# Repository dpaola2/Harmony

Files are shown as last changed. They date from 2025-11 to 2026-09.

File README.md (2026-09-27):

# Offline MP3 Player (Harmony2)

Hardware-agnostic MP3 player core with a PC simulator and ESP32 targets. See `docs/README.md` for the doc map; hardware bring-up for Prototype 1 is in `hardware/prototype1/README.md`.

## Current Mark-6 build

The active player uses native ESP-IDF firmware on the Adafruit ESP32 Feather V2. The Python/MicroPython architecture below is retained historical context.

- [Feather bench firmware and instructions](firmware/mark-6/feather-player-bench/README.md)
- [Native UI and renderer](firmware/mark-6/feather-carrier/main/)
- [UI requirements and completion status](docs/Harmony-player-ui-requirements.md)
- [Desktop UI prototype](platforms/pc/ui/README.md)
- [Preserved Mark-7 visual reference](docs/mark-7-design-reference.md)
- [Changelog](CHANGELOG.md)

## Architecture & Goals
- Core app logic in Python, shared by PC simulator and MicroPython on ESP32.
- iPod-style UI: Library → Now Playing → Settings with tactile buttons (no touch).
- Portable storage (SD) and Bluetooth audio on hardware targets; PC sim for fast iteration.
- More context: `PROJECT_OVERVIEW.md` (goals/constraints) and `PLAN.md` (roadmap).

## Development
- **Environment (macOS)**:
  - Install Homebrew if missing: `/bin/bash -c "$(curl -fsSL https://raw.githubusercontent.com/Homebrew/install/HEAD/install.sh)"`.
  - Python: `brew install python` (or `pyenv` if you prefer pinned versions).
  - Recommended tooling: `pipx install uv` (or `pip install uv` in a venv); `pipx ensurepath`.
  - Create venv: `python -m venv .venv && source .venv/bin/activate`.
  - Install dev deps: `python -m pip install --upgrade pip uv pytest`.

- **Run PC simulator** (console UI):
  ```bash
  source .venv/bin/activate
  python -m platforms.pc.main_pc [--music-dir /path/to/Artist/Album/Track.ext]
  ```
  Controls: `w/s` up/down, `a` left, `d` right, `space`/Enter select, `p` play/pause, `b` or `q` back, `x` quit, `+`/`=` volume up, `-` volume down. Defaults to an in-memory demo library.

- **Tests**:
  ```bash
  source .venv/bin/activate
  pytest
  ```
  (Targets `core/` behavior.)

- **ESP32 Prototype 1 upload (demo UI, no buttons required)**:
  - See `hardware/prototype1/README.md` for wiring and flashing details.
  - Convenience script from repo root:
    ```bash
    scripts/upload_proto1_demo.sh /dev/tty.usbmodem*   # adjust port as needed
    ```
    It copies `core/`, `platforms/esp32/*.py`, and `main_esp32.py` to the board and keeps `main.py` as entrypoint.

## Repo structure
- `core/` hardware-agnostic logic and models
- `platforms/pc/` PC simulator (console screen, keyboard input, audio backend)
- `platforms/esp32/` ESP32 adapters (screen, buttons, audio)
- `hardware/` wiring/board notes (prototype phases)
- `enclosure/` mechanical notes
- `tests/` pytest cases for `core/`

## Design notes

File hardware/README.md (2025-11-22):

# Hardware Notes

## Prototypes
- Prototype 1: ESP32-S3-WROOM DevKitC-1 v1.1, SD SPI, ST7789V2 (1.69", 240x280), basic buttons, USB power. No audio/A2DP (S3 WROOM lacks classic BT); focus on UI/SD/display.
- Prototype 2: ESP32-WROVER DevKitC (PSRAM, classic BT) for audio/A2DP; SD SPI, ST7789 (2.0–2.4"), rotary encoder + buttons, optional I2S DAC/amp; USB or LiPo/TP4056 later.

## Volume Input Options
- Buttons: dedicated volume up/down buttons produce relative events; core clamps 0–100 and calls `set_volume`.
- Encoder-as-volume: use a second rotary (or mode switch) to emit relative steps; map to the same core events.
- Absolute knob (potentiometer): yields an analog value; platform adapter should translate ADC reading to a clamped 0–100 and push into core via `set_volume` (core supports absolute level set).

## Power System
- Battery: LiPo 1000–2000 mAh flat cell.
- Charging: TP4056 (USB-C variant) for LiPo charging.
- Regulation: ESP32 dev board regulator or MT3608 step-up if 5V needed for peripherals.
- Power switch: SPDT slide/lockable on/off.
- Optional: battery voltage sensing via ADC for future battery UI; plan GPIO and resistor divider.

## Notes/Next Steps
- Wiring: document GPIO mapping for encoder, buttons, SD (SPI), display (SPI), and optional I2S pins.
- Bluetooth A2DP: confirm ESP32 MicroPython support vs ESP-IDF shim; may need C-extension for stable source mode.
- Settings persistence: volume, last track, etc., stored in flash/SD (JSON) on device; core ready once adapters persist/load.

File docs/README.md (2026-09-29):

# Documentation Map

This repo keeps a small set of living docs, each with a clear purpose. Use this map to find or add information without duplicating content.

## September 2026 device proposal

- [Firmware baseline](../firmware/README.md): verified ESP32/SAMD builds, scripts, source pins, and hardware validation limits.
- [Board reconciliation](../hardware/procurement/reconciliation/tangara-interface-bom-reconciliation.md): PCB component inventory and exact battery/display interfaces.

- [Shopping list](../hardware/procurement/README.md): current sources, quantities, costs, and compatibility holds.
- [Implementation plan](Harmony-2026-implementation-plan.md): stages, review decisions, and acceptance tests.

- [Approach reassessment](Harmony-2026-reassessment.md): recommendation against the updated device goals.
- [Technical basis](Harmony-2026-technical-basis.md): options, architecture, sourcing limits, and acceptance criteria.
- [Printable case](../enclosure/harmony-r1/README.md): Tangara-based fit prototype for the Bambu A1.

## Current Mark-7 scope

- [Portable build scope](mark-7-portable-scope.md): adopted September 28 reuse, internal SD access, perfboard assembly, power work and acceptance.

## Current player UI

- [Mark-6 lessons and portable next step](mark-6-lessons-and-portable-next-step.md): battery proof, carrier tradeoffs and proposed Mark-7 purpose.

- [Changelog](../CHANGELOG.md): dated implementation, fixes and validation.
- [Mark-7 visual reference](mark-7-design-reference.md): frozen desktop appearance and capacitive-wheel/battery design direction.

- [Native Feather UI bench](../firmware/mark-6/feather-player-bench/README.md): device music tree, Now Playing, controls, and current limits.

- [Interactive desktop prototype](../platforms/pc/ui/README.md): run the 320 × 480 menu and wheel simulation using the 45-track trial library.
- [Player UI requirements](Harmony-player-ui-requirements.md): Accepted Mark-6 scope (HARMONY-18), covering music navigation, controls, volume, and Bluetooth management on the verified Feather bench.

## Core docs
- `PROJECT_OVERVIEW.md` — why the project exists, constraints, and hardware/software goals.
- `PLAN.md` — roadmap and near-term milestones; keep current sprint items at the top.
- `TASKS.md` — live task queue and in-flight gameplans (per callsign).
- `docs/gameplans/` — archived or long-form gameplans by callsign (move sections here once done or if they get lengthy).
- `AGENTS.md` — roles, responsibilities, and collaboration rules. Update only when roles change.

## Platform & hardware
- `platforms/pc/` — PC simulator code; add a `README.md` here if setup diverges from the root README.
- `platforms/esp32/` — MicroPython adapters for ESP32 targets.
- `hardware/prototype1/README.md` — Prototype 1 wiring, bring-up, and testing (ESP32-S3 DevKitC-1 v1.1).
- `hardware/prototype2/README.md` — Prototype 2 notes (WROVER/audio) when ready.
- `hardware/production/` — production-focused notes and (later) BOM/PCB details.
- `enclosure/` — mechanical/3D-print notes.

## Testing & running
- Root `README.md` — quickstart for macOS dev setup, how to run the PC simulator, and how to run tests.
- Platform-specific run/test steps live in the relevant platform or hardware README (e.g., `hardware/prototype1/README.md` for flashing and device tests).

## How to handle gameplans and tasks
- Active gameplans: keep with their callsigns in `TASKS.md` so they are visible during execution.
- Short-term roadmap: keep in `PLAN.md` and cross-link to detailed gameplan sections in `TASKS.md`.
- Archive: move completed/obsolete task or gameplan sections from `TASKS.md` into `docs/gameplans/<callsign>.md`, noting the callsign and date if helpful.
- Long-form design notes: if a gameplan gets large, place it under `docs/gameplans/<callsign>.md` and link it from `TASKS.md` and `PLAN.md`.

## Cross-linking
- Each doc should include brief “see also” pointers to adjacent docs (e.g., `README.md` → `PLAN.md`, `TASKS.md`, relevant platform README).
- Avoid duplicating content; link instead. Keep summaries at the top of each doc to speed up navigation.

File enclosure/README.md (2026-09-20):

# Harmony enclosure

The [Harmony R1 case](harmony-r1/README.md) contains printable STL and 3MF parts, editable CAD, assembly instructions, and validation results for the proposed Tangara-based device. Start with the fit-test plate.

See the [September 2026 approach reassessment](../docs/Harmony-2026-reassessment.md) before sourcing electronics. The case is a digital fit prototype; physical validation is pending.

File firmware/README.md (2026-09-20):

# Harmony firmware baseline

On September 14, 2026, the unmodified Tangara ESP32 application, SAMD21 application, and SAMD21 bootloader all built successfully on Dave's Mac. The ESP32/SAMD register maps and control bits match at source level. This removes a build-toolchain uncertainty in the proposed Tangara approach. It does not establish that an assembled Harmony works.

| Build | Source pin | Result |
| --- | --- | --- |
| ESP32 application and IDF bootloader | `c092c5aae83aac241b3756b15d8b9dad9ed2c3fd`; ESP-IDF `8c750b088c7cd857d079c0eeb495da199b359461` | Passed; application 2,684,736 bytes, 36% partition space free |
| SAMD21 application v6.0 | `8066c54bff5d26398fa08955d2bc24e7f05702a2` | Passed; BIN, ELF and UF2 retained |
| Tangara SAMD21 bootloader | `bc1632d9736493467000ba119fd0b16fd46ccbe6` | Passed; raw factory image and existing-device updater retained |

Read the [ESP32 verification](esp32-validation/README.md) and [SAMD21 verification](samd-validation/README.md) for build commands, compiler versions, logs, hashes, and programming requirements. Both source checkouts remain unmodified. Toolchains are isolated under `firmware/toolchains`; no serial-port or flash commands were run. The existing Python simulator was not changed or retested.

Sol subagents built/reviewed the SAMD baseline and reconciled the board interfaces while the primary agent built the ESP32 baseline. The primary review caught and corrected build-script failure handling and checksum regeneration before accepting the SAMD deliverable.

## What this establishes

The ESP32 image checksum is valid; all seven ESP32 flash images fit the configured 16 MiB device without overlap. SAMD v6.0 and the ESP32 driver share I2C address `0x45`, registers 0–5 for version/status/control, and matching shutdown, fast-charge, mass-storage and UF2-reset bits. The SAMD application starts at `0x2000`, after the 8 KiB bootloader region. A blank SAMD still needs initial programming through SWD; the updater UF2 does not replace that step.

Clean builds and an ESP32 script invocation passed. The scripts pin source revisions and preserve the tested configuration. They are not proof of byte-identical clean rebuilds across hosts. The ESP32 build produced 29 compiler warnings, including an ALAC metadata-bounds finding tracked as HARMONY-12; the unmodified baseline retains that finding for a focused review before qualification.

## Hardware preparation

The [board reconciliation](../hardware/procurement/reconciliation/tangara-interface-bom-reconciliation.md) documents battery J7 circuit order, charger requirements, display pinout, and the routed-board component inventory. The old schematic audit contains reference collisions and repeated units and must not be used as an ordering BOM. Display electrical pinout matches, but mechanical drawing overlay remains unresolved. Battery finished dimensions, thermistor characteristics, wiring, and allowable charge rate remain unresolved.

Next engineering work is to turn the routed-board inventory into the reviewed assembly BOM and placement package, obtain the missing display and battery drawings, then prepare the quote with the now-known programming artifacts. No supplier contact, purchase, or fabrication release has occurred. Hardware acceptance still requires actual power/USB checks, playback, Bluetooth pairing and reconnect, touch-wheel operation, pocket reception, and measured runtime. Live work is tracked in HARMONY-9, HARMONY-10, HARMONY-11, and HARMONY-12.

## Local preservation

The [source archive manifest](source-archives/manifest.json) records tar archives of all tracked source files and recursive submodules, including the pinned ESP-IDF sources and upstream licenses. Archives omit Git history, downloaded compiler binaries, caches, and generated build trees. The source archives support local inspection; the supplied build scripts expect Git checkouts and download tools when bootstrapping. They are not an offline installer. Build outputs, logs, configurations, and scripts are preserved separately.

This baseline is also copied into the Harmony vault deliverables as a new dated package. The original R1 case/design snapshot remains unchanged.

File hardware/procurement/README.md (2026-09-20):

# Harmony shopping list

**R3 engineering update:** [Current quote package](assembly-quote-r3/README.md) and [independent review](../reviews/harmony-r3/REVIEW.md) include verified power, touch-electrode and jack corrections. All 567 pin connections agree; current board geometry is identified by the R3 manifest. USB connector thickness/edge fit, wheel artwork and one thermal relief remain open under HARMONY-15. Earlier packages below are historical evidence.

**R2 circuit correction:** [Updated quote package](assembly-quote-r2/README.md) incorporates the independently verified schematic/library correction. All 567 electrical pin/net assignments agree with the unchanged PCBs. [R2 review](../reviews/harmony-r2/REVIEW.md) records the remaining manufacturing and power-model findings under HARMONY-15. Use R2 for further engineering review; fabrication remains on hold.

**September 14 assembly quote package:** [Per-board BOMs, placements, fabrication and programming files](assembly-quote/README.md) now reconcile to the routed boards. [Independent review](assembly-verification/REVIEW.md) records the checks and unresolved schematic/PCB discrepancy. Use these per-board BOMs for quote review. Fabrication remains on hold; the immediate circuit follow-up is HARMONY-14.

**September 14 engineering update:** [Board interface and component reconciliation](reconciliation/tangara-interface-bom-reconciliation.md) replaces raw schematic-row counting with a routed-PCB inventory and records battery wiring/charge requirements and the matched display electrical pinout. The schematic audit is not an ordering BOM. [Firmware baseline builds](../../firmware/README.md) now pass; physical fit and supplier requirements remain open. Prices below were observed September 13 and have not been refreshed by this engineering update.

Prepared September 13, 2026, for HARMONY-9. Review draft for one working player, with a proposed second set of electronics as a repair spare. US delivery and USD are assumed. Nothing has been ordered or submitted to a supplier.

The practical route is to quote fully assembled Tangara mainboards and faceplates, then buy the external fittings. The small parts are straightforward; the board assemblies and battery determine whether this is a sensible build. [Implementation plan](../../docs/Harmony-2026-implementation-plan.md).

## What to order, and when

| Item | Installed / proposed purchase | Source and observed price | Availability and release condition |
| --- | --- | --- | --- |
| Tangara mainboard PCBA | 1 / quote 1, 2, and 5 | [PCBWay assembly](https://www.pcbway.com/Order/QuickOrderOnline); price requires quote | No stocked assembled board found. Quote all fitted components, connectors, programming, and inspection. Prefer 2 if the incremental cost is reasonable. |
| Tangara faceplate PCBA | 1 / match mainboard quantity | Same PCBWay quote; [pinned sources](../tangara-reference/README.md) | Include display and haptic mounting. The mainboard and faceplate are separate assemblies, not one orderable module. |
| Protected battery with temperature sensing | 1 / quote sample lot of 5 | [LiPol LP574459, 2,000 mAh](https://www.lithium-polymer-battery.net/lithium-polymer-battery-lp574459-2000mah-3-7v-7-4wh-with-pcm-and-ntc-and-wires/); price requires quote | Candidate only. Vendor lists a five-piece sample minimum; stock, finished pack dimensions, connector, NTC curve, and US shipping are unconfirmed. See battery decision below. |
| Display, bare solder-tail panel | 1 / 2 if supplied separately | [EastRising ER-TFT018-4](https://www.buydisplay.com/1-8-inch-128x160-tft-lcd-display-4-wire-spi-st7735s-soldering-type-fpc), $1.87 each, $3.74 for 2 | Listed in stock. Prefer assembler procurement and mounting. Confirm current drawing against faceplate and case before release. Do not buy an SPI breakout with its own PCB. |
| Haptic motor | 1 / 2 if supplied separately | [Vybronics VC1034B018F at DigiKey](https://www.digikey.com/en/products/detail/vybronics-inc/VC1034B018F/6009914), $2.94 each, $5.88 for 2 | Listed in stock. Upstream BOM names this ERM alternative. Verify physical clearance and set the driver for the chosen motor. Prefer assembler mounting. |
| Board ribbon cable | 1 / 2 | [Samtec FJH-15-R-03.00-4 at DigiKey](https://www.digikey.com/en/products/detail/samtec-inc/FJH-15-R-03-00-4/7254685), $2.60 each, $5.20 for 2 | Listed in stock. Exact upstream option: 15 conductors, 0.5 mm pitch, 76.2 mm length, opposite-side contacts. Confirm tin contact finish from the ordered part drawing. |
| M2 female/female standoffs, 6 mm | 4 / 10 | [Würth 970060244 at DigiKey](https://www.digikey.com/en/products/detail/w%C3%BCrth-elektronik/970060244/9488532), $3.80 for 10 | Listed in stock. Exact upstream part, 4 mm hex body. A 10-pack covers two devices and two spares. |
| M2 × 14 mm countersunk screws | 4 / 20 | [Prime-Line 9120640 at Zoro](https://www.zoro.com/prime-line-machine-screw-metric-flat-head-phillip-drive-m2-04-x-14mm-a2-70-stainless-steel-10pk-9120640/i/G400921384/), $9.58 minimum | $4.79 per 10, sold in multiples of two packs. Listing price verified; stock/dispatch not exposed. DIN 965 Phillips alternative. Test head seating in the coupon before buying more. |
| M2 × 8 mm countersunk screws | 4 / 10 | [Prime-Line 9120618 at HD Supply](https://hdsupplysolutions.com/ProductDisplay?productId=1897003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), $7.29 per 10 | Sign-in required for availability. Same DIN 965 family. The manufacturer direct listing is out of stock; this is a conditional supplier, not confirmed inventory. |
| Clear screen lens material | 1 lens / 1 sheet | [RJ Speed RJS1502 at Hobby Etc](https://store.hobbyetc.com/parts/view/70596), $4.99 | Orderable listing; no stock count. Clear polycarbonate, 8 × 12 inches, nominal .020 inch (0.508 mm). Cut to 39.6 × 34.4 mm, deburr, and measure thickness before fitting. |
| Storage | 1 / 1, or reuse | [SanDisk SDSDUVQ-064G-GN6IN, 64 GB full-size SDXC at B&H](https://www.bhphotovideo.com/c/product/1945432-REG/sandisk_sdsduvq_064g_gn6in_64gb_ultra_uhs_i_sdxc.html), $23.99 | Listed in stock on the product page. Its older replacement page shows $38.95; use the live product/cart price. Full-size SD fits the socket without an adapter. Validate the chosen filesystem in firmware. |
| USB data/charging cable | 1 / reuse, or 1 | [Adafruit 4474, USB-A to USB-C, 1 m](https://www.adafruit.com/product/4474), $4.95 | Listed in stock. Useful for bench flashing and legacy USB power. Also use an existing C-to-C data cable to verify modern USB-C charging in both orientations. |
| Filament | About 46 g including coupons / reuse at least 150 g | [Bambu PLA Basic](https://us.store.bambulab.com/products/pla-basic-filament), listed **from $19.99/kg** | Color and spool/refill selection change price and stock. One color is enough. Reserve material for reprints; no AMS required. Buy PETG only after the fit print passes. |
| Lens tape and battery retention | Small amount / reuse or one supply pack | Thin electronics repair tape for the lens; removable battery pull-tab adhesive for the pack. Supplier/package selection pending. | **$10–20 planning allowance**, not a verified price. Measure adhesive thickness in the stack. Avoid thick foam behind the lens or a glued-in battery with no removal path. |
| Insulating touch cover | 1 / print 2 | [Included touch-cover STL](../../enclosure/harmony-r1/print/touch-cover.stl) | Print at nominal 0.6 mm. If touch testing fails, quote a copper-free 0.6 mm FR4 cover matching the Harmony circular outline. The older stock cover outline is not assumed to fit. |
| Enclosure and fittings | 1 complete set / print after battery selection | [A1 print package](../../enclosure/harmony-r1/README.md) | Front, back, cover, two button caps, hold slider, SD caddy, battery guides. The existing battery envelope is a reference, not a verified purchased pack. |

The proposed separately purchased display, motor, ribbon, standoffs, screw packs, lens sheet, SD card, and USB cable total **$69.42 before shipping and tax**. That subtotal mixes confirmed-stock and conditional listings as marked above. It excludes both PCBAs, battery, filament, adhesives, tools, and any import charges. If the assembler supplies the two displays and motors, remove $9.62 from the separate shopping basket and include those costs in the PCBA quote instead. Reusing an SD card and USB cable removes another $28.94.

For review, reserve **$600–900 for the prototype effort**, including two board sets, a small battery sample lot, small parts, shipment costs, and one round of rework. This is a spending allowance proposed by the assistant, not a supplier estimate or an approved budget. The actual total is the PCBA quote plus the battery quote plus the selected shopping basket and consumables, with freight/tax added once. Reassess the route if the quotes exceed that allowance before treating purchases as committed.

## Battery decision

The original BOM says “3-pin 2200mAh 604560” and “EcoCell LIP2-001,” but those identifiers do not currently describe the same product. [LIP2-001 now lists a 2,000 mAh 113450 three-wire cell](https://ecocell.com.au/product/lipo-2000-113450-3w/). The [2,200 mAh 604560 is LIP2-200](https://ecocell.com.au/product/lipo-2200-604560/) and has two wires with no thermistor. Neither is a verified direct replacement for this build. Preserve the original BOM as historical source, but do not order its battery line blindly.

The preferred quote candidate is **LP574459 with protection, a 10 kΩ NTC, and a JST-manufactured PHR-3 cable assembly** wired to match Tangara J7. Its advertised **cell** dimensions are 5.7 × 44 × 59 mm. Those are not the maximum finished **pack** dimensions. Protection PCB, seams, adhesive, cable exit, and tolerances may still require a revised cage or deeper rear shell. Ask for the complete dimensioned pack drawing and NTC resistance/temperature table. The vendor says five samples are the minimum when stock is available; out-of-stock production quantities would be unsuitable for this one-off project. [Manufacturer listing](https://www.lithium-polymer-battery.net/lithium-polymer-battery-lp574459-2000mah-3-7v-7-4wh-with-pcm-and-ntc-and-wires/)

If samples are unavailable, a domestic fallback is [Adafruit 2011](https://www.adafruit.com/product/2011), **$12.50, listed in stock**, 2,000 mAh and 60 × 36 × 7 mm. It requires a deeper/revised battery compartment and an engineered temperature-sensing harness; it is not a plug-in substitute. [Semitec 103AT-2](https://www.digikey.com/en/products/detail/semitec-usa-corp/103AT-2/16579059), $0.68, and [Adafruit JST-PH three-pin cable 3893](https://www.adafruit.com/product/3893), $1.25, are available harness candidates. Their charger thresholds, physical mounting, insulation, and pin order need electrical review before use. Leave this fallback out of the initial cart. A fixed resistor in place of a temperature sensor is not the proposed final configuration.

A 2,000 mAh pack with 80% assumed usable capacity requires **80 mA average battery current** for 20 hours of playback. At 100 mA it gives 16 hours under that assumption. We will measure actual runtime; a battery label and Tangara's advertised listening time do not establish Bluetooth endurance.

## What belongs in the board quote

Buy the assemblies as complete boards. Do not separately order chips unless the assembler requests consigned parts. The following checks establish that several important ICs remain obtainable; they do not establish availability of every resistor, connector, or protection part.

| Circuit | Exact source MPN | Supplier evidence |
| --- | --- | --- |
| Bluetooth/audio processor | ESP32-WROVER-E-N16R8 | [DigiKey](https://www.digikey.com/en/products/detail/espressif-systems/ESP32-WROVER-E-N16R8/11613135): active, stock listed, $6.32 at quantity 1 |
| USB/power coprocessor | ATSAMD21E18A-AF | [DigiKey](https://www.digikey.com/en/products/detail/microchip-technology/ATSAMD21E18A-AF/5057222): stock listed, $4.35 at quantity 1 |
| Capacitive wheel | AT42QT2120-MMH | [DigiKey](https://www.digikey.com/en/products/detail/microchip-technology/AT42QT2120-MMH/3608499): stock listed, $1.74 at quantity 1 |
| Wired audio DAC | WM8523GEDT/R | [DigiKey](https://www.digikey.com/en/products/detail/cirrus-logic-inc/WM8523GEDT-R/5036729): stock listed, $2.95 at quantity 1 |
| Headphone amplifier | INA1620RTWR | [DigiKey](https://www.digikey.com/en/products/detail/texas-instruments/INA1620RTWR/9555498): stock listed, $8.79 at quantity 1 |
| Charger and power path | MCP73871-2CCI/ML | Exact part is in the pinned schematic. Assembler must confirm the 4.2 V ordering suffix and availability; no voltage-variant substitution. |

USB-C receptacle USB4510-03-1-A, SD socket DM1AA-SF-PEJ(82), FFC connectors, battery header S3B-PH-K-S(LF)(SN), switches, haptic driver DRV2605LDGST, and every passive/protection part remain in the assembly scope. Preserve RF antenna clearance and original mounting-hole/connector positions. [Schematic audit](schematic-parts-audit.json) is an inspection aid; it is not a manufacturing BOM.

[PCBWay](https://www.pcbway.com/Order/QuickOrderOnline) is the first quote route because Tangara's designer says it built the original production batch. Obtain a comparison from [JLCPCB assembly](https://jlcpcb.com/pcb-assembly) if sourcing or setup charges are unfavorable. The designer specifies **1.6 mm mainboard and faceplate, ENIG**. The pinned mainboard has four copper layers; confirm each board's own stack-up. [Designer production discussion](https://forum.cooltech.zone/printthread.php?tid=227), [May 2026 files and specifications](https://forum.cooltech.zone/showthread.php?pid=1466).

The production attachment linked by the designer returned a login/permission page during retrieval. It has not been obtained or checked against our pinned sources. The RFQ brief identifies the files still needed before an actual quote submission. [Supplier briefs](supplier-briefs.md).

## Tools and reuse

The A1 is confirmed owned. Reuse the Mac, USB charger, C-to-C cable, SD reader, headphones, and SD card where available; ownership of those accessories has not been checked. The Olimex and S3 development boards and the small Adafruit display do not go inside this Tangara-based enclosure. Do not buy the old VS1053 breakout for this plan.

Physical work needs a digital caliper, multimeter, suitable precision screwdriver, fine tweezers, and a small file/deburring tool. A soldering station with flux and magnification is needed only if display/motor/harness work is not included in the assembly order. Borrow tools or inventory what is on hand before buying a bench setup.

Request factory installation of the SAMD bootloader and the compatible application/ESP32 firmware. If programming is excluded, select a supported 3.3 V SWD debugger and the exact header/probe arrangement during the firmware stage. A USB cable alone cannot initialize a blank SAMD. Battery runtime can be tested by elapsed playback; detailed optimization also needs a battery-side current logger. A USB input power meter does not measure battery playback consumption.

## Review record

Evidence is from supplier pages retrieved for this review, not live reservations or checkout quotes. Some search indexes carry older captures; stock counts change, so the list reports stock status rather than pretending counts are reserved. Unit prices exclude shipping, taxes, and possible tariffs. The full landed total remains open until the two custom quotes arrive.

The prose uses the engineering-memo register established in the preceding reassessment. The purchase table carries the detail so the decision can stay short. Final review checks: distinct installed versus purchased quantities, no double-counted PCBA components, no unconfirmed stock labeled available, and no battery/case compatibility claim based only on nominal dimensions.

## Cross-references

- [Implementation plan](../../docs/Harmony-2026-implementation-plan.md)
- [Approach reassessment](../../docs/Harmony-2026-reassessment.md)
- [Case and assembly guide](../../enclosure/harmony-r1/README.md)
- [Electronics sources and license](../tangara-reference/README.md)
- HARMONY-9; HARMONY-8; historical purchase task HARMONY-7

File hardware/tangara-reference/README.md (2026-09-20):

# Tangara electronics reference for Harmony

Proposed hardware foundation, captured September 13, 2026. Read [Harmony's reassessment](../../docs/Harmony-2026-reassessment.md) before treating this as an adopted replacement for the prior hardware plan.

The KiCad schematic, PCB, symbol, and footprint sources are copied from Cool Tech Zone's [tangara-hw repository](https://codeberg.org/cool-tech-zone/tangara-hw), commit `9853b4a1dc8a0e3ea3ec75450522e42df12eaa52`. They are unchanged. Optional 3D libraries, editor state, caches, backup files, and generated XML netlists are omitted. [source-lock.json](source-lock.json) records the source. Retain the upstream [LICENSE](LICENSE), CERN-OHL-S-2.0, with derivatives.

The reference includes the mainboard, faceplate, and touch-cover PCB. The 0.6 mm touch-cover PCB is an insulating face cover; the capacitive electrodes and controller are on the faceplate. The Harmony case also includes a printable cover experiment.

These files are not an approved manufacturing package. No ERC/DRC, component substitution review, fabrication quote, or assembly order has been completed in this session. Generate manufacturing outputs from a reconciled board revision after checking part availability. In May 2026, the original designer supplied production files and noted that some components might have been discontinued. [Manufacturing discussion](https://forum.cooltech.zone/showthread.php?pid=1466)

For an assembly quote, include both boards at the correct stack-up and 1.6 mm nominal thickness, the upstream surface finish, BOM and placement data, display mounting, haptic motor, and programming requirements. The mainboard is a four-copper-layer design in the checked-out PCB. Confirm the faceplate and touch-cover stack-ups independently. Ask the assembler to flag every unavailable component or substituted connector before manufacture. Procurement prices and lead times have not been verified.

The current firmware candidate inspected is [tangara-fw](https://codeberg.org/cool-tech-zone/tangara-fw), commit `c092c5aae83aac241b3756b15d8b9dad9ed2c3fd`. It uses ESP-IDF and native code, with Lua UI scripts. Read its `BUILDING.md` and use its pinned submodules. The separate [SAMD firmware](https://codeberg.org/cool-tech-zone/tangara-samd-fw) must be selected as a compatible pair; this session has not frozen, built, or flashed that pair. USB storage in the inspected UI requires SAMD application version 3 or newer.

New boards need the SAMD bootloader installed through SWD before ordinary USB programming is available. Obtain a compatible SWD programmer and probe, or include initial programming in the assembly quote. Verify both firmware images, audio playback, charging, low-battery behavior, and switch inputs before fitting the printed case.

For current sourcing, use the [Harmony shopping list](../procurement/README.md). It records the battery identifier mismatch in the historical BOM and keeps unverified replacements on hold.

## Cross-references

- [Original BOM](BOM.md), historical names and sourcing gaps retained
- [Complete enclosure fit prototype](../../enclosure/harmony-r1/README.md)
- [Manufacturer electronics description](https://cooltech.zone/tangara/docs/electronic-design/)
- HARMONY-8

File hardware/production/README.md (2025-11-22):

# Production Profile

- Goal: final hardware set with rotary encoder, full button set, battery/power, enclosure mounts, and optional I2S audio.
- BOM: ESP32-WROVER module/dev board, ST7789 display, rotary encoder (EC11), tactile buttons, MicroSD SPI, LiPo (1000–2000 mAh), TP4056 (USB-C), optional I2S DAC/amp.
- Power: battery + charging/regulation; plan switch and battery sensing.
- PCB: to be captured under `hardware/pcb/` when ready.
- Enclosure: note mounting points and connector cutouts.
- Notes: define final GPIO map, connector types, and cable lengths.***

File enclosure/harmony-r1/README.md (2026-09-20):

# Harmony R1 printable enclosure

Complete enclosure fit prototype for the proposed Tangara-based Harmony. Designed for a Bambu A1 with a 0.4 mm nozzle. Electronics must match the pinned Tangara mainboard and faceplate. This is not a case for the Olimex development board or the Adafruit 1.14-inch breakout.

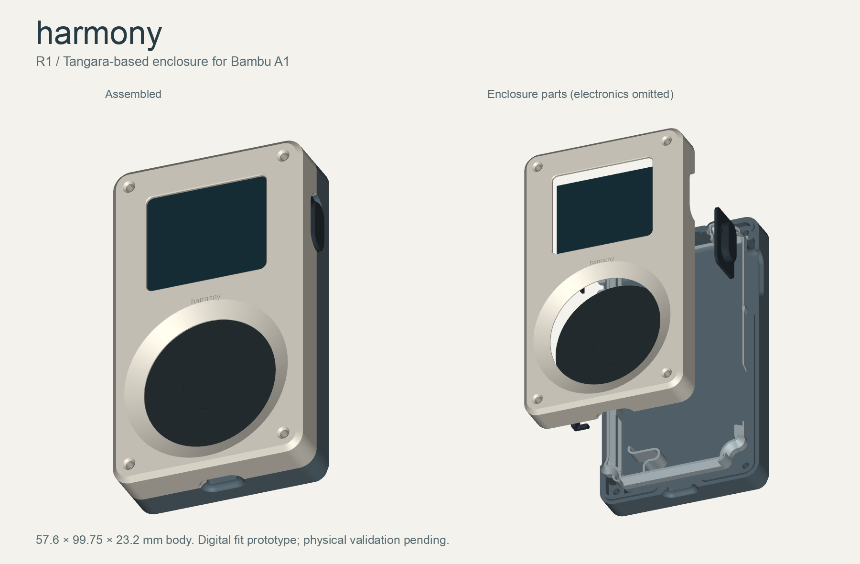
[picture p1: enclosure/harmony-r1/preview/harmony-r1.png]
CAD preview


Open [harmony-shells.3mf](print/harmony-shells.3mf) in Bambu Studio for the front and back. Open [harmony-small-parts.3mf](print/harmony-small-parts.3mf) for the fittings, cage, and cover. Start with [harmony-fit-test.3mf](print/harmony-fit-test.3mf). These are millimeter geometry files with parts placed on the bed. They contain no printer instructions. Select your A1 and filament, inspect the sliced preview, then print.

## Design and fit

The shell body is 57.6 mm wide, 99.75 mm tall, and 23.2 mm deep. Side controls extend beyond that width. The internal interface comes from Tangara's Rev-03b printing exports: 0.3 mm PCB clearance setting, 2.4 mm screw holes, and the upstream mating lip. The shell wall is nominally 2.5 mm. This is a compact, thick player rather than the thin final iPod Classic.

Harmony adds a 1 mm exterior reinforcement to the original rear floor, making the central floor 2 mm thick. The battery cavity stays unchanged. Both shells carry recessed Harmony lettering; the rear also has shallow grip grooves. The additional rear material recesses the original screw countersinks by 1 mm. Use the original screw lengths and a driver that reaches the recess.

The circular cover has a shallow center-ring groove and a matching 44.4 mm retaining pocket in the front shell. That pocket resolves an interference between the older cover model and the newer front-shell export.

The front and back have the original USB-C, headphone, side-button, hold-switch, and SD openings. The battery cage uses the upstream outer locating surfaces, with the spring preload removed and thin ties joining the guides outside the reference battery envelope. Secure the pack with removable battery pull-tab adhesive on the rear floor. The printed guides must not squeeze the pouch. A removable touch cover keeps the sensing surface replaceable. The front corner fasteners remain visible for service access.

All STL files are oriented for printing. STEP files preserve assembly coordinates and should not be sent to a slicer as a single fused object. [enclosure-assembly.step](cad/enclosure-assembly.step) includes the fitted enclosure and a reference lens. It omits the electronic assemblies, screws, and battery.

## Printed parts

| File | Quantity | Purpose |
| --- | --- | --- |
| `front.stl` | 1 | Front shell with screen and wheel openings |
| `back.stl` | 1 | Reinforced rear shell |
| `touch-cover.stl` | 1 | Continuous insulating disk over ring and center sensor |
| `button-upper.stl` | 1 | Upper side-button cap |
| `button-lower.stl` | 1 | Lower side-button cap |
| `hold-switch.stl` | 1 | Captive hold-switch slider |
| `sd-caddy.stl` | 1 | Removable SD-card fitting |
| `battery-cage.stl` | 1 | Passive battery guides derived from the batch-1 cage |
| `fit-front.stl`, `fit-back.stl` | 1 each | Corner samples with mating lip and screw access |

The shell and most fittings derive from Cool Tech Zone's open Tangara design. This package contains original CAD sources, editable Harmony modifications, and regenerated exports. It is not an independently designed electrical or mechanical platform. See [sources.json](source/sources.json) for exact source paths and [LICENSE](source/LICENSE) for CERN-OHL-S-2.0.

## A1 settings and first print

Use ordinary PLA for fit tests. PETG is a candidate for the carry case after fit validation. Avoid carbon-filled, metallic, or conductive material around the touch sensor and antenna. The preview's suggested finish is a warm-white front, gray back, and charcoal controls. Each part can print in one color; AMS is optional.

For the shells, start with the A1 0.4 mm nozzle profile, 0.16 mm layers, four walls, five top/bottom layers, and 15% gyroid infill. Keep the supplied exterior-face-down orientation. Start with automatic supports and review the screen lip, ports, and internal ledges; remove supports carefully before assembly. Do not assume a mesh validation proves support-free printability. Use a smooth plate if you want smooth exterior faces.

Print the small fittings at 0.12 mm layers. The new printed touch cover is 43.9 mm in diameter and 0.6 mm thick, with a 0.12 mm deep center-ring groove. Check that the slicer produces approximately 0.6 mm of solid plastic, with no sparse infill or omitted layers. Print it separately on a smooth plate and measure the result. Its touch sensitivity is untested in PLA or PETG. A 0.6 mm insulating FR4 cover cut to this revision's circular outline is the fallback if the printed disk is unreliable; check any stock cover's outline before using it; a printed disk does not replace the copper electrodes on the faceplate PCB.

The supplied mating-lip gap is only the upstream nominal clearance. Print the fit pair, clean the brim and first-layer flare, and join them by hand. If they require force, correct first-layer expansion or the lip clearance before printing the whole case. Do not scale the entire model: that also moves the PCB holes and ports. Small internal ledges make this fit test more useful than a generic printer cube.

Bambu Studio 02.08.02.61 successfully sliced all three plates with the A1 profiles and PLA Basic. Estimated time/material: shells 118 minutes / 38.48 g; small parts 29 minutes / 4.90 g; fit pair 20 minutes / 2.51 g. These are slicer estimates, including preparation, not measured prints. See [slicer-validation.json](slicer-validation.json) for input hashes and the saved settings under `verification/slicer-settings/`.

## Parts that are not printed

**Sourcing correction, September 13:** the upstream battery BOM combines mismatched identifiers. Read the [current shopping list](../../hardware/procurement/README.md) before buying a pack or printing the final rear shell. A sourced battery may require a cage/rear-shell revision; the existing CAD has not been changed by the sourcing review.

| Part | Specification or source |
| --- | --- |
| Mainboard and faceplate | Matched Tangara PCB assemblies, source revision pinned in `hardware/tangara-reference/source-lock.json` |
| Display | Faceplate-compatible EastRising ER-TFT018-4; confirm actual mechanical envelope against the older ER-TFT018-2 case reference before purchase |
| Screen lens | Clear plastic, 39.6 × 34.4 × 0.5 mm, secured with thin perimeter tape clear of the display. The thinner sheet clears the newer shell; trim/test without forcing the LCD |
| Battery | Protected 1S LiPo with matching three-wire connector and temperature sensing; physically match the batch-1 cage |
| Battery envelope | CAD pack envelope approximately 44.3 × 72.05 × 5.9 mm; cable/connector need additional space. Measure the sourced pack, including protection board and seams |
| Interconnect | 15-position, 0.5 mm pitch FFC; Samtec FJH-15-R-03.00-4 from upstream BOM |
| Standoffs | 4 × M2, 6 mm, Wurth 970060244 or mechanically identical |
| Front screws | 4 × M2 × 14 mm countersunk |
| Rear screws | 4 × M2 × 8 mm countersunk, as upstream |
| Haptic motor | Faceplate-compatible upstream part, included in the PCBA/final-assembly quote |
| Storage | SD card supported by the selected firmware; use a full-size SD adapter if choosing microSD |

The lens, electronics, fasteners, and battery cannot be replaced with printed plastic. The upstream BOM contains some older case-directory names and unresolved sourcing entries. Treat it as a reference and reconcile it against the chosen board revision before ordering.

## Assembly

Follow the [manufacturer's assembly guide](https://cooltech.zone/tangara/docs/assembly/) with power disconnected. Check the bare shell fit first. Seat the hold slider and side caps in their pockets, install the mainboard and standoffs, and connect the faceplate FFC in its specified orientation. Lay the insulating wheel cover over its electrodes and seat the lens without pressing on the display. Fit the front with its longer screws.

Install the matching battery cage and pack with removable pull-tab battery adhesive. Route the cable clear of the seam, screws, and switch travel. Verify connector polarity and temperature-sense wiring against the mainboard schematic. The cell must lie without compression; a case that needs screw force to close is a failed fit. Fit the back with the shorter screws and tighten gently into the metal standoffs. Check that both buttons return freely and the hold slider completes its travel. Install the SD caddy and test removal.

The case has no gasket, water-resistance claim, or validated drop rating. Check touch response, charging temperature, and Bluetooth reception in the assembled enclosure. The printed touch cover and physical tolerances are the first experiments, not settled properties.

## Rebuild and validation

From the Harmony2 root:

```sh
uv run --with cadquery==2.8.0 --with trimesh --with matplotlib enclosure/harmony-r1/build.py
```

The generator checks solid validity, positive volume, closed meshes, consistent winding, print bounds, and pairwise part intersections. Read [validation.json](validation.json) for results and any remaining interference. The checks do not simulate material shrinkage, switch travel under load, touch sensitivity, RF reception, battery safety, or print supports. Physical validation has not occurred.

The exact STEP inputs and original FreeCAD document are included under `source/`. The upstream notes warn that the original parametric FreeCAD file requires 0.21.x and may not recompute correctly in 1.x. Harmony's script uses the STEP solids and cached shape snapshots, so regeneration does not depend on recomputing that document. [build.py](build.py) is the editable source for this revision's modifications.

## Cross-references

- [Approach reassessment](../../docs/Harmony-2026-reassessment.md)
- [Electronics reference](../../hardware/tangara-reference/README.md)
- HARMONY-8

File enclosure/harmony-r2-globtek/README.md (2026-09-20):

# Harmony R2 GlobTek fit prototype

Print `print/harmony-globtek-fit.3mf` at 100% scale. It contains the new back, battery tray and a solid battery-size dummy. Reuse the R1 front that already fits. The plate contains geometry, not printer settings or G-code.

The back is 6 mm deeper, giving a nominal 29.2 mm assembled body thickness. Its upper seam and port geometry are preserved. Rear screw seats move down 6 mm, so fastening needs correspondingly longer screws of the original type; verify engagement before tightening.

The tray allows a 78 × 31 × 9.3 mm battery body. The separate clearance envelope is 79 × 32 × 10.5 mm. This is provisional clearance, not a manufacturer-qualified swelling allowance. Try the printed dummy first. Actual pack, electronics, wiring, padding and tray/pack retention still need dry fitting. Do not squeeze the battery to close the case.

`validation.json` records zero modeled part/clearance intersections, valid solids, watertight meshes and A1 bed bounds. Electronics are not included in these interference checks. The original R1 files are preserved.

Build with `uv run --with cadquery==2.8.0 --with trimesh python build.py`. Source geometry and licensing come from `../harmony-r1/source/`; derived from Cool Tech Zone Tangara under CERN-OHL-S-2.0. `sha256.json` records output hashes.

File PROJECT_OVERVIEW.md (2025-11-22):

Here’s a clear, actionable project plan for building your tactile-controlled, Bluetooth-streaming, offline MP3 player—very much iPod-inspired, based on ESP32 hardware, MicroPython, and a 3D-printed case.

---

# ✅ **1. Core Requirements**

**Functional**

* Offline MP3 playback from local storage (SD card or internal flash)
* Bluetooth **A2DP source** (i.e., ESP32 sending audio to headphones/speakers)
* Screen + GUI (non-touch)
* Tactile hardware controls (wheel or buttons)
* Good battery life, rechargeable (USB-C if possible)
* iPod-inspired navigation UI

**Hardware constraints**

* ESP32 variant with A2DP source support (not all do)
* Enough RAM/flash to decode MP3 + run GUI
* Separate audio codec DAC for high-quality analog playback (optional if Bluetooth only)
* Screen compatible with ESP32 SPI or parallel bus

---

# ✅ **2. ESP32 Hardware Recommendation**

To meet all requirements, you need an ESP32 variant with:

* Classic Bluetooth (required for A2DP source mode)
* Dual-core processor
* Enough flash/RAM
* Good MicroPython support

### ⭐ **Best choice: ESP32-WROVER module or dev board**

**Why:**

* Classic BT + BLE
* PSRAM (4–8 MB) — useful for audio buffers + UI
* Fully compatible with MicroPython
* Widely supported by A2DP source libraries

You can buy it as:

### 👉 **ESP32 WROVER Development Board**

* Easy USB connection
* Exposed GPIO
* Built-in PSRAM
* ~$12–18

### (OPTIONAL) Alternative if you want better audio playback:

**ESP32-LyraT** or **ESP32-LyraT-Mini**

* Specifically designed for audio
* Has dedicated DAC/codec chips
* Buttons + headphone jack + mic built in
* Good if you want *very* high audio quality
  Downside: bulky, not ideal for a pocketable walk device.

---

# ✅ **3. Audio Path Options**

### **A. Bluetooth only (simplest)**

Just stream A2DP → headphones. The ESP32 handles encoding internally.

**Pros:** Simple, no DAC needed
**Cons:** No wired headphone fallback

### **B. Bluetooth + wired headphone jack (recommended)**

Use a small I2S DAC board:

* **MAX98357A (I2S) → speaker/headphones**
* **PCM5102A (I2S)** → better quality, line-out/headphones

---

# ✅ **4. Storage Options**

You will need space for MP3 files:

### Best for this project:

* **MicroSD card module (SPI interface)**
  Simple and supports large storage (64+ GB with FAT32/exFAT).

---

# ✅ **5. Screen Recommendations**

For an iPod-like experience, you want:

* Small rectangular display
* Fast enough for smooth menus
* Good readability outdoors

### ⭐ **Best choice: 2.0–2.4” SPI IPS LCD (ST7789 driver)**

Example:
**2" ST7789 320×240 IPS SPI LCD**

**Why:**

* Fast SPI (up to 80 MHz)
* Beautiful colors + viewing angles
* Works well with MicroPython
* Cheap ($10–$15)

### Alternative:

**OLED 1.3" or 1.5" (SH1106/SSD1327)**

* Lower power, but lower resolution

---

# ✅ **6. Control Input Options (Tactile & iPod-like)**

You have two main paths:

---

## **Option A — Real scroll wheel (iPod-style)**

Use:

* **EC11 rotary encoder + push button**
  (very tactile, satisfying turn + click)
* Map rotation to menu navigation
* Map click to “select”

Add 3–4 auxiliary buttons:

* Menu/back
* Play/pause
* Next/previous (optional)

---

## **Option B — D-pad + buttons**

Simpler wiring:

* 5-way tactile switch
  (up, down, left, right, center click)
* Additional play/pause button

---

# ✅ **7. Power System**

For a pocketable MP3 player, you want:

### Battery

* **LiPo 1000–2000 mAh** (flat cell)

### Power management module

* **TP4056 charging board (USB-C version available)**
* **MT3608 step-up** (if your system needs 5V)
* Or a:

  * **LiPo + ESP32 built-in regulator** if using dev board

### Switch

* SPDT slide or lockable tactile on/off switch

---

# ✅ **8. Software Architecture (MicroPython)**

### **Major modules:**

1. **Filesystem + metadata**

   * Read SD card directory
   * Parse MP3 tags (ID3v1/v2)

2. **UI system**

   * Draw lists, now playing screen, settings
   * Input handler (rotary encoder or buttons)
   * Screen update loop (~30–60 Hz)

3. **Audio**

   * MP3 decoding (likely using built-in ESP32 codecs)
   * Bluetooth A2DP source library
   * Optional I2S DAC output handlers

4. **Power management**

   * Battery readout via ADC
   * Sleep mode + wake logic

5. **Settings persistence**

   * JSON file stored in flash (volume, last track, theme, etc.)

---

# ✅ **9. 3D Printed Enclosure**

Design considerations:

* Two-part clamshell with screw posts
* Front shell: screen window + wheel opening
* Back shell: battery compartment
* Side cutouts:

  * USB-C charging port
  * Power switch
  * Optional headphone jack
* Rear ventilation if using speaker
* Mounting posts for:

  * ESP32 dev board
  * Screen
  * Rotary encoder

You can prototype in **Fusion 360**, **Onshape**, or **FreeCAD**.

---

# ✅ **10. Shopping List**

### **Core Electronics**

| Component | Recommended Part | Notes |
| --- | --- | --- |
| Microcontroller | **ESP32-WROVER Dev Board** | Must have PSRAM |
| Display | **ST7789 2.0–2.4” IPS LCD** | SPI |
| Input Wheel | **EC11 rotary encoder w/ button** | iPod-like control |
| Aux Buttons | 6× tactile buttons | Menu, play/pause, etc. |
| Storage | MicroSD card + SPI module | FAT32/exFAT |
| Battery | 1000–2000 mAh LiPo | Flat cell preferred |
| Battery charger | TP4056 USB-C | LiPo charging |
| Audio DAC (optional) | PCM5102A I2S | For wired audio |
| Amp (optional) | MAX98357A | For speaker |
| Connectors | JST-PH cables | For battery + wiring |

### **Mechanical**

* 3D printing filament (PLA recommended for prototyping)
* Small machine screws (M2 or M2.5)
* Clear acrylic piece for screen window (optional)

---

# ✅ **11. Next Steps / What I Can Help With**

If you want, I can prepare:

### 👍 **A. Wiring diagram (ESP32 → screen → SD → buttons → battery)**

### 👍 **B. A more detailed bill of materials**

### 👍 **C. Software scaffolding for MicroPython project**

* UI framework
* Button handler
* MP3 playback loop
* Bluetooth A2DP setup
* Event loop

### 👍 **D. 3D enclosure design sketch plan**

---

# 🚀 What would you like next?

1. Wiring diagram?
2. Detailed BOM with purchase links?
3. Software architecture skeleton?
4. 3D enclosure design guidelines?
5. Comparison of ESP32-WROVER vs LyraT vs ESP32-S3 options?

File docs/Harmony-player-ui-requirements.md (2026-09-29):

# Harmony player UI requirements
Date: 2026-09-28
Status: implemented for bench validation; hardware acceptance incomplete
Tracking: Complete Mark-6 player UI (HARMONY-18), under Harmony Mark-6: Bluetooth bench player (HARMONY-17)

Build the first usable interface around music browsing, playback, volume, and Bluetooth device management. The verified temporary bench can support UI development while carrier qualification continues.

Dave requested these features after confirming clean audio, the display, pause/resume, track selection, and previous/next controls. On September 27, Dave requested the full requirements for Mark-6. Implementation and remaining acceptance are tracked in HARMONY-18. Mark-7 preserves the desktop visual direction for future hardware; it does not defer this UI scope.

## September 28 handoff

Implementation carries into Build Mark-7 portable Bluetooth player (HARMONY-19). Hardware expansion of Mark-6 stops; the software requirements remain. Both native builds and host verifier suites pass. The [bench record](../hardware/mark-6/feather-complete-ui-bench-20260927/README.md) separates two uploaded builds from the later source checkpoint. Automatic remote-name lookup is built and tested but not flashed. An open device-detail subtitle may retain a copied MAC until reopened. Full menu, audible volume/mute, full-album and second-receiver acceptance remain incomplete.

## Existing requirements and implementation

The historical library plan specifies Artists → Albums → Tracks, metadata fallbacks, and ordered tracks. The Python simulator implements that hierarchy and a 0–100 volume state. Settings remains a placeholder.

The native ESP-IDF firmware now implements music browsing, volume, Bluetooth management, settings and device preferences. The first complete build is undergoing bench validation. Host checks establish behavior under mocks; receiver compatibility, physical controls and endurance need hardware evidence. The browser remains a separate simulated design reference.

Sources: [library plan](gameplans/CS5.5.md), [navigation plan](gameplans/NAV.md), [volume plan](gameplans/CS5.6.md), [Python app](../core/player_app.py), and [native player](../firmware/mark-6/feather-carrier/README.md).

## Required menu tree

```text
Music
  Artists → Artist → Albums → Album → Songs
  Albums → Album → Songs
  Songs
  Playlists → Playlist → Songs
Now Playing
Bluetooth
  Saved devices → Device → Connect / Disconnect / Forget
  Find devices → Device → Pair and connect
Settings
  Shuffle: Off / On
  Repeat: Off / All / One
  Display timeout
```

Artist, album, song and existing M3U playlist browsing are implemented for bench validation. Playlist editing and text search are deferred.

## Required controls

Directions refer to the front of the finished enclosure. Verify the physical mapping separately.

| Control | Lists and menus | Now Playing |
| --- | --- | --- |
| Wheel | Move the highlight | Adjust volume |
| Center | Open the item or play the song | Pause/resume |
| Top | Go back one level | Return to the previous browsing screen |
| Bottom | Pause/resume the current song | Pause/resume |
| Left/right | Previous/next song without losing the browsing position | Previous/next song |

At the root, Back does nothing. Returning to a list restores its highlight and scroll position. A selected row and a playing song have distinct indicators.

Selecting a song creates a queue from the visible album or playlist and starts at that song. Browsing does not change the queue. Playback continues while menus are open. With repeat off, playback stops at the queue end.

## Music and Now Playing

Show the title, artist, album, elapsed time, duration when known, play state, volume, and connected receiver. Long names must remain accessible. Provide readable character fallback until the font supports the library's characters.

Prefer track metadata. Use folder and filename information when metadata is missing. Keep albums with identical names under different artists distinct. Preserve disc and track order.

The first version may use the prepared 45-track library and its existing paths. Label that limit explicitly. A general library must not silently truncate at the bench's 64-track limit. Set a supported library size before implementing the full index.

Keep album art, seeking, gapless playback, and additional codecs outside the first release. The current audio format remains 44.1 kHz stereo MP3.

## Volume

Provide a visible 0–100 level, mute at zero, and gradual changes without clipping. Start the first UI test at the existing quiet level. Remember volume across normal restarts.

Local digital volume must work without receiver volume support. Receiver volume synchronization is a separate compatibility feature. Define the gain curve and startup ceiling before changing the current attenuation.

## Bluetooth

Show saved devices separately from discovery results. Display connection, pairing, disconnected, and failure states. Distinguish devices with duplicate names.

Pair only after the user selects a device. Support connection cancellation and timeout or pairing errors with recovery instructions. Keep one audio receiver connected at a time.

Disconnect retains the saved pairing. Forget requires confirmation and removes the local bond and reconnect preference. It cannot promise to clear the receiver's own pairing record.

Reconnect to the last selected saved receiver. Never switch to an arbitrary discovered device. Pause after an unexpected disconnect and require resume after reconnection. This required behavior replaces the bench's automatic playback continuation.

If discovery interrupts audio, pause deliberately and show that state. Do not conceal interference as playback glitches. Verify discovery behavior on hardware before promising uninterrupted playback during a scan.

## Reliability and acceptance

- Browse into an album, play a song, return to browsing, and recover the same list position.
- Change songs and volume without a reset, audible glitch, or callback underrun.
- Pair with a second receiver, switch receivers, disconnect, and forget a saved device.
- Restart and verify saved volume and device preferences. Restore the last selection in a paused state.
- Handle missing storage, an empty library, unsupported audio, and a failed connection with readable recovery actions.
- Test shuffle and repeat against the current queue.
- Run the deferred full-album test while using the finished menus.

Preferences belong in device storage; the music card stays read-only. Library scanning, Bluetooth events, rendering, and audio must not block one another.

## Implementation status, September 27

| Area | Implemented in native firmware | Acceptance remaining |
| --- | --- | --- |
| Music | Artists, Albums, Songs, M3U playlists; metadata/fallback; ordered album queues; 512-track explicit capacity | Check the trial card and broader metadata/library fixtures on device |
| Now Playing | Track metadata, elapsed/known duration, volume and live receiver name | Visual/listening confirmation with the complete build |
| Controls/rendering | Navigation/playback, cached lists, incremental highlight redraw and slow long-label scrolling | Responsiveness under final menu/scan load |
| Volume | 0–100 digital gain, mute, 10 ms ramp; default/startup ceiling 40 (-24.08 dB) | Audible sweep/mute and persisted restart on hardware |
| Bluetooth | Saved/found lists, explicit pairing, switching, disconnect, confirmed Forget, cancel/errors and paused last-selected reconnect | Actual discovery, second receiver, forgetting and drop/reconnect |
| Settings | Shuffle, repeat off/all/one, display timeout with wake-only first input | Physical behavior and restart persistence |
| Persistence/recovery | NVS preferences and last song; paused cold boot; storage/file/connection recovery messages | Power-cycle, missing-card and unreadable-file device checks |
| Endurance | Host regression/sanitizer checks and native builds | Full-album playback while using finished menus |

Current limits: Just Works and legacy PIN 1234 pairing; custom PIN/passkey input is not implemented. Restart restores the last song within its album, not elapsed position or the prior playlist queue. Unknown durations show elapsed only. Displayed metadata and library sizes are bounded; see the [bench README](../firmware/mark-6/feather-player-bench/README.md). The first input after display timeout wakes only. Settings save after roughly 2–4 quiet seconds. Missing-card recovery requires inserting the card and restarting.

Album art, seeking, gapless playback, text search, playlist editing and additional codecs remain outside this first UI release. The physical carrier and battery qualification have separate acceptance criteria.

## Development order

1. Prototype the menu layout and control behavior on the desktop.
2. Implement Artists → Albums → Songs and Now Playing on the verified Feather bench.
3. Add adjustable volume.
4. Add saved devices, discovery, pairing, disconnect, and forget.
5. Complete Songs/Playlists, metadata indexing and Now Playing details.
6. Add queue settings, display timeout, persistence and recovery, then complete endurance and reconnect tests.

Keep the current working firmware available for rollback. Carrier power, ribbon, enclosure, and RF qualification remain separate from UI acceptance.

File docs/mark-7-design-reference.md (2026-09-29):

# Harmony Mark-7 visual reference

Saved September 27, 2026, at Dave's request. The approved desktop prototype is preserved by the annotated tag `mark7-visual-reference-20260927`, pointing to commit `1a3990b`.

[Browse the preserved source](https://github.com/dpaola2/Harmony/tree/mark7-visual-reference-20260927/platforms/pc/ui).

Preserve the warm cream body, rounded enclosure, large portrait screen, dark green typography and highlights, restrained Now Playing record graphic, and smooth recessed circular wheel with a center control. Dave particularly likes the device's visual appearance and sees a capacitive wheel working well with battery integration in Mark-7.

This is an adopted visual reference and a hardware exploration direction. Wheel sensing, dimensions, internal layout, battery fit, charging and runtime still need design and physical qualification. The current Mark-6 uses its mechanical ANO wheel and USB-powered Feather bench.

## Reproduce the reference

From the Harmony repository, create a separate checkout of the tag:

```sh
git worktree add --detach ../Harmony-mark7-reference mark7-visual-reference-20260927
cd ../Harmony-mark7-reference
python3 -m platforms.pc.ui_server --help
```

Run `python3 -m platforms.pc.ui_server` and open `http://127.0.0.1:8766` when that port is free. The source includes the 45-track metadata fixture. It includes no music audio. Playback and Bluetooth outcomes are simulated. See the prototype README for controls.

## Sources and scope

- Dave's September 27 feedback: “I actually really like the visual of what you have in the web prototype. make sure we save that for mark 7. looks like a capacative wheel, and it would go well with the battery etc.”
- [Prototype source and controls](../platforms/pc/ui/README.md).
- [Full Mark-6 UI requirements](Harmony-player-ui-requirements.md), Complete Mark-6 player UI (HARMONY-18), under Harmony Mark-6: Bluetooth bench player (HARMONY-17).

All adopted UI functionality remains in Mark-6. This reference reserves the physical visual direction for Mark-7; it does not move unfinished Mark-6 features to a later version.

Later September 27, Dave proposed proving battery operation on Mark-6 and reusing the electronics in a compact Mark-7 for walks and car use. See the [lessons and proposed sequence](mark-6-lessons-and-portable-next-step.md). This supersedes treating a fresh electronics design as necessary; exact layout and power qualification remain open.

## Adopted portable scope: September 28

[Mark-7 portable scope](mark-7-portable-scope.md) now defines the build. Reuse the current mechanical wheel first. Capacitive sensing remains a preserved option. Internal SD access through a removable cover is sufficient. Omit the integrated speaker and DAC.

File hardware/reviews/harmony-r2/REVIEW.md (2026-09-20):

# Harmony R2 independent circuit review

September 14, 2026. Sol implemented the correction; Codex reviewed the source changes and ran separate native KiCad checks. Tracking: HARMONY-14. Remaining release work: HARMONY-15.

**The schematic/PCB net mismatch is fixed. Fabrication remains on hold.** All 459 mainboard and 108 faceplate electrical pin/net assignments now agree. Both routed PCB files remain byte-identical to the pinned reference. This revision changes schematic and library definitions, not the printed case or board layout.

U1 and U9 had hidden power-input pins with the same name, EP. KiCad implicitly joined them, despite their drawn connections to different rails. Making those pins visible preserves the explicit connections. C23 pin 2 and U9's exposed pad now resolve to GND; U1's exposed pad and negative supply remain on -5VA. The [TI INA1620 datasheet](sources/INA1620.pdf), pages 3 and 28, and [NXP PCA8575 datasheet](sources/PCA8575.pdf), page 5, support that intended separation.

The WM8523 library incorrectly labeled many inputs and supply pins as outputs. Those definitions were corrected in both the schematic cache and local library. Independent review rejected proposed passive charge-pump pins and an open-collector zero flag, and restored bidirectional clock pins. All 20 final pin types match the reviewed model based on the [Cirrus datasheet](sources/WM8523.pdf), pages 4 and 15. No drawn wire, pin number, component position, or copper connection was changed.

| Mainboard check | Baseline | R2 |
|---|---:|---:|
| Schematic/PCB net conflicts | 30 | 0 |
| ERC errors | 28 | 10 |
| ERC warnings | 96 | 95 |
| Physical DRC errors | 38 | 38 |
| Physical DRC warnings | 45 | 45 |
| Other parity warnings | 10 | 10 |

Faceplate counts remain 6 DRC errors, 13 DRC warnings, 2 ERC errors, 24 ERC warnings, and 9 non-net parity warnings. Neither board reports unconnected PCB items. The [complete finding register](finding-dispositions.json) retains all 252 remaining findings with an action and no waivers.

## Remaining engineering and fabrication work

The next electrical cleanup is the TPS65133 and INA1620 enable-pin models, followed by external power-source annotations and library/bus-entry differences. Correct these from pin tables and proven power paths. Do not suppress rules or automatically synchronize the PCB to clear reports.

The physical review identified three areas needing explicit treatment:

- USB J6: twelve pads meet the connector cutout. The [native copper detail](usb-cutout-detail.svg.png) confirms this geometry. The manufacturer's drawing retrieval failed; obtain that drawing and a specific CAM/DFM disposition before changing the cutout or accepting zero edge clearance.
- Audio jack J1: eight annular-width findings include two 0.1034 mm rings. Native slots are 1.2 by 0.7 mm; the [manufacturer's drawing](sources/SJ-3506-SMT-TR.pdf), page 2, specifies 1.1 by 0.7 mm. Review finished-hole tolerance, pad shape and soldering fit together. A generic claim that these are rounding errors would be wrong.
- Faceplate: five touch electrodes are drawn with netless copper graphics contacting pads. Review their intended nets and isolation before accepting the clearance findings. The LED-enable via, copper sliver, artwork and library discrepancies also remain recorded.

Battery finished dimensions, charge/NTC/harness specifications, display FPC mechanics, and hardware firmware qualification remain open. Dave's slightly loose R1 coupons remain accepted; this correction does not justify a new case print.

## Evidence and reproduction

- [Source correction and implementer's report](../../revisions/harmony-r2/VALIDATION.md)
- [Independent native pin/net verification](independent-native-verification.json)
- [Independent symbol checks](symbol-verification.json)
- [Native commands, output and source hashes](native-check-run.json)
- [Revised assembly quote package](../../procurement/assembly-quote-r2/README.md)
- [Downloaded primary-source provenance](sources/manifest.json)

Run `run_native_checks.py --kicad-cli /absolute/path/to/kicad-cli`, then `verify_revision.py` with KiCad 8.0.9's bundled Python. Run `verify_symbols.py` and `catalog_findings.py` with Python 3. The native checks preserve source files. The net verifier checks every electrical pad and permits only the expected -5VA-to-GND correction relative to the baseline netlist.

The corrected sources and refreshed quote files remain local review artifacts. No supplier received them, no board order was placed, and no physical device has been qualified.

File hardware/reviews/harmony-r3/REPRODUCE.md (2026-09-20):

# Reproducing the R3 checks

Use native KiCad 8.0.9 CLI with an isolated configuration (run_native_checks.py creates it). Run verify_revision.py and physical/inspect_native.py using KiCad's bundled Python 3.9 with pcbnew/wx, then run verify_symbols.py with Python 3.

The analytic geometry checks use Shapely 2.1.2, pinned in requirements-geometry.txt. The review used Python 3.14 in /tmp/harmony-geometry-venv; that temporary environment is not part of the deliverable. Create an isolated environment and install the requirements to rerun physical/check_isolation.py, physical/verify_source_delta.py and physical/review_jack_scope.py. Root reran electrode isolation and zone-delta checks independently after the agent froze its files.

Regenerate the quote with generate_quote_package.py only after copying the latest four ERC/DRC reports into assembly-quote-r3. Run its validator and reviews/harmony-r3/verify_quote_package.py. Native errors deliberately remain; exit code 5 is a findings result, not a fabrication release.

apply_jack_fix.py documents the original board mutation from the R2 copy and relies on preserved experiment fill output. sync_jack_library.py is the necessary next step using KiCad Python; it exports the authoritative board footprint to unflipped library coordinates. These mutation scripts are provenance, not checks to run on a released design.

The mainboard-experiment and physical/sliver-localization folders contain unreleased experiments. Fabrication exports for current engineering review are only under hardware/procurement/assembly-quote-r3/fabrication.

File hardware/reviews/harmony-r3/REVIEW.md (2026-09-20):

# Harmony R3 engineering review

R3 corrects the remaining power-source model, makes the touch electrodes visible to KiCad's net checker, and repairs the audio-jack footprint. All 567 schematic/PCB pin connections agree with R2. Both boards report zero unconnected items; this is not hardware qualification. Fabrication remains on hold for the specific issues below.

Sol handled the schematic work; a second subagent reviewed touch geometry and independently checked the root's jack correction. Root rejected a proposed passive type for TPS22948's open-drain FLT pin, restored the manufacturer type, reran native KiCad 8.0.9, checked bounded geometry changes, and independently reconciled the quote package.

| Native check | R2 mainboard | R3 mainboard | R2 faceplate | R3 faceplate |
|---|---:|---:|---:|---:|
| ERC errors / warnings | 10 / 95 | 1 / 94 | 2 / 24 | 0 / 24 |
| DRC errors / warnings | 38 / 45 | 22 / 43 | 6 / 13 | 0 / 13 |
| Non-net parity warnings | 10 | 9 | 9 | 9 |
| Unconnected PCB items | 0 | 0 | 0 | 0 |

The [complete register](finding-dispositions.json) retains all 215 remaining native findings. No project rules or exclusions changed. Independent wheel measurements are also retained because native DRC omits those graphic-to-graphic gaps.

## Confirmed changes

- TPS65133 supply/ground/output and INA1620 enable pin types now match their functions. Flags identify verified USB, switched-USB and ground sources, plus connector-supplied faceplate rails. Three unused bus entries were removed; J2's label now matches the PCB. Six corrected project symbols match their embedded copies. [Power review](power/REVIEW.md), [symbol audit](power/symbol-delta-audit.md).
- Five touch shapes now carry their actual nets. Their copper contours are exactly preserved, with Gerber equivalence verified before refill. A native GND refill increases guard clearance from 0.254499 to 0.500499 mm. SW1's plated touch pad has the correct footprint type. [Physical evidence](physical/handoff.json).
- J1 now uses the manufacturer's eight 1.10 × 0.70 mm slots and 10.10 mm cutout. Two copper lands were resized and offset to maintain clearance and annulus. All hole centres remain fixed. Native reimport proves the reusable library matches the board, including masks and edge geometry. Nominal minimum annuli are 0.150 mm, or 0.1632 mm for pins 2 and 6. Finished tolerances still require supplier review. [Independent jack review](physical/jack-review.json).

Root verified unchanged pad centres, tracks, vias and unrelated footprints. Only J1 pad/cutout geometry, explicit electrode net metadata, footprint attributes and native zone fills changed on the boards. The [source patch](r2-to-r3.patch) and [native reconciliation](independent-native-verification.json) identify the changes. R1 case CAD and accepted fit clearances remain unchanged.

## Release holds

**USB fit comes first.** GCT's A1 drawing specifies a recommended 0.80 mm PCB; this mainboard's stack-up totals 1.60252 mm. The 1.60 mm figure in the connector title describes its mounting offset, not PCB thickness. Twelve J6 pads also end at the routed cutout. Obtain a section/sample fit check and explicit fabrication tolerance acceptance, or revise the connector footprint. This review does not establish incompatibility, but it does establish an unresolved discrepancy. [Archived primary drawing](sources/USB4510-03-1-A.pdf).

**Wheel geometry needs an engineering decision.** The three pair gaps are 0.282097, 0.291368 and 0.292112 mm against a 0.5 mm netclass. They are isolated, not shorted. The retained sliver warning belongs to the Pin 3 electrode polygon. CAM review must address etching, and the prototype must establish touch performance through the printed cover. The reported dangling LED_ENABLE via is intentional TP7 plated test access and is preserved.

**Mainboard refill exposes a thermal-relief finding.** U15 pad 39 has one B.Cu spoke where two are configured. Native connectivity still passes. Review the multilayer ground connection and reflow needs before a local correction or specific acceptance.

The remaining ERC error is the unused FLT output tied to GND and conflicting with its source flag; a warning also concerns WM8523 SDOUT/DEEMPH on that net. Manufacturer pin types remain intact. Library warnings comprise 110 standard power-symbol differences plus SW1; the six corrected custom models match. Mixed plated/SMT metadata, anonymous artwork references, other footprint-library differences and clipped/small silkscreen remain individually registered for review, not silently refreshed.

The [R3 quote package](../../procurement/assembly-quote-r3/README.md) passes independent manifest, BOM, placement and firmware-image reconciliation: 92 mainboard plus 19 faceplate fitted components; 59 excluded structures; 11 unchanged programming images. [DFM questions](../../procurement/assembly-quote-r3/DFM-QUESTIONS-DRAFT.md) are drafted and unsent. Battery/display dimensions and physical firmware/runtime tests remain separate holds. No order, supplier submission or full-case print is justified by these checks alone.

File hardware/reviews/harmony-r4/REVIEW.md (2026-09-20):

# Harmony R4 review

**Use the unmodified current Tangara boards for the first build.** R4 restores upstream jack geometry and filled copper. The production archive corroborates the original jack, USB and display footprint geometry. We have no measured failure that justifies keeping R3's physical departures. The later upstream connector replacement remains necessary to the chosen reference revision.

## Verified

- Both R4 PCB files are byte-identical to public Tangara commit `9853b4a1dc8a0e3ea3ec75450522e42df12eaa52`.
- Native pcbnew inventory and fresh schematic netlists agree on 459 mainboard and 108 faceplate pin/net assignments. Neither board has unconnected items.
- R3's schematic corrections remain. No circuit topology, firmware, battery harness or enclosure change was made.
- Quote-only MPN overrides complete U12 as `BD91N01NUX-E2`, U4 as `TLV75533PDBVR`, and U5 as `PE1605C4A6_R1_00001`, with manufacturer sources. These do not authorize purchasing.

## Decisions on prior holds

| Finding | R4 disposition |
|---|---|
| J1 slot size, two small annuli and cutout | Restore upstream geometry. The archived factory files show the same original features. Ask PCBWay to accept these exact finished tolerances; retain the finding until CAM review. |
| USB drawing versus 1.6 mm board | Preserve the upstream connector/geometry. Designer specifies 1.6 mm boards; production pads, drills and edge geometry corroborate it. Treat it as a documented fabrication detail, not a mandate to redesign. |
| Touch copper and guard refill | Restore the upstream board and fills. Native zero-gap errors compare an electrode's netted pad with its own unnetted artwork. The measured inter-electrode gaps remain about 0.28–0.29 mm and isolated. CAM etching review and physical calibration through our printed cover remain necessary. |
| U15 one-spoke warning introduced by refill | Restored upstream fill removes that new finding; no starved-thermal finding is reported on R4. |
| FLT open-drain output tied to ground | Retain production connection and accurate pin type. ERC flags the source-flag conflict. The output is unused; do not change production wiring simply to suppress ERC. |
| Library/type/silkscreen warnings | Retained in native reports. Do not update footprints or refills automatically. CAM may propose necessary changes for explicit review. |

## Native reports

| Board | ERC errors / warnings | DRC errors / warnings | Parity warnings | Unconnected |
|---|---:|---:|---:|---:|
| Mainboard | 1 / 94 | 38 / 45 | 9 | 0 |
| Faceplate | 0 / 24 | 6 / 13 | 9 | 0 |

Restoring the source restores its DRC findings. Counts are not a quality score. No rule or exclusion was weakened. The complete register includes native records and review categories; supplier acceptance remains pending for fabrication tolerances. This is not a claim of hardware qualification or an approved fabrication release.

## Evidence

- [Native connectivity](connectivity-verification.json), [read-only check run](native-check-run.json), [finding register](finding-dispositions.json)
- [Production archive comparison](/Users/dave/projects/assistant/05-projects/mp3-player/deliverables/2026-09-15-component-verification/production-archive/README.md)
- [Current quote package](../../procurement/assembly-quote-r4/README.md)

HARMONY-15 owns engineering review; HARMONY-9 owns sourcing. PCBWay showed no reply to the sent R3 request when checked September 15 around 11:41 EDT. R4 has not been submitted. Actual price, quantity, substitutions, CAM acceptance, assembly/programming scope, battery and case fit remain to be settled before a purchase/release decision.

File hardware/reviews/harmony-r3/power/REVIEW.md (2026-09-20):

# Harmony R3 power and ERC cleanup

Date: 2026-09-14

## Result

KiCad 8.0.9 native ERC reports one intentionally retained error on the R3 mainboard and zero errors on the faceplate. The mainboard changed from 10 errors and 95 warnings to 1 error and 94 warnings. The faceplate changed from 2 errors and 24 warnings to 0 errors and 24 warnings. No ERC exclusions or project-rule suppressions were added.

The machine-readable before/after reports and exported netlists are in this directory:

- `before-mainboard-erc.json` and `after-mainboard-erc.json`
- `before-mainboard-netlist.xml` and `after-mainboard-netlist.xml`
- `before-faceplate-erc.json` and `after-faceplate-erc.json`
- `before-faceplate-netlist.xml` and `after-faceplate-netlist.xml`

## Datasheet-backed symbol corrections

Texas Instruments TPS65133 datasheet SLVSC01A identifies AVIN and PVIN as supply pins, AGND, PGND, GND, and the exposed pad as ground connections, and VPOS and VNEG as converter outputs. The R3 project symbol and the embedded Audio-sheet copy now use `power_in` for supply/ground pins and `power_out` for VPOS/VNEG. SWP and SWN remain bidirectional switch nodes, and EN remains a logic input.

Source: https://www.ti.com/lit/ds/symlink/tps65133.pdf

Texas Instruments INA1620 datasheet SBOS859B states that EN may be driven by a controller GPIO or logic gate, or tied directly to V+. The project symbol and embedded Audio-sheet copy now describe EN as an input rather than a power input. The ±5 V supply pins remain power inputs.

Source: https://www.ti.com/lit/ds/symlink/ina1620.pdf

U16 is populated as TPS22948 even though the inherited library identifier is `TPS22917DBV`. Its FLT pin is physically tied to GND in this design. TI specifies FLT as an open-drain output that pulls low during thermal-shutdown or reverse-current events. The project and embedded symbols retain that `open_collector` electrical type. This intentionally unused, fixed-low status output therefore produces the remaining ERC pin conflict when the same GND net is correctly marked with a power-source flag. The conflict is recorded rather than hidden by changing the IC pin function or adding an ERC exclusion.

Source: https://www.ti.com/lit/ds/symlink/tps22948.pdf

The BMDU JTAG connector GND pins are passive connector contacts rather than power consumers. This removes the false requirement for a local source on that connector while preserving its GND net.

## Power-source proof

- Mainboard VBUS is physically supplied at USB-C receptacle J6, then connects to Q1 source. `#FLG0201` is on that external VBUS net.
- Mainboard `VBUS_SWITCHED` is the Q1 drain rail feeding MCP73871 U10 IN pins 18 and 19 and VPCC pin 2. Since a MOSFET passive pin does not advertise a source to ERC, `#FLG0202` annotates the post-Q1 rail.
- Mainboard GND returns through USB-C J6 and battery connector J7. `#FLG0203` marks that externally established reference.
- Faceplate +3V3 enters through J4 pins 13, 14, and 15; GND returns through J4 pins 1, 5, 7, and 9. `#FLG01` and `#FLG02` annotate these externally supplied rails.

The before/after netlists show the same functional nets for the affected pins. Flags only add ERC power-output annotations.

## Other cleanup

Three bus-entry objects in `peripherals.kicad_sch` had no wire endpoint and produced the three dangling-wire errors. They were removed by UUID; no bus member, label, or wire was removed.

The hierarchical connector that appears as mainboard J2 now has the value `FP Connector`, matching its existing PCB value and naming its faceplate destination from the mainboard perspective. Its pin nets are unchanged.

The remaining mainboard error is the documented TPS22948 FLT-to-GND disposition above. The other 94 mainboard and 24 faceplate findings are warnings. Most are KiCad library-difference warnings inherited from the source design. This pass did not blanket-waive or suppress them.

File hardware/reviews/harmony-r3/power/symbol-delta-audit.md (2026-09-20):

# R3 symbol delta and residual library-warning audit

Date: 2026-09-14

This is a read-only comparison of the corrected project-local definitions in `tangara-mainboard/symbols.kicad_sym` against the copies embedded in the R3 schematic sheets. The comparison extracted each complete S-expression, normalized whitespace and only the expected embedded `symbols:` prefix, and compared the resulting content. Pin tables were independently extracted and compared by pin number, name, and electrical type.

## Corrected symbol copies

| Intended part | KiCad library ID | Embedded sheet | Full normalized definition | SHA-256 prefix | Electrical pin types |
|---|---|---|---|---|---|
| INA1620 | `INA1620` | `audio.kicad_sch` | Identical | `94e33e0dfa5acc82` | EN input; V+, V-, GND, EP power input; amplifier inputs input; amplifier outputs output; resistor terminals passive; NC no-connect |
| TPS65133 | `TPS65135RTER` | `audio.kicad_sch` | Identical | `f9405977530ec93e` | AVIN, PVIN, AGND, PGND, GND, EXP power input; VPOS and VNEG power output; EN input; SWP and SWN bidirectional |
| WM8523 | `WM8523` | `audio.kicad_sch` | Identical | `1f26300042c2f33d` | AVDD, LINEVDD, AGND, LINEGND power input; DACDAT, MCLK, SCLK, mute/mode pins input; BCLK, LRCLK, SDA, SDOUT/DEEMPH bidirectional; analog/charge-pump/status outputs output |
| PCA8575BS | `PCA8575BS` | `peripherals.kicad_sch` | Identical | `17efdfc779d9d9cb` | IO0_0 through IO1_7 and SDA bidirectional; SCL and address pins input; INT open collector; VDD, VSS, EP power input |
| TPS22948 | `TPS22917DBV` | `peripherals.kicad_sch` | Identical | `964feaf978523612` | IN and GND power input; ON input; FLT open collector; OUT power output; NC no-connect |
| BMDU JTAG connector | `BMDU` | `tangara-mainboard.kicad_sch` | Identical | `afff7dc3b32ef9b1` | vRef power input; GND contacts 3 and 5 passive; TMS, TCK, TDO, UART_TX, nRst output; TDI and UART_RX input |

The BMDU device is a physical JTAG/debug connector (`J3`, value `JTAG`, DNP), not a powered module. Passive GND contacts therefore describe connector contacts correctly. Its vRef remains a power input because the target supplies the debugger's voltage reference.

## Residual `lib_symbol_issues`

The final native ERC reports contain exactly 89 mainboard and 22 faceplate `lib_symbol_issues`. Every one says the embedded symbol “has been modified in library”; none is a library-not-found warning.

Mainboard:

| Library symbol | Count | Affected references |
|---|---:|---|
| GND | 60 | #PWR01, #PWR0102, #PWR0103, #PWR0105, #PWR0109, #PWR011, #PWR0110, #PWR0117, #PWR0119, #PWR012, #PWR0121, #PWR0122, #PWR013, #PWR014, #PWR015, #PWR016, #PWR017, #PWR018, #PWR020, #PWR0201, #PWR0202, #PWR0203, #PWR0204, #PWR0206, #PWR0208, #PWR0209, #PWR021, #PWR0210, #PWR0211, #PWR0213, #PWR0214, #PWR023, #PWR024, #PWR025, #PWR028, #PWR029, #PWR030, #PWR031, #PWR032, #PWR033, #PWR034, #PWR035, #PWR036, #PWR037, #PWR038, #PWR039, #PWR0402, #PWR0404, #PWR0407, #PWR0409, #PWR0410, #PWR0412, #PWR0413, #PWR0415, #PWR0417, #PWR043, #PWR054, #PWR055, #PWR06, #PWR09 |
| +3V3 | 24 | #PWR010, #PWR0101, #PWR0108, #PWR0111, #PWR0112, #PWR0113, #PWR0115, #PWR0118, #PWR0120, #PWR0125, #PWR0205, #PWR0217, #PWR026, #PWR03, #PWR04, #PWR0403, #PWR0406, #PWR0408, #PWR041, #PWR0411, #PWR0416, #PWR05, #PWR056, #PWR08 |
| +5VA | 2 | #PWR019, #PWR027 |
| -5VA | 2 | #PWR02, #PWR022 |
| SW_SPDT | 1 | SW1 |

Faceplate:

| Library symbol | Count | Affected references |
|---|---:|---|
| GND | 13 | #PWR010, #PWR0102, #PWR0106, #PWR0108, #PWR012, #PWR016, #PWR017, #PWR018, #PWR02, #PWR05, #PWR06, #PWR07, #PWR09 |
| +3V3 | 9 | #PWR01, #PWR0101, #PWR0107, #PWR0109, #PWR011, #PWR013, #PWR03, #PWR04, #PWR08 |

These 111 findings are library-difference warnings limited to standard power symbols plus mainboard SW1. They do not implicate any of the six audited project-local symbols above. No library refresh, exclusion, or circuit mutation was performed during this follow-up.

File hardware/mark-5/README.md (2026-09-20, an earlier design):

# Mark-5 album player

The current assembly plays one album described by `album.json` on the microSD
card. The Mac extracts tags with ffprobe and copies MP3s without transcoding.
The player reads the manifest once, orders tracks by disc and track number,
and streams each file from the card. It does not scan the Swinsian library or
maintain a database. The complete wiring and test history are in `bench-config.json`.

## Prepare an album

With the WROVER unplugged, move the card to the Mac's reader. From the repository:

```sh
python3 tools/prepare_mark5_album.py "/path/to/Artist/Album" "/Volumes/MIYOO/HARMONY/ALBUM"
```

The tool requires tagged MP3s and ffprobe. It copies files using disc/track
filenames, verifies SHA256, and writes the manifest. A conflicting existing file
causes an error; existing card contents are preserved. Eject the card before
returning it to the unpowered VS1053, then connect USB.

`HARMONY/HUMANCLAY/album.json` currently describes 12 tracks, including the bonus
track “Young Grow Old,” totaling approximately 61 minutes. The host copy is
`albums/human-clay.json`. The earlier `HARMONY/HIGHER.MP3` is also retained.

## Run from the Mac

Use Python with pyserial installed:

```sh
python3 tools/run_mark5.py --manifest /sd/HARMONY/HUMANCLAY/album.json --seconds 4500
```

On Dave's Mac, the working Python is
`/Users/dave/.espressif/python_env/idf5.3_py3.13_env/bin/python`.
Pinned SD/display/font sources and their licenses are in
`platforms/esp32/mark5_vendor/`; the loader no longer depends on temporary clones.

The loader checks the WROVER's unique ID before changing GPIOs. The player starts
silent at Ready, volume 58. Play/pause controls playback; Next/Previous wrap
through the album and preserve a paused state. Track endings advance
automatically. The last track ends the album without repeating it. This bench
runner exits after album completion or its time limit; reload it for another
session. No automatic boot script is installed.

The screen shows the title, artist/album, position, elapsed/total time and volume.
Startup checks the manifest and every file's size. Completed tracks must match
their expected SHA256. The card is mounted read-only during playback. The log
records completed tracks, button events, decoder time and free heap. A deliberate
skip does not count as a completed or checksum-verified track. Resetting the
decoder between tracks may introduce a short gap; gapless playback is not promised.

## Verification

```sh
.venv/bin/python -m pytest -q tests
python3 tools/run_mark5.py --transition-test
```

The transition test requires the three short excerpts and manifest already
prepared under `HARMONY/TESTALBM`. It starts automatically at mute, verifies all
three complete files and decoder progress, and checks automatic advancement and
the final stopped state. It passed on September 19. It does not replace a full
album run. Faint SD-related clicks remain accepted for this prototype.

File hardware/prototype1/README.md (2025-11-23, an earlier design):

# Prototype 1 (Phase 1)

- Goal: bring-up on ESP32-S3-WROOM (ESP32-S3-DevKitC-1 v1.1) while waiting for WROVER; no audio/A2DP expected. Focus on SD + display + buttons.
- Display: Waveshare ST7789V2, 1.69", 240x280.
- Storage: basic MicroSD SPI reader.
- Inputs: basic tactile buttons (up/down/left/right/select/back, play/pause, volume +/-). No rotary, no battery.
- Power: USB from dev kit.
- Wiring: 3V3/GND from dev kit; SPI for SD and ST7789V2; GPIOs for buttons. Document pin mappings once chosen.
- Notes: S3 WROOM lacks classic BT; expect UI/navigation only. Plan to port to WROVER in Prototype 2 for audio.***

## Wiring Plan (ESP32-S3-DevKitC-1 v1.1)

- Power: use 3V3 and GND from the dev kit. Common ground everywhere.
- Display (ST7789V2 over SPI):
  - CLK (SCK): GPIO12 → display `CLK`
  - MOSI (DIN): GPIO11 → display `DIN`
  - CS: GPIO9
  - DC: GPIO8
  - RST: GPIO18
  - BL: GPIO17 (or tie to 3V3 for always-on backlight)
  - MISO: not used by display
- SD card: pause wiring for now (we’ll revisit once a better breakout is on hand). If you experiment, pick free GPIOs not used above and update `sd_test.py` accordingly.
- Buttons (active-low to GND, enable internal pull-ups in code):
  - Up: GPIO2
  - Down: GPIO3
  - Left: GPIO4
  - Right: GPIO5
  - Select: GPIO6
  - Back: GPIO7
  - Play/Pause: GPIO14
  - Volume Up: GPIO15
  - Volume Down: GPIO16

## MicroPython Bring-Up Notes

- SD: mount FAT32 with folder convention `Artist/Album/Track.ext` at root. Use SPI(2) (or explicit pins) with the mapping above.
- Display: drive ST7789V2 over SPI using the same SCK/MOSI; set CS/DC/RST/BL per wiring above.
- Input: poll buttons with internal pull-ups; translate to `ButtonEvent` values for `PlayerApp`.
- Audio: none on this phase; use a stub `AudioBackend` (no-op play/pause/resume/stop, track loader from SD).
- Main script flow: mount SD → build track list → init display/buttons/audio stub → run event loop feeding `PlayerApp.handle_button()` and calling `render()`.

## Testing

Use these quick checks before wiring buttons:

1) Flash MicroPython and confirm REPL works over USB.
2) **Display test**: copy `display_test.py` that inits ST7789V2 with CS=9, DC=8, RST=18, BL=17 (or BL tied high) and fills the screen with solid colors/text.
3) **(Optional) SD test**: once you have a known-good breakout, wire it to free pins, update `sd_test.py` to match, and run it to list `/sd`.
4) After buttons are wired, map the planned GPIOs, emit `ButtonEvent`s, and drive `PlayerApp`.

## How to Run the Tests / Flash & Upload

- Host dependencies (macOS): Python 3.11+, `pip install --user esptool mpremote` (or use a venv). `mpremote` is simplest for copy/run.
- Flash MicroPython (once per board):
  - Download the latest ESP32-S3 MicroPython `.bin` from micropython.org.
  - Erase and flash: `esptool.py --chip esp32s3 --port /dev/tty.usbmodem* erase_flash` then `esptool.py --chip esp32s3 --port /dev/tty.usbmodem* write_flash -z 0x0 firmware.bin`.
- Verify REPL: `mpremote connect /dev/tty.usbmodem* repl`.
- Upload tests: `mpremote connect /dev/tty.usbmodem* cp display_test.py :display_test.py` (and `sd_test.py` if you wire SD).
- Run on-board: `mpremote connect /dev/tty.usbmodem* run display_test.py`.
- When ready for the app, copy the MicroPython `main.py` (once we add it) and reboot; it will auto-run.
- If/when you revisit SD, update `sd_test.py` pins to match your wiring and run it similarly: `mpremote … run sd_test.py`.

## Running the demo UI on device (no buttons required)

The ESP32 build mirrors the PC simulator UI and drives itself in a loop so you can see the screens on the ST7789 without wiring buttons yet.

1) From repo root, copy the core logic and ESP32 platform adapter files:

```bash
mpremote connect /dev/tty.usbmodem* cp -r core :core
mpremote connect /dev/tty.usbmodem* cp platforms/esp32/esp_screen.py :esp_screen.py
mpremote connect /dev/tty.usbmodem* cp platforms/esp32/esp_audio_backend.py :esp_audio_backend.py
mpremote connect /dev/tty.usbmodem* cp platforms/esp32/main_esp32.py :main.py
```

2) Run the demo (or just reboot to auto-run `main.py`):

```bash
mpremote connect /dev/tty.usbmodem* run main.py
```

What it does: uses a mock library (artists → albums → tracks), animates through Library/Now Playing/Settings, and exercises play/pause/volume state so you can confirm rendering and navigation on the display.

### Optional splash image

If you want a branded/loading screen for ~5s on boot, place a raw RGB565 image sized 240x280 at `assets/loading.raw` on the device (relative to root). The demo will load it if present; otherwise it falls back to a text “Harmony MP3 / Loading…” splash. Copy with:

```bash
mpremote connect /dev/tty.usbmodem* cp assets/loading.raw :assets/loading.raw
```

# ESP32-S3-DevKitC-1 v1.1 Docs

https://www.digikey.com/en/products/detail/dfrobot/DFR0895/18069302

---

### 📄 Key Documentation Links

* User Guide v1.1: [https://docs.espressif.com/projects/esp-dev-kits/en/latest/esp32s3/esp32-s3-devkitc-1/user_guide_v1.1.html](https://docs.espressif.com/projects/esp-dev-kits/en/latest/esp32s3/esp32-s3-devkitc-1/user_guide_v1.1.html) — covers getting started, hardware reference, revision details. ([Espressif Docs][1])
* Main board page: [https://docs.espressif.com/projects/esp-dev-kits/en/latest/esp32s3/esp32-s3-devkitc-1/index.html](https://docs.espressif.com/projects/esp-dev-kits/en/latest/esp32s3/esp32-s3-devkitc-1/index.html) — links to PDF downloads and all versions. ([Espressif Docs][2])
* Additional reference (pinout, etc): article from Random Nerd-Tutorials explaining the pinout and functions for similar board. ([Random Nerd Tutorials][3])

---

### 🔍 What the documentation includes

In particular, the User Guide v1.1 has:

* “Getting Started” section with overview of the board and how to flash firmware. ([Espressif Docs][1])
* “Hardware Reference” section that details the board’s components, pin headers, etc. ([Espressif Docs][1])
* “Hardware Revision Details” showing version changes, known issues, etc. ([Espressif Docs][1])
* Related supporting documents (module datasheets, etc) via links.
  Also the board page lists older version (v1.0) so you can compare if needed. ([Espressif Docs][2])

---

### ✅ Why it’s the right documentation

* Even though your board is stated as “v1.1”, the User Guide explicitly calls out **v1.1** in the title. ([Espressif Docs][1])
* The manufacturer (Espressif) hosts the docs on their “esp-dev-kits” site, so it is authoritative.
* All major hardware details, revision info, and pin headers are covered — very useful for your audio/USB project with the ESP32-S3 board.

---

If you like, I can pull **the direct PDF download** of the User Guide (v1.1) and also extract **key pinout diagrams and header-maps** for your board (makes wiring breadboard / UI easier). Would you like me to fetch those?

[1]: https://docs.espressif.com/projects/esp-dev-kits/en/latest/esp32s3/esp32-s3-devkitc-1/user_guide_v1.1.html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 "ESP32-S3-DevKitC-1 v1.1 - Technical Documents"
[2]: https://docs.espressif.com/projects/esp-dev-kits/en/latest/esp32s3/esp32-s3-devkitc-1/index.html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 "ESP32-S3-DevKitC-1 - — esp-dev-kits latest documentation"
[3]: https://randomnerdtutorials.com/esp32-s3-devkitc-pinout-guide/?utm_source=chatgpt.com "ESP32-S3 DevKitC Pinout Reference Guide: GPIOs ..."

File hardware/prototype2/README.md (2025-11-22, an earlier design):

# Prototype 2 (Phase 2)

- Goal: migrate to ESP32-WROVER dev kit (DevKitC with WROVER-B, PSRAM, classic BT) for audio/A2DP and full feature set once available.
- Display: ST7789 SPI (2.0–2.4" IPS), may upgrade from Phase 1 screen.
- Storage: MicroSD SPI breakout.
- Inputs: rotary encoder (EC11) with push for scroll/select; tactile buttons for back/play-pause/volume; optional extra buttons.
- Audio: start with Bluetooth A2DP source; optional I2S DAC/amp (PCM5102A, MAX98357A) later.
- Power: USB for bring-up; plan LiPo + TP4056 + switch for production.
- Wiring: map SPI for SD/display, GPIO for encoder/buttons, I2S pins reserved if needed. Document pin mappings when set.

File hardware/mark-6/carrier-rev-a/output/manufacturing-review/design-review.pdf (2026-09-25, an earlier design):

HARMONY / MARK 6 / REV A

# From size dummy to routed board

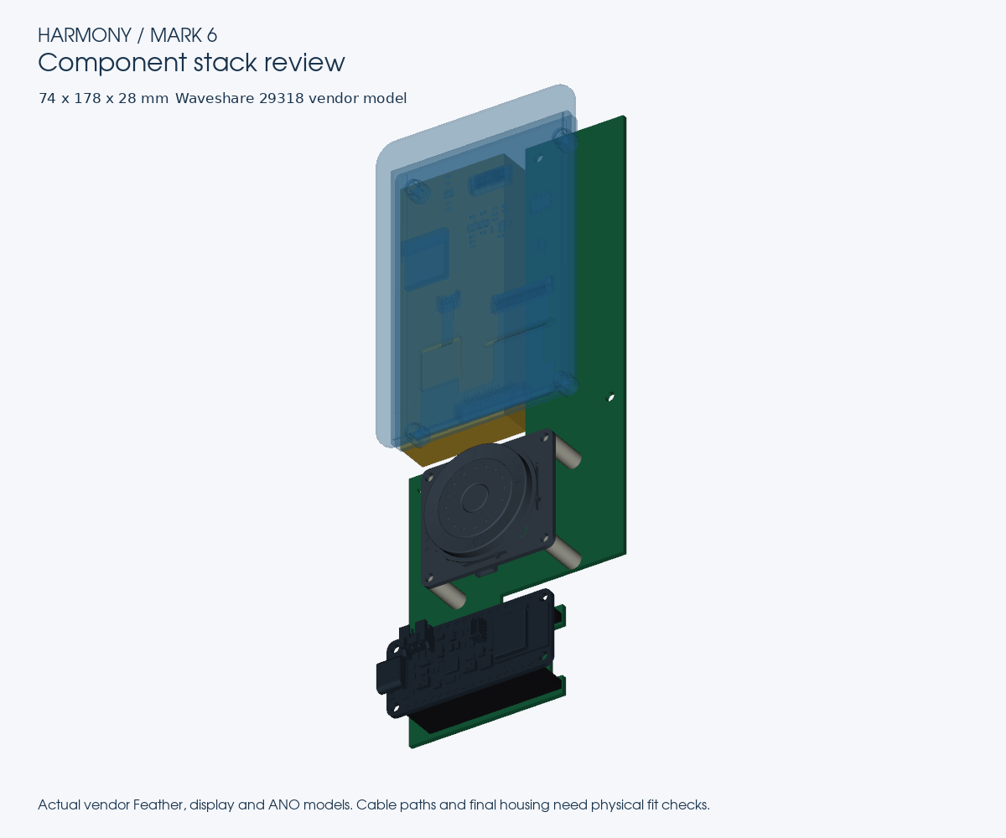
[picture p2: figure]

September 22, 2026 | Prototype review - not released for manufacture | 1

Outside size accepted: 74 x 178 x 28 mm. USB first; battery space reserved.

CAD checks passed. Zero schematic ERC violations, zero PCB DRC violations and zero open connections. All 122 electrical PCB pads match the schematic; all 28 Feather mating positions match vendor CAD.

No hand soldering. The supplier fits 36 carrier parts, including the sockets. The factory-headered Feather, EYESPI display and ANO controls plug in.

Remaining physical checks. Exact display thickness, factory header insertion and cable/port access. Waveshare 29318 replaces #5846; US stock is listed. Physical module and cable fit remain unverified.

# Routed carrier and antenna cutout

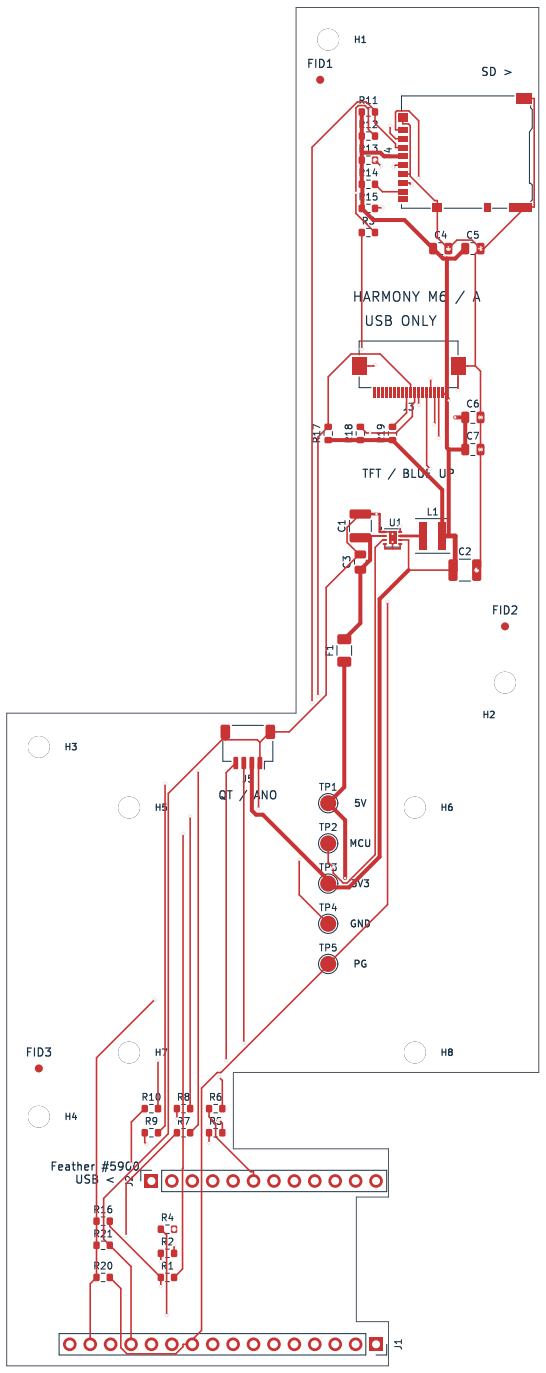
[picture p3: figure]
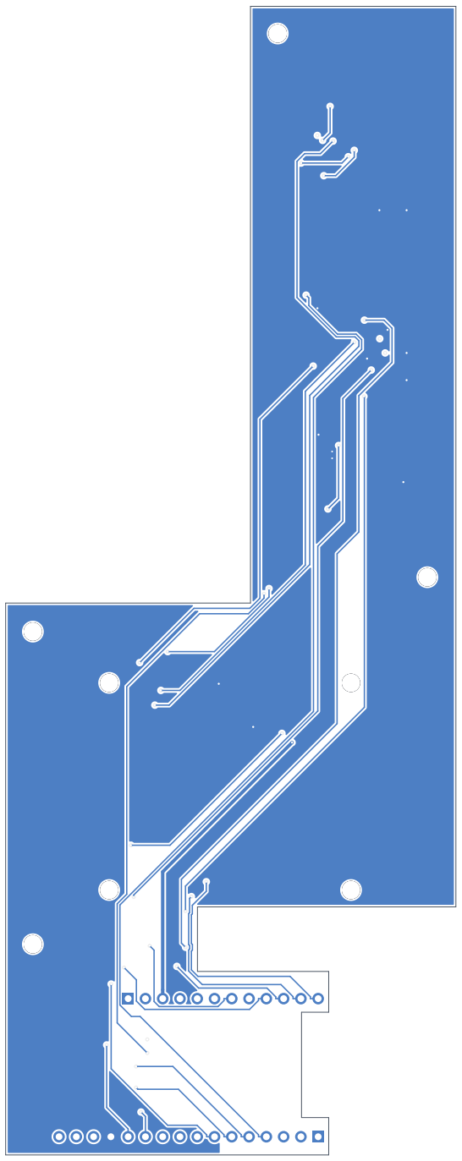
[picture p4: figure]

September 22, 2026 | Prototype review - not released for manufacture | 2

Four layers, 1.6 mm board. Top and back shown from the same top-view coordinates.
TOP / COMPONENT SIDE | BACK / THROUGH VIEW

The antenna overhangs the carrier cutout. Ground pours stop outside its reserved halo; necessary header pads and traces remain nearby. Final in-case Bluetooth range still needs testing.

# Assembly stack and release checks

September 22, 2026 | Prototype review - not released for manufacture | 3

All heights below are measured from the rear outside surface toward the front.

Item | Height / Z range | Basis
Carrier PCB | 6.5-8.1 mm | 1.6 mm board
Socket body top | 16.61 mm | Samtec SSW: 8.51 mm
Feather highest component | 25.52 mm | Vendor STEP; nominal headers
ANO control front | 27.47 mm | Vendor STEP; 12 mm spacers
Waveshare display | 16.75-27.3 mm | Vendor STEP; 10.55 mm total
Future battery reservation | 1.6-12.1 mm | Unconnected; no charger

Power
TPS62162 with 2.2 uH and 22 uF / 16 V bulk capacitors. A 450 mA peripheral allowance plus the Feather gives about 618 mA from a 4.75 V source at assumed 85% converter efficiency. Use a known 5 V source with at least 1 A available for qualification. These are budgets, not measurements.

Cables and case ports
100 mm EYESPI cable (#5239) and 50 mm QT-to-QT cable (#4399). The display FFC connector sits near the top, at X37/Y20.3. Reserve a loose cable loop above the future battery and use the upper ANO connector. Provide recessed USB plug access and a finger pocket for SD ejection.

Before an order
Supplier DFM, exact part availability, header/socket fit and the display measurement remain. Vias inside SMT pads require resin filling and copper capping; the assembler must review U1 stencil coverage. Manufacturing files are supplied for review, with no order authorization.

After assembly
Stage first power with current limiting and rail checks. Then test display refresh, SD and controls during A2DP playback, reconnect behavior, temperature and RF range. Complete the deferred full-album run before calling Mark 6 qualified.

Detailed sources, exact BOM, tolerances and procedures are in the accompanying power-review.md and mechanical-review.md. The STEP assembly is a review model, not a finished hollow case.

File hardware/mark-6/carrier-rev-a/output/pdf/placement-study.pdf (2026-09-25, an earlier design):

### HARMONY / MARK 6

# Smaller layout: full-size hand check

3.5-inch display, rotated ANO controls, and the selected factory-headered Feather.

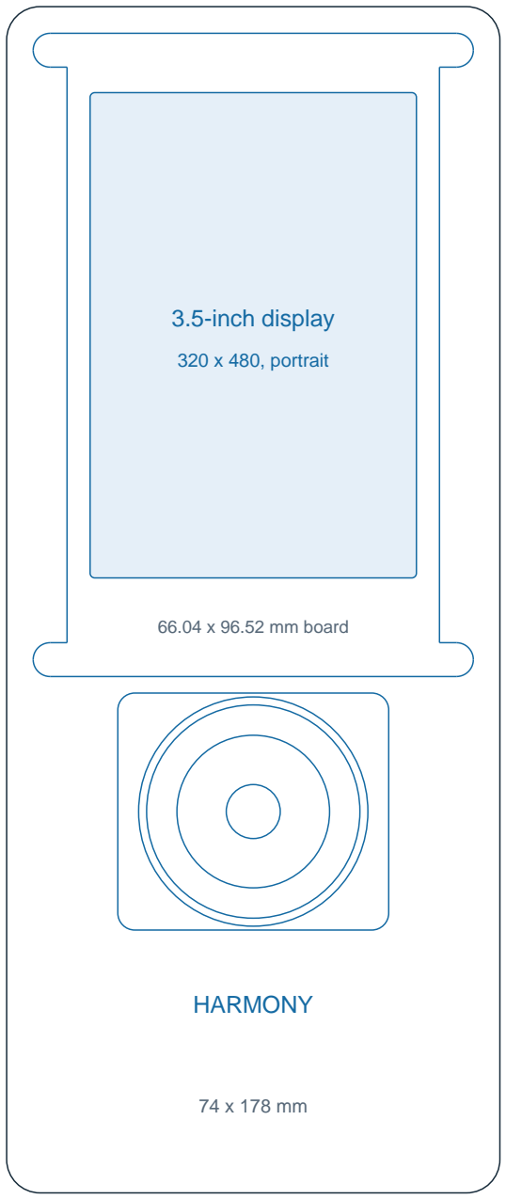
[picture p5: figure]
3.5-inch display; 320 x 480, portrait; 66.04 x 96.52 mm board; HARMONY

Placement B | 21 September 2026 | Print at Actual Size / 100%; disable Fit. | 1

74 mm

12 mm SHORTER

Previous complete study: 190 mm. This arrangement: 178 mm.
Width remains 74 mm.
Still a large player; try it in hand.

WHAT CHANGED

ANO board rotated 90 degrees. Antenna location taken from CAD. Feather moved closer to controls. USB connector faces the left side.

PRINTABLE SIZE DUMMY

74 x 178 x 28 mm overall.
Print STL at 100%, flat back down. Screen and wheel are recessed cues. It has no electronics cavity.
Depth and button feel are assumed.

CHECK BEFORE ROUTING

Pocket fit and thumb reach.
Real socket and display heights. Cable bends and plug clearances. Carrier antenna cutout and RF.

50 mm: check with a ruler

Paper and solid dummy check size only. Neither is a finished electronics enclosure.

# Planar placement and radio reservation

Front view; rear reservations overlap the display in projection. Z-stack is not validated.

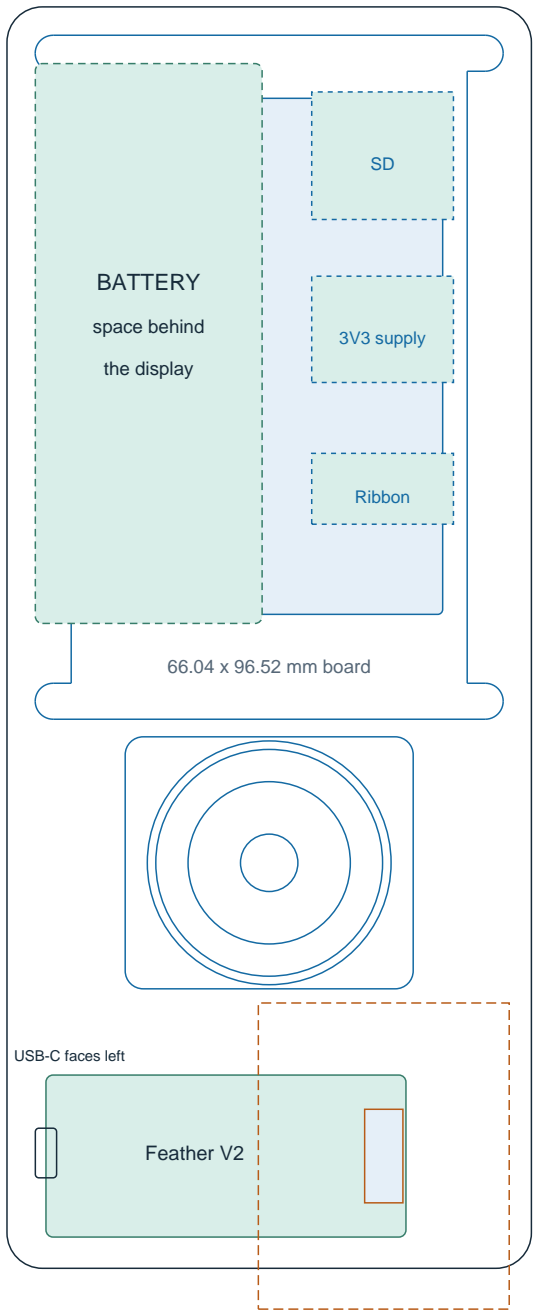
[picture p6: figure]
66.04 x 96.52 mm board; BATTERY; space behind; the display; 3V3 supply; Ribbon; Feather V2; USB-C faces left

Placement B | 21 September 2026 | Print at Actual Size / 100%; disable Fit. | 2

74 x 178 mm proposal

Feather board: 50.8 x 22.86 mm. Bottom margin: 4.41 mm.
Controls-to-orange-zone gap: 2 mm.

ORANGE: 15 mm HALO

Based on vendor antenna rectangle: 5.4 x 13.2 mm on the Feather.
Other module boxes stay outside. Feather socket pads enter this zone. Carrier cutout/copper review remains.

THIS IS NOT AN RF PASS

Halo extends 5.76 mm below shell. Plastic and hand effects untested. The full 3-D clearance is unverified. Final range/throughput tests remain.

CABLE AND BATTERY SPACE

Use upper ANO QT connector; plug/bend volume still unmodeled. Reserve 32 x 79 x 10.5 mm for pack. USB first; no battery connection.

50 mm: check with a ruler

Espressif recommends antenna overhang/clearance and testing in the final housing. See page 3.
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

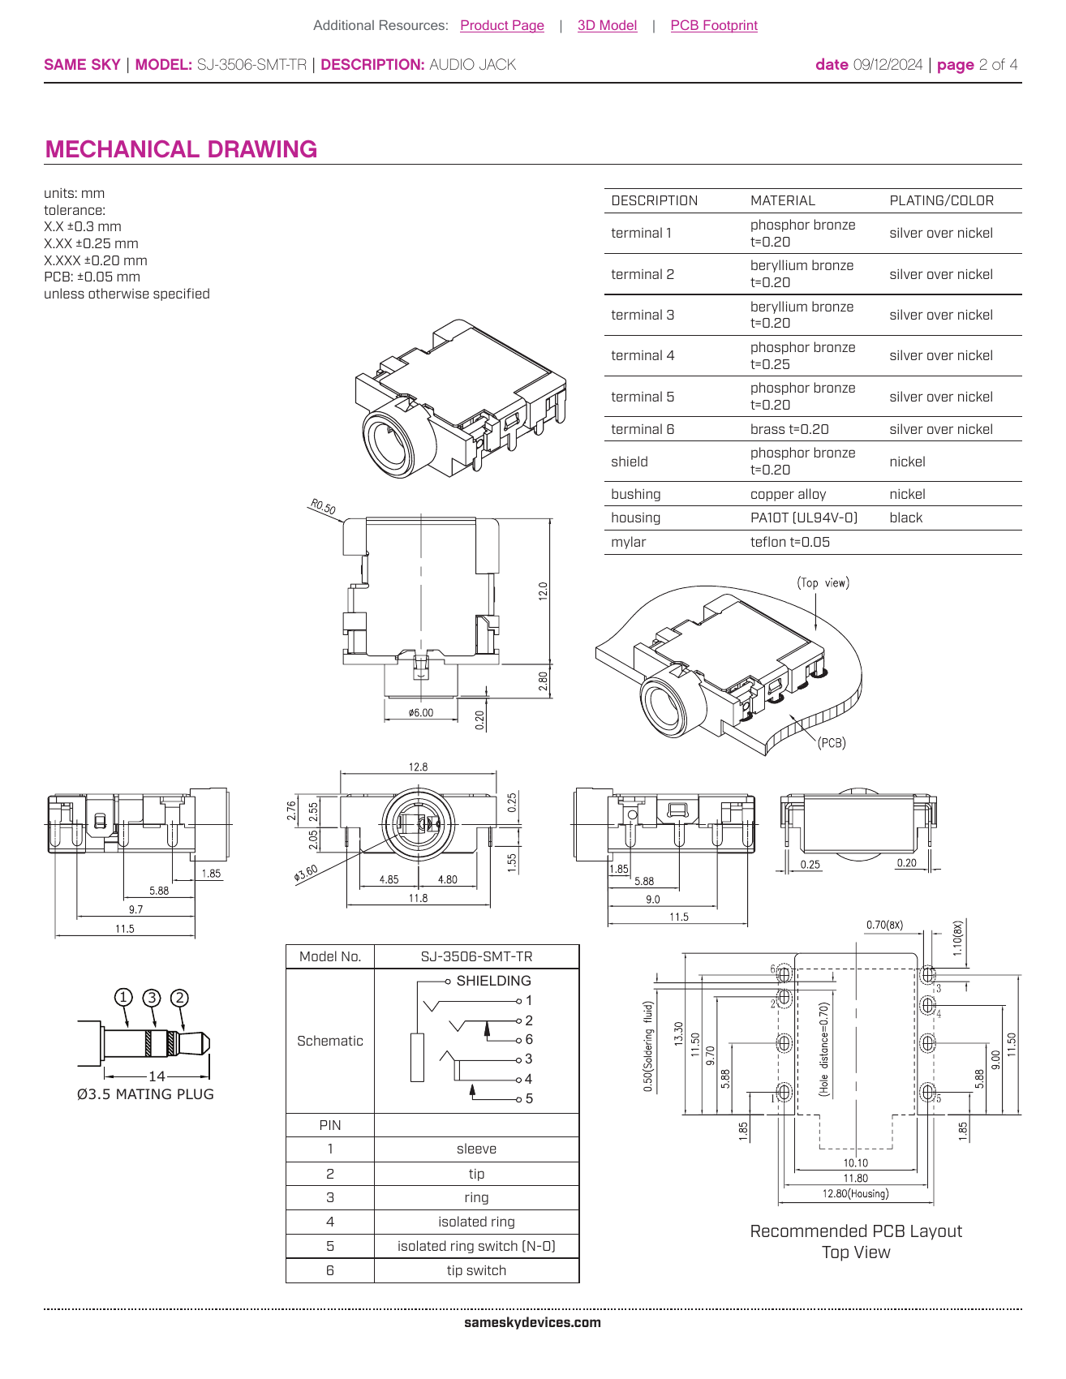
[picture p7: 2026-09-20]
hardware/reviews/harmony-r2/sources/SJ-3506-SMT-TR-p2.png

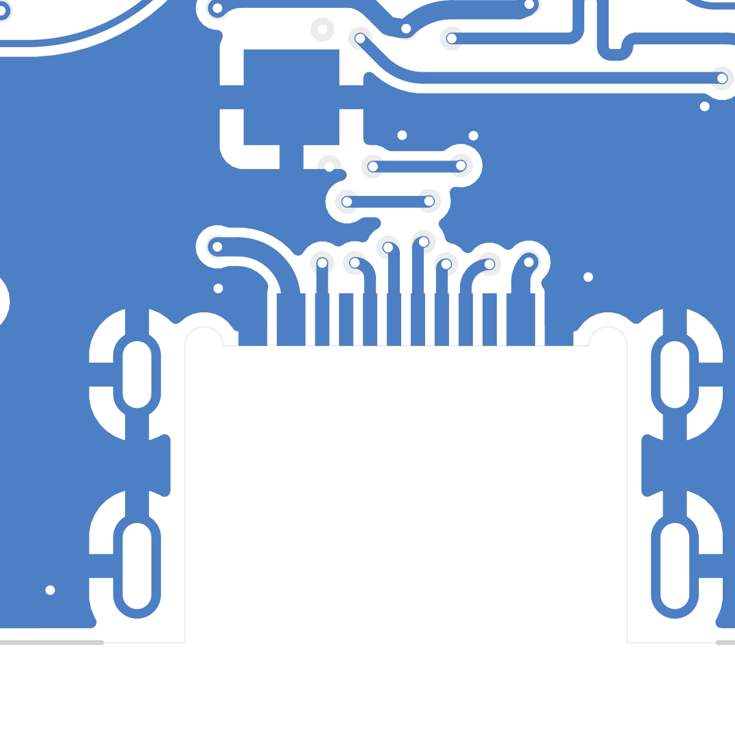
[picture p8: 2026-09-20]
hardware/reviews/harmony-r2/usb-cutout-detail.svg.png

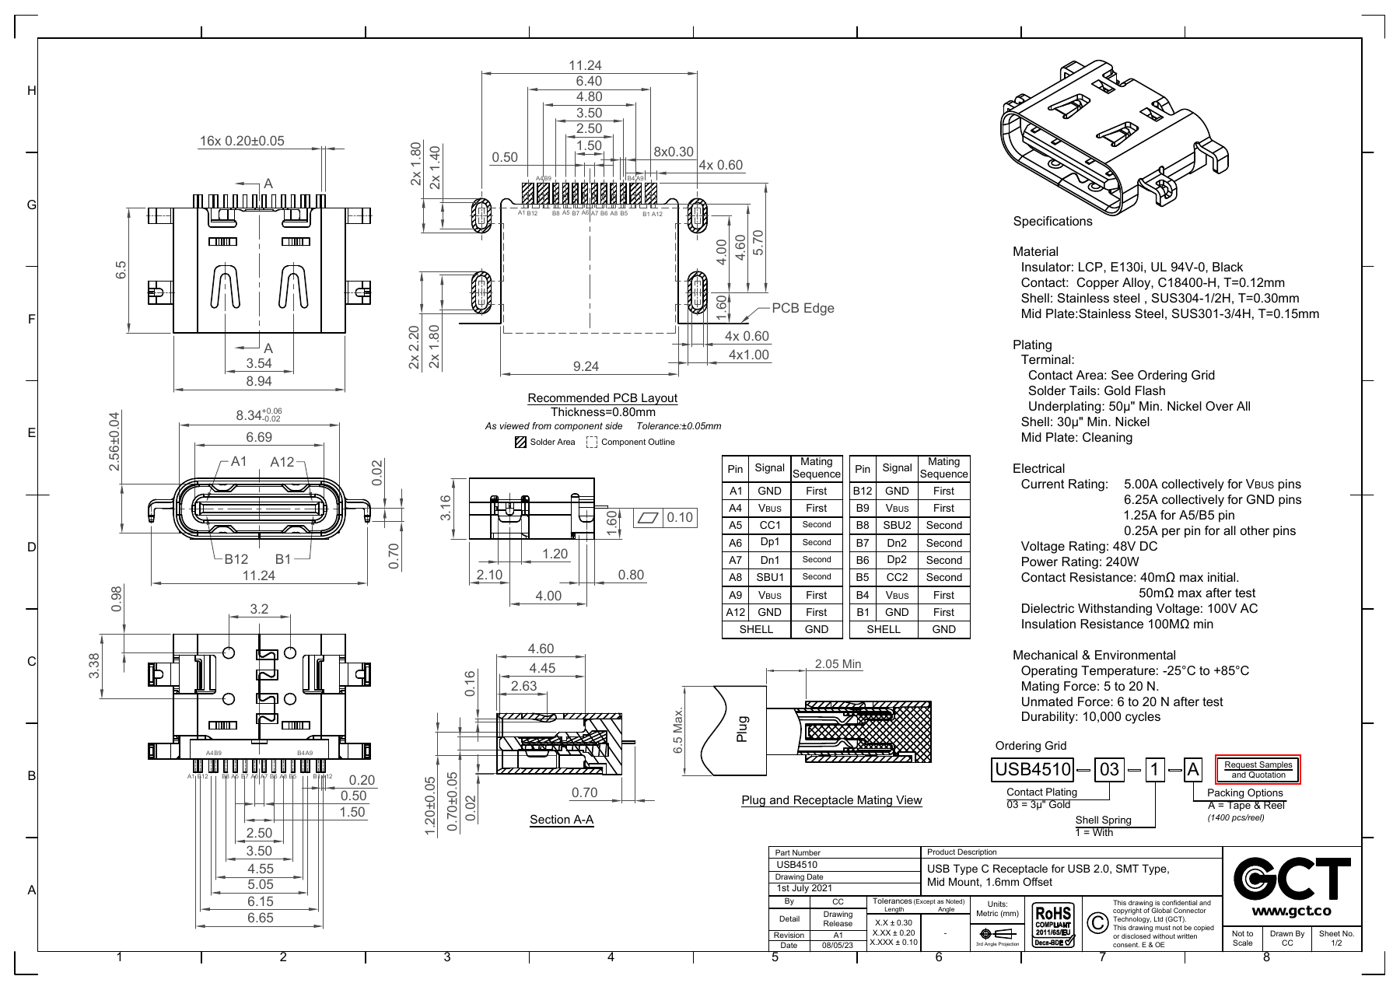
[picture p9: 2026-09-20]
hardware/reviews/harmony-r3/sources/USB4510-page1.png

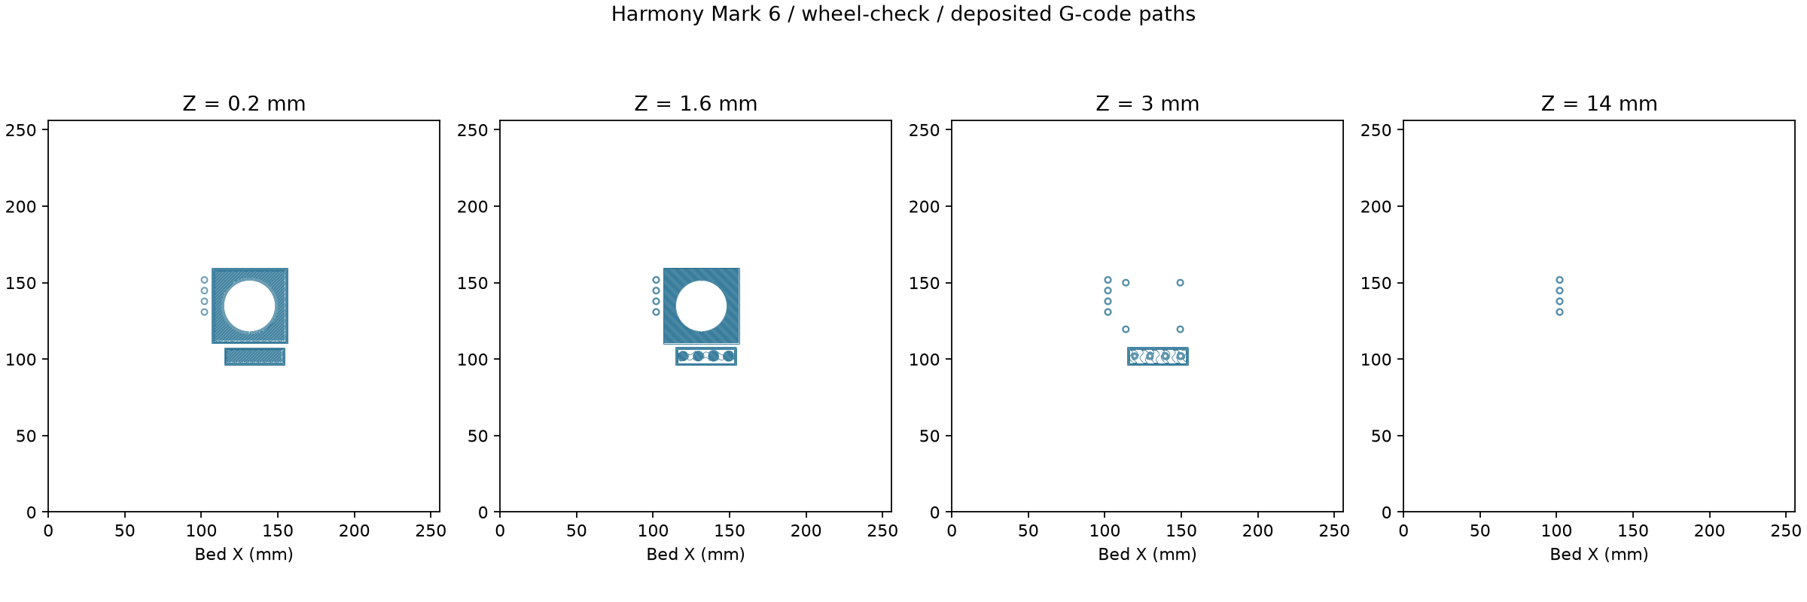
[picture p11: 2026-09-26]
enclosure/mark-6/fit-rev-b/slicing/wheel-check/toolpath-review.png

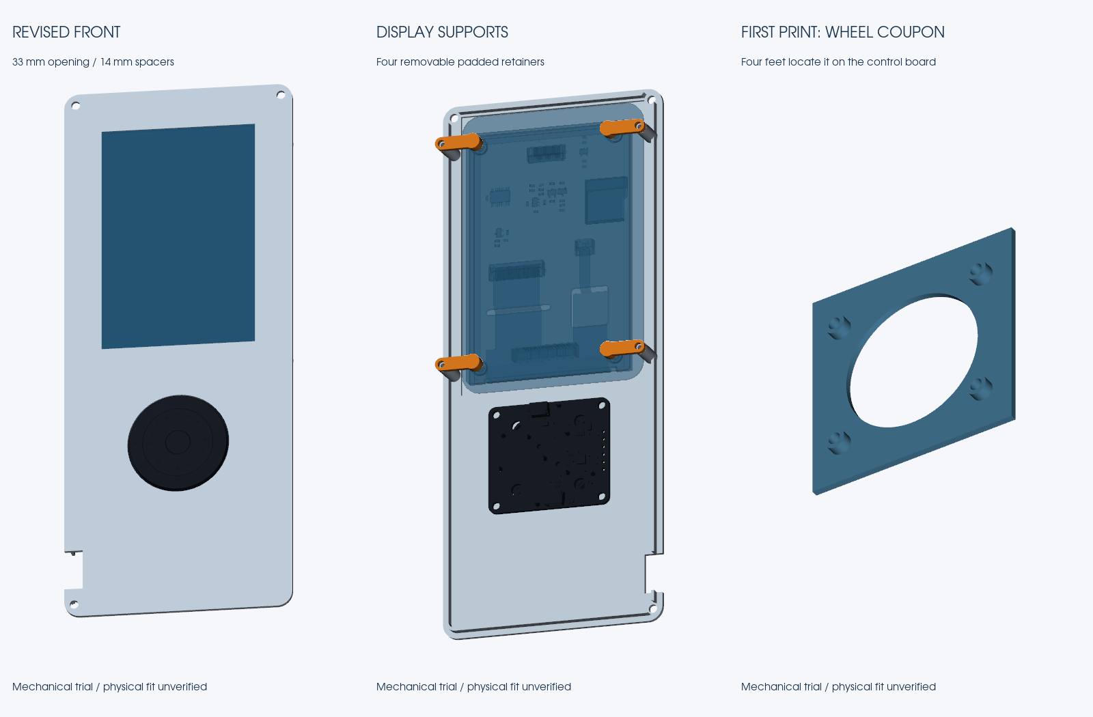
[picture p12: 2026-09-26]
enclosure/mark-6/fit-rev-b/preview/revision-b.png

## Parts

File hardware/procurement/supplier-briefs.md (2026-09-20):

# Harmony supplier briefs

HARMONY-9. Drafts for review, prepared September 13, 2026. Neither brief has been sent. These describe quote scope; they do not authorize fabrication or component substitutions.

## Board assembly quote

Please quote 1, 2, and 5 complete sets of Tangara electronics. Each set contains one mainboard and one faceplate. Quote the two board types separately, showing bare-board minimums, assembled quantities, unused boards, setup charges, component costs, final assembly, programming, testing, and shipping to the Pittsburgh, Pennsylvania area, USA.

The starting reference is Cool Tech Zone's open hardware at `https://codeberg.org/cool-tech-zone/tangara-hw`, commit `9853b4a1dc8a0e3ea3ec75450522e42df12eaa52`. Mainboard and faceplate are nominally 1.6 mm with ENIG. Preserve each board's copper stack-up and dimensions; the reference mainboard has four copper layers. Retain original antenna clearance, mounting holes, and connector positions. Please flag every unavailable component and proposed substitute, with its datasheet and footprint difference, before purchase or assembly.

Please include procurement and final attachment of the EastRising ER-TFT018-4 bare display and Vybronics VC1034B018F ERM motor, or list any consigned parts required. Include all connectors, through-hole work, switches, and the specified DNP population. Use a three-wire protected LiPo configuration with real NTC sensing; the battery-emulation resistor R1 remains unpopulated. Battery charge-current settings must be reconciled with the selected pack before release.

Please quote SAMD bootloader installation through SWD, SAMD application and ESP32 flashing, and functional inspection. The final programming package will include verified binaries, hashes, addresses, and expected checks. If you cannot perform programming or display/motor attachment, identify that clearly rather than treating those operations as included.

Requested test scope: optical inspection, solder/short inspection, startup and USB enumeration, display, SD access, controls, haptics, wired output, and Bluetooth playback using the supplied test procedure. Battery charging and NTC behavior require the selected pack or an agreed test fixture. Please identify fixture/setup costs and any test you cannot perform. Return the approved final BOM and placement records with the assemblies.

Before this draft can become a submitted fabrication request, Codex must reconcile the actual BOM/placement files, generate or retrieve matching Gerbers/drills, review ERC/DRC, freeze the firmware pair, and attach display/battery drawings. The designer's linked production ZIP currently requires forum access; the local schematic source is available, but that ZIP has not been authenticated or inspected. Do not describe the current reference snapshot as fabrication-approved.

Primary route: [PCBWay](https://www.pcbway.com/Order/QuickOrderOnline). Comparison route: [JLCPCB](https://jlcpcb.com/pcb-assembly). No supplier account or contact information has been submitted.

## Battery sample quote

Please confirm whether five LP574459 samples are currently available, including protection circuitry, a 10 kΩ NTC, and a JST-manufactured PHR-3 three-position connector. Please quote sample cost, harness customization, lead time, and lawful shipment to Pennsylvania, USA. This is a one-device prototype; a production MOQ in the thousands is not suitable.

Please supply a drawing showing maximum finished pack thickness, width, and length, including the protection board, seams, tape, and cable exit; available lead lengths; the connector mating-view pin assignment; NTC resistance at 25°C and its resistance/temperature curve; charge/discharge limits; protection thresholds; and shipping test documentation for the exact pack. The advertised 5.7 × 44 × 59 mm cell dimensions are insufficient to establish enclosure fit.

The pack is for a 4.2 V charge-voltage, single-cell MCP73871 system. Connector pin order must match the supplied Tangara J7 drawing; do not assume that a three-pin JST-PH connector uses a universal polarity. Please provide a proposed harness drawing for review before manufacture. The final case will be fitted to the reviewed finished-pack dimensions and its required clearance.

Candidate source: [LiPol LP574459](https://www.lithium-polymer-battery.net/lithium-polymer-battery-lp574459-2000mah-3-7v-7-4wh-with-pcm-and-ntc-and-wires/). If stocked samples are unavailable, report that rather than quoting a mass-production run as the only option.

## Cross-references

- [Shopping list](README.md)
- [Implementation plan](../../docs/Harmony-2026-implementation-plan.md)
- [Pinned electronics](../tangara-reference/README.md)
- HARMONY-9; HARMONY-8

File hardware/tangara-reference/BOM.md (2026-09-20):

# Bill of Materials

This is a list of every part needed to assemble one Tangara.

| Component | Manufacturer + part number |
|---|---|
| Mainboard PCB | See `tangara-mainboard` | 
| Faceplate PCB | See `tangara-faceplate` |
| Touchwheel cover (0.6mm FR4)  | See `touchwheel-cover` |
| 15 pos 0.5mm pitch FFC cable  | Samtec FJH-15-R-03.00-4 |
| 4x 6mm M2 standoffs | Wurth 970060244 |
| 4x 14mm countersunk M2 screws |	Accu SHK-M2-14-V2-A2 |
| 4x 8mm countersunk M2 screws  |	Accu SHK-M2-8-V2-A4 |
| Case top half | See `case-v2` |
| Case bottom half | See `case-v2` |
| Switch cover | See `case-v2` |
| 2x Button covers | See `case-v2` |
| SD card cover | TBD |
| 3-pin 2200mAh 604560 LiPo | EcoCell LIP2-001 |
| Haptic motor | TBD |

We're currently finalising our production v2 case design, including the SD card
cover. Full sources for these will be available once they're finished.

Notes on selecting alternatives for specific parts are given below.

## Display

The display is considered a part of the faceplate, but there's enough options
for sourcing that it's worth a few notes here.

 - For production, we're using ER-TFT018-4 from EastRising Technology Co.
 - [Adafruit's JFT-1800](https://www.adafruit.com/product/618) panel should also work fine.
 - Most ST7735R / ST7735S displays available on AliExpress should work fine.

## FFC Cable

For all current mainboard and faceplate revisions, we use an FFC connector with
tin plated contacts. You should therefore try to pick an FFC cable that has tin
plated contacts, to avoid corrosion.

Aside from the Samtec cable listed about, you might also consider:

 - Molex 98266-0836
 - GCT 05-15-D-0076-A-4-06-4-T

## Screws

Any 14mm and 8mm countersunk M2 screws will be fine. We've used Torx head for
our production units because we're big nerds, but you can often find hex and
Phillips head screws easily from local suppliers.

## Battery

For the battery, note that a 2-pin cell may be compatible if R1 on the
mainboard PCB is populated with a 10k 0603 resitor. We recommend sourcing a
suitable battery locally, as international shipping of LiPo batteries can be
difficult.

## Haptics

Tangara's haptic motor driver supports both LRA (closed and open-loop) and ERM
haptic motors, so sourcing a compatible motor is very easy. We'll update this
BOM once we've locked in our production motor, but some compatible choices are:

 - Vybronics Inc. VG0832022D (LRA)
 - Vybronics Inc. VC1034B018F (ERM)
 - Adafruit 1201 (ERM)
 - DFRobot FIT0774 (ERM)

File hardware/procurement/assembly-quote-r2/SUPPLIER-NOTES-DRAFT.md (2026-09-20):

# Draft supplier assembly and quote notes

Please quote one, two, and five complete Tangara electronics sets from the attached pinned-source derivatives. Each set contains one mainboard and one faceplate. Break out bare-board fabrication, assembly setup, component procurement, through-hole/manual work, display and haptic attachment, programming, inspection, unused boards, freight, and taxes. Return separate pricing for each board type and each complete-set quantity.

Use the per-board BOM quantities as the installed quantity authority. Keep all rows in the DNP and non-purchased structures file out of procurement and placement. Do not substitute any part without a part number, datasheet, availability, price, footprint comparison, and written approval. Keep the mainboard ESP32 antenna clearance free of copper and assembly material.

The faceplate display is ER-TFT018-4 for quote comparison only. Its electrical mapping is confirmed, but its mechanical release is on hold. Please state whether you can procure and solder the bare FPC panel after drawing approval. Do not quote an ST7735 breakout board. Attach one VC1034B018F motor to faceplate pads J1/J2; those pad references are not additional components.

Quote ENIG and nominal 1.6 mm finished thickness. Preserve the native four-layer mainboard and two-layer faceplate stack-ups. Report your proposed stack-up, controlled dimensions and tolerances, surface finish specification, solder-mask color, legend color, panelization, coupons/tooling rails, impedance assumptions, via treatment, and any departures from the source before release.

Programming is a separately priced operation pending final approval of `PROGRAMMING-NOTES-DRAFT.md`. A blank ATSAMD21E18A-AF requires the raw Tangara bootloader through 3.3 V SWD, BOOTPROT set for 8 KiB, application installation, and verification. ESP32 programming uses seven address-specific images. Do not program from filenames alone; verify every supplied hash and approved instruction revision.

Requested inspection and functional-test pricing: AOI/visual inspection, shorts and rails, USB enumeration in both Type-C orientations, display output, SD read/write, wheel and center-button input, side buttons, haptics, wired audio, Bluetooth pairing/playback/reconnect, SAMD firmware version, shutdown, and charge-state behavior. Battery/NTC and charge-current tests remain fixture-dependent until the pack is approved. List excluded tests and fixture costs explicitly.

This draft is for review and has not been sent.

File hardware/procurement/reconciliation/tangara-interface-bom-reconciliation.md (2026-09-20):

# Tangara interface and BOM reconciliation

Review date: 2026-09-14  
Pinned hardware source: Cool Tech Zone `tangara-hw` commit `9853b4a1dc8a0e3ea3ec75450522e42df12eaa52`

This is evidence for an assembly quote, not a released manufacturing BOM. It reconciles the battery and display interfaces and records BOM defects that could change an assembly quotation. It does not clear substitutions, fabrication, or purchasing.

## Battery connector J7

The populated board header is JST **S3B-PH-K-S(LF)(SN)**, a side-entry, through-hole, three-circuit PH-series header on the mainboard back. The PCB footprint and official JST drawing agree on 2.0 mm pitch. JST's drawing identifies the mating housing family as PHR and numbers circuit 1 from the marked end when viewed from the connector mounting surface.

The routed PCB, rather than wire color convention, is authoritative for the required pack harness:

| J7 circuit | Board net | Required pack lead |
| --- | --- | --- |
| 1, marked end | `/Power/NTC` | Thermistor sense |
| 2, center | `GND` | Cell negative and thermistor return |
| 3 | `Net-(J7-Pin_3)`, connected to MCP73871 `VBAT` and `VBAT_SENSE` | Protected cell positive |

The selected three-wire pack must therefore terminate **NTC / negative / positive** at J7 circuits **1 / 2 / 3**. A claim that a pack has a PHR-3 connector is insufficient without a drawing or continuity check proving this circuit order. Harness wire colors are not an acceptable release criterion.

Power-sheet R1 is a 10 kΩ 0603 resistor explicitly marked DNP and annotated for two-pin batteries only. With a real pack thermistor, R1 remains unpopulated. Populating it in parallel with the pack thermistor would distort the effective NTC resistance and therefore the charger's temperature-qualification thresholds. Used alone with a two-wire pack, it intentionally substitutes a fixed in-range resistance and removes actual cell-temperature sensing.

The charger is MCP73871-2CCI/ML. Microchip specifies an internal 50 µA THERM bias intended for common 10 kΩ NTC thermistors and typical qualification thresholds of 1.24 V and 0.25 V. The datasheet also permits a fixed 10 kΩ THERM-to-VSS resistor only when temperature monitoring is not required. Harmony's quote requires real pack sensing, so the thermistor's **R25, beta or full resistance-temperature table, mounting to the cell, lead insulation, and qualified charging window** must be supplied and electrically reviewed.

The power sheet fits R39 = 1 kΩ on PROG1 and annotates `I_REG = 1000V / R_PROG1`, which programs approximately **1 A maximum fast-charge current**. Microchip gives 900 to 1100 mA for PROG1 = 1 kΩ. This is a configured ceiling, not the current used for every USB source. In the pinned ESP32 firmware, an unset NVS `fastchg` value defaults to enabled and is sent to SAMD firmware version 4 or newer. The SAMD reads the USB-C current advertisement: detached selects the 100 mA USB setting; a 500 mA source selects the 500 mA USB setting; 1.5 A or 3 A sources select the 500 mA USB setting unless fast charge is enabled, in which case SEL chooses the adapter path whose current remains capped by PROG1 at approximately 1 A. Thus a new board with compatible v4 SAMD and default ESP32 settings can request the 1 A path when a capable source is detected, but it is not always at 1 A. The LP574459 candidate cannot be released until its finished-pack specification explicitly permits this charge current, or the PCBA charge-current setting is revised and verified. Nominal 2,000 mAh capacity alone does not establish an allowable 1 A charge rate.

## Historical battery mismatch

The upstream prose BOM line combines three attributes: “3-pin 2200mAh 604560” and “EcoCell LIP2-001.” Current procurement research shows those identifiers diverge: LIP2-001 is listed as a 2,000 mAh 113450 three-wire pack, while the 2,200 mAh 604560 is LIP2-200 and is listed with two wires and no thermistor. Neither identity is an exact, currently verified source part for J7.

LP574459 is therefore a candidate pack specification rather than an approved substitution. Before quote release obtain a dimensioned **finished-pack** drawing, protection-circuit limits, maximum continuous charge current, NTC curve, PHR-3 housing/contact details, cable length and exit, and an explicit 1/2/3 circuit-order drawing. The advertised 5.7 × 44 × 59 mm cell dimensions do not prove enclosure fit after protection PCB, seams, cable, and tolerances.

## Display interface

The faceplate PCB directly solders LCD1 to fourteen 0.8 mm-pitch pads. The PCB assigns:

| LCD pad | Board connection |
| --- | --- |
| 1 | No connection |
| 2 | GND |
| 3 | LED cathode, switched by the faceplate backlight transistor |
| 4 | LED anode, +3.3 V |
| 5 | GND |
| 6 | RESET |
| 7 | RS/DC |
| 8 | DATA, SPI controller input (`PICO`) |
| 9 | CLOCK (`SCLK`) |
| 10 | +3.3 V |
| 11 | +3.3 V |
| 12 | chip select (`CS`) |
| 13 | GND |
| 14 | No connection |

The custom footprint's fourteen pads are spaced 0.8001 mm nominally. Its drawing contains a 28.000 × 35.000 mm rectangle. That closely matches EastRising's published 28.03 × 35.04 mm active area, so the footprint graphic appears to encode the active area rather than the complete glass/FPC envelope. It must not be used as a full mechanical drawing.

EastRising's official ER-TFT018-4 datasheet confirms the exact fourteen-pin functional order in the table above, including NC at pins 1 and 14, both grounds, backlight polarity, SPI signals, VCC, IOVCC, and CS. It specifies VCC and IOVCC operating maxima of 3.3 V, so the board's +3.3 V connections to pins 10 and 11 are within the published range. The product page confirms 128 × 160 pixels, ST7735S, four-wire SPI, soldering FPC, 34.74 × 46.70 × 2.3 mm outline, 28.03 × 35.04 mm active area, typical 2.8 V supply, and 40 mA backlight. Electrical pin order is reconciled. A full-scale mechanical overlay of the datasheet outline/FPC copper geometry against the PCB and case has not been completed and remains a release hold.

The schematic calls LCD1 `JD-T1800` and has no MPN or datasheet. The prose BOM says production uses ER-TFT018-4 and also names Adafruit JFT-1800 as compatible. The quote should identify **ER-TFT018-4** explicitly and require the assembler to reconcile its current manufacturer drawing against the table above and the faceplate land pattern. “Any ST7735 display” is not an acceptable substitution because controller compatibility does not establish flex pinout or mechanical fit. Do not quote a breakout-board module.

## BOM and audit discrepancies relevant to quoting

The routed-board extractor in `extract_pcb_inventory.py` produces `pcb-physical-inventory.json`, with one record per footprint and the PCB's DNP, exclude-from-BOM, and exclude-from-position flags retained. It finds 124 mainboard footprints: 92 fitted, 5 carrying DNP, and 29 excluded from BOM. Two of the five DNP footprints, debug connectors J3 and J5, are also excluded from BOM; the quote-relevant unpopulated footprints are C17, C19, and battery-emulation R1. It finds 46 faceplate footprints: 37 fitted and 9 excluded from BOM. Ordinary annotated references are unique within each board; repeated placeholder references such as `G***` and `REF**` belong to excluded graphics.

The current `schematic-parts-audit.json` is not quantity-safe. It records repeated units and same-reference symbols from hierarchical sheets as separate physical rows. Examples include seven rows for U1 INA1620, five for U9 74CBTLV3257, four for R17 10 kΩ, and duplicate C11/C30/Q1 identities. Some repeated references also carry different values or MPNs because references are local to child sheets. Material examples are PCB U9 = PCA8575BS,118 while the audit assigns the U9 mux MPN, and PCB SW1/SW2 are respectively JS102011SAQN and EVQ-P40B3M while the audit reverses them. PCB C23 is 1 µF / GRM216R61C105KA88D while the audit's reference collision assigns a 10 µF part. Four other apparent MPN differences are trailing-space defects, not component changes. The generated PCB inventory retains every audit MPN candidate for each board/reference comparison, but the audit file must not be uploaded as an assembly BOM or counted by reference alone.

Every fitted mainboard footprint has an MPN field in the routed PCB. The faceplate reports 19 fitted footprints without MPNs, but 18 are board geometry or test structures: four plated mounting holes, two haptic wire pads, three capacitive electrodes, and nine test points. LCD1 is the only fitted, separately procured faceplate item lacking a PCB MPN. Its quote identity must be supplied as ER-TFT018-4 subject to the drawing overlay hold; it must not be inferred from the `JD-T1800` schematic value alone.

LCD1 has an empty schematic MPN even though procurement proposes ER-TFT018-4. Power-sheet DNP R1 has the malformed MPN field `0.1W 5%`, which is a rating/tolerance description rather than a manufacturer part number. Both need explicit treatment in a generated manufacturing BOM: LCD1 resolved by approved display drawing; R1 marked DNP with a valid alternate only if a two-wire battery design is deliberately adopted.

## Release holds

1. Archive the current ER-TFT018-4 dimensioned drawing and perform a full-scale overlay of its complete FPC copper and outline geometry against the faceplate footprint and case datum. The fourteen-pin electrical order is verified.
2. Obtain LP574459 finished-pack and harness drawings and electrical data. Verify J7 order NTC / GND / BAT+ at circuits 1 / 2 / 3 by drawing and incoming continuity inspection.
3. Confirm the pack accepts the fitted approximately 1 A charge setting, or approve and validate a new PROG1 resistor.
4. Generate a flat PCB-derived BOM and placement list that resolves hierarchical references and multi-unit symbols. Reconcile it to both routed PCBs; do not promote `schematic-parts-audit.json` into the RFQ.
5. Keep power-sheet R1 DNP for the required three-wire thermistor pack. Any two-wire fallback is a separate electrical decision and loses real cell-temperature qualification.

## Primary sources

- Pinned KiCad PCB and schematic files in `hardware/tangara-reference`, source lock above.
- [EastRising ER-TFT018-4 product page](https://www.buydisplay.com/1-8-inch-128x160-tft-lcd-display-4-wire-spi-st7735s-soldering-type-fpc), retrieved 2026-09-14.
- [EastRising ER-TFT018-4 datasheet, revision 1.0](https://www.buydisplay.com/download/manual/ER-TFT018-4_Datasheet.pdf), dated 2024-02-24 and inspected 2026-09-14.
- [JST PH connector manufacturer drawing](https://www.jst-mfg.com/product/pdf/eng/ePH.pdf), retrieved 2026-09-14.
- [Microchip MCP73871 data sheet DS20002090F](https://ww1.microchip.com/downloads/aemDocuments/documents/APID/ProductDocuments/DataSheets/MCP73871-Data-Sheet-DS20002090F.pdf), retrieved 2026-09-14.
- Upstream `BOM.md` and current `hardware/procurement/README.md` for the historical battery identity and proposed candidate.

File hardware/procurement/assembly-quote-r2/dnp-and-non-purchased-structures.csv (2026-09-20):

board | reference | value | footprint | classification | dnp | excluded_from_bom | excluded_from_position | board_only | supplier_instruction
faceplate | G*** | LOGO | footprints:oshwa-cert | PCB_FEATURE | False | True | True | True | Do not purchase or place
faceplate | G*** | LOGO | LOGO | PCB_FEATURE | False | True | True | True | Do not purchase or place
faceplate | H1 | MountingHole | MountingHole:MountingHole_2.2mm_M2_Pad_Via | PCB_FEATURE | False | False | True | False | Do not purchase or place
faceplate | H2 | MountingHole | MountingHole:MountingHole_2.2mm_M2_Pad_Via | PCB_FEATURE | False | False | True | False | Do not purchase or place
faceplate | H3 | MountingHole | MountingHole:MountingHole_2.2mm_M2_Pad_Via | PCB_FEATURE | False | False | True | False | Do not purchase or place
faceplate | H4 | MountingHole | MountingHole:MountingHole_2.2mm_M2_Pad_Via | PCB_FEATURE | False | False | True | False | Do not purchase or place
faceplate | J1 | + | TestPoint:TestPoint_Pad_D1.5mm | PCB_FEATURE | False | False | True | False | Haptic motor solder pads; motor appears once in external addendum
faceplate | J2 | - | TestPoint:TestPoint_Pad_D1.5mm | PCB_FEATURE | False | False | True | False | Haptic motor solder pads; motor appears once in external addendum
faceplate | REF** | ESD-Logo_6.6x6mm_SilkScreen | Symbol:ESD-Logo_6.6x6mm_SilkScreen | PCB_FEATURE | False | True | True | False | Do not purchase or place
faceplate | REF** | WEEE-Logo_4.2x6mm_SilkScreen | Symbol:WEEE-Logo_4.2x6mm_SilkScreen | PCB_FEATURE | False | True | True | False | Do not purchase or place
faceplate | REF** | CE-Logo_8.5x6mm_SilkScreen | Symbol:CE-Logo_8.5x6mm_SilkScreen | PCB_FEATURE | False | True | True | False | Do not purchase or place
faceplate | REF** | FCC-Logo_7.3x6mm_SilkScreen | Symbol:FCC-Logo_7.3x6mm_SilkScreen | PCB_FEATURE | False | True | True | False | Do not purchase or place
faceplate | REF** | UKCA-Logo_6x6mm_SilkScreen | Symbol:UKCA-Logo_6x6mm_SilkScreen | PCB_FEATURE | False | True | True | False | Do not purchase or place
faceplate | SW1 | BUTTON | faceplate-footprints:qtouch-button | PCB_FEATURE | False | False | False | False | Do not purchase or place
faceplate | SW2 | WHEEL | faceplate-footprints:qtouch-wheel | PCB_FEATURE | False | False | False | False | Do not purchase or place
faceplate | SW3 | GUARD | faceplate-footprints:qtouch-guard | PCB_FEATURE | False | False | False | False | Do not purchase or place
faceplate | TP1 | SCL | TestPoint:TestPoint_Pad_D1.0mm | PCB_FEATURE | False | False | True | False | Do not purchase or place
faceplate | TP2 | SDA | TestPoint:TestPoint_Pad_D1.0mm | PCB_FEATURE | False | False | True | False | Do not purchase or place
faceplate | TP3 | PICO | TestPoint:TestPoint_Pad_D1.0mm | PCB_FEATURE | False | False | True | False | Do not purchase or place
faceplate | TP4 | SCLK | TestPoint:TestPoint_Pad_D1.0mm | PCB_FEATURE | False | False | True | False | Do not purchase or place
faceplate | TP5 | CS | TestPoint:TestPoint_Pad_D1.0mm | PCB_FEATURE | False | False | True | False | Do not purchase or place
faceplate | TP6 | RS | TestPoint:TestPoint_Pad_D1.0mm | PCB_FEATURE | False | False | True | False | Do not purchase or place
faceplate | TP7 | LED | TestPoint:TestPoint_Pad_D1.0mm | PCB_FEATURE | False | False | True | False | Do not purchase or place
faceplate | TP8 | 3V3 | TestPoint:TestPoint_Pad_D1.0mm | PCB_FEATURE | False | False | True | False | Do not purchase or place
faceplate | TP9 | GND | TestPoint:TestPoint_Pad_D1.0mm | PCB_FEATURE | False | False | True | False | Do not purchase or place
faceplate | kibuzzard-63E31E51 | G*** | kibuzzard-63E31E51 | PCB_FEATURE | False | True | True | True | Do not purchase or place
faceplate | kibuzzard-63E31E57 | G*** | kibuzzard-63E31E57 | PCB_FEATURE | False | True | True | True | Do not purchase or place
mainboard | C17 | 100pF | Capacitor_SMD:C_0603_1608Metric | DNP | True | False | False | False | DNP; leave pads unpopulated
mainboard | C19 | 100pF | Capacitor_SMD:C_0603_1608Metric | DNP | True | False | False | False | DNP; leave pads unpopulated
mainboard | G*** | LOGO | footprints:star_small | PCB_FEATURE | False | True | True | True | Do not purchase or place
mainboard | G*** | LOGO | footprints:star_small | PCB_FEATURE | False | True | True | True | Do not purchase or place
mainboard | G*** | LOGO | footprints:star_small | PCB_FEATURE | False | True | True | True | Do not purchase or place
mainboard | G*** | LOGO | footprints:star_small | PCB_FEATURE | False | True | True | True | Do not purchase or place
mainboard | G*** | LOGO | footprints:oshwa-cert | PCB_FEATURE | False | True | True | True | Do not purchase or place
mainboard | G*** | LOGO | footprints:sparkles | PCB_FEATURE | False | True | True | True | Do not purchase or place
mainboard | G*** | LOGO | footprints:sparkles | PCB_FEATURE | False | True | True | True | Do not purchase or place
mainboard | G*** | LOGO | footprints:star_small | PCB_FEATURE | False | True | True | True | Do not purchase or place
mainboard | G*** | LOGO | footprints:star_small | PCB_FEATURE | False | True | True | True | Do not purchase or place
mainboard | G*** | LOGO | footprints:star_small | PCB_FEATURE | False | True | True | True | Do not purchase or place
mainboard | G*** | LOGO | footprints:heart | PCB_FEATURE | False | True | True | True | Do not purchase or place
mainboard | G*** | LOGO | LOGO | PCB_FEATURE | False | True | True | True | Do not purchase or place
mainboard | G*** | LOGO | footprints:star | PCB_FEATURE | False | True | True | True | Do not purchase or place
mainboard | H1 | MountingHole | footprints:MountingHole_2.2mm_M2_Pad_Via2 | PCB_FEATURE | False | True | True | False | Do not purchase or place
mainboard | H2 | MountingHole | footprints:MountingHole_2.2mm_M2_Pad_Via2 | PCB_FEATURE | False | True | True | False | Do not purchase or place
mainboard | H3 | MountingHole | footprints:MountingHole_2.2mm_M2_Pad_Via2 | PCB_FEATURE | False | True | True | False | Do not purchase or place
mainboard | H4 | MountingHole | footprints:MountingHole_2.2mm_M2_Pad_Via2 | PCB_FEATURE | False | True | True | False | Do not purchase or place
mainboard | J3 | JTAG | Connector_PinHeader_1.27mm:PinHeader_2x05_P1.27mm_Vertical_SMD | PCB_FEATURE | True | True | False | False | Do not purchase or place
mainboard | J5 | SWD | footprints:SAMDSWD | PCB_FEATURE | True | True | False | False | Do not purchase or place
mainboard | R1 | 10kΩ | Resistor_SMD:R_0603_1608Metric | DNP | True | False | False | False | DNP; leave pads unpopulated
mainboard | REF** | UKCA-Logo_6x6mm_SilkScreen | Symbol:UKCA-Logo_6x6mm_SilkScreen | PCB_FEATURE | False | True | True | False | Do not purchase or place
mainboard | REF** | CE-Logo_8.5x6mm_SilkScreen | Symbol:CE-Logo_8.5x6mm_SilkScreen | PCB_FEATURE | False | True | True | False | Do not purchase or place
mainboard | REF** | FCC-Logo_7.3x6mm_SilkScreen | Symbol:FCC-Logo_7.3x6mm_SilkScreen | PCB_FEATURE | False | True | True | False | Do not purchase or place
mainboard | REF** | ESD-Logo_6.6x6mm_SilkScreen | Symbol:ESD-Logo_6.6x6mm_SilkScreen | PCB_FEATURE | False | True | True | False | Do not purchase or place
mainboard | REF** | WEEE-Logo_4.2x6mm_SilkScreen | Symbol:WEEE-Logo_4.2x6mm_SilkScreen | PCB_FEATURE | False | True | True | False | Do not purchase or place
mainboard | TP3 | +5V | TestPoint:TestPoint_Pad_D1.0mm | PCB_FEATURE | False | True | True | False | Do not purchase or place
mainboard | TP4 | -5V | TestPoint:TestPoint_Pad_D1.0mm | PCB_FEATURE | False | True | True | False | Do not purchase or place
mainboard | TP5 | AMP_EN | TestPoint:TestPoint_Pad_D1.0mm | PCB_FEATURE | False | True | True | False | Do not purchase or place
mainboard | TP6 | AMP_MUTE | TestPoint:TestPoint_Pad_D1.0mm | PCB_FEATURE | False | True | True | False | Do not purchase or place
mainboard | TP7 | BAT | TestPoint:TestPoint_Pad_D1.0mm | PCB_FEATURE | False | True | True | False | Do not purchase or place

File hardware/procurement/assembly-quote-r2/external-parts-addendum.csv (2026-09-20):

item | mpn | qty_per_set | qty_for_1_set | qty_for_2_sets | qty_for_5_sets | assembly_scope
Board interconnect FFC | FJH-15-R-03.00-4 | 1 | 1 | 2 | 5 | Final assembly or return as kit; confirm tin contacts
Haptic motor | VC1034B018F | 1 | 1 | 2 | 5 | Attach to faceplate J1/J2 pads; do not count pads as components
Protected battery pack | LP574459 candidate | 1 | 1 | 2 | 5 | HOLD: finished dimensions, NTC curve, pin order, protection and 1 A charge rating unresolved

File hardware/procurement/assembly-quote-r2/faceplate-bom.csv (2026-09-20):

board | mpn | value | footprint | references | qty_per_board | qty_for_1_board | qty_for_2_boards | qty_for_5_boards | identity_status
faceplate | GCM188R71C104KA37J | 0.1uF | Capacitor_SMD:C_0603_1608Metric | C1 | 1 | 1 | 2 | 5 | SOURCE_MPN
faceplate | GRM319R61C226KE15D | 22uF | Capacitor_SMD:C_1206_3216Metric | C2 | 1 | 1 | 2 | 5 | SOURCE_MPN
faceplate | GRM216R61C105KA88D | 1uF | Capacitor_SMD:C_0805_2012Metric | C3 C4 C5 | 3 | 3 | 6 | 15 | SOURCE_MPN
faceplate | GT-F0509SR15-15SMT01 | MB Connector | faceplate-footprints:G-Switch GT-F0509SR15-15SMT01 | J4 | 1 | 1 | 2 | 5 | SOURCE_MPN
faceplate | ER-TFT018-4 | JD-T1800 | faceplate-footprints:JD-T1800 | LCD1 | 1 | 1 | 2 | 5 | CANDIDATE_HOLD_MECHANICAL
faceplate | PJC138K_R1_00001 | PJC138K | Package_TO_SOT_SMD:SOT-323_SC-70 | Q1 | 1 | 1 | 2 | 5 | SOURCE_MPN
faceplate | AC0603JR-0710KL | 10k | Resistor_SMD:R_0603_1608Metric | R1 R2 R3 R4 R5 R6 R7 R9 | 8 | 8 | 16 | 40 | SOURCE_MPN
faceplate | AC0603FR-131ML | 1M | Resistor_SMD:R_0603_1608Metric | R8 | 1 | 1 | 2 | 5 | SOURCE_MPN
faceplate | AT42QT2120-MMH | AT42QT2120 | Package_DFN_QFN:VQFN-20-1EP_3x3mm_P0.45mm_EP1.55x1.55mm | U1 | 1 | 1 | 2 | 5 | SOURCE_MPN
faceplate | DRV2605LDGST | DRV2605LDGS | Package_SO:VSSOP-10_3x3mm_P0.5mm | U2 | 1 | 1 | 2 | 5 | SOURCE_MPN

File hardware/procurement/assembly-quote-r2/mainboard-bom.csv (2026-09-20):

board | mpn | value | footprint | references | qty_per_board | qty_for_1_board | qty_for_2_boards | qty_for_5_boards | identity_status
mainboard | GRM21BR61C106KE15K | 10μF | Capacitor_SMD:C_0805_2012Metric | C1 C2 C3 C7 C18 C24 C25 C27 C32 C35 C42 | 11 | 11 | 22 | 55 | SOURCE_MPN
mainboard | GRM216R61C105KA88D | 1μF | Capacitor_SMD:C_0805_2012Metric | C4 C12 C23 C33 C41 | 5 | 5 | 10 | 25 | SOURCE_MPN
mainboard | GRM1885C1H272JA01J | 2700pF | Capacitor_SMD:C_0603_1608Metric | C6 C15 | 2 | 2 | 4 | 10 | SOURCE_MPN
mainboard | GCM188R71C104KA37J | 0.1μF | Capacitor_SMD:C_0603_1608Metric | C9 C13 C14 C30 C31 C34 C37 C39 C40 | 9 | 9 | 18 | 45 | SOURCE_MPN
mainboard | GRM319R61C226KE15D | 22μF | Capacitor_SMD:C_1206_3216Metric | C10 C16 C38 | 3 | 3 | 6 | 15 | SOURCE_MPN
mainboard | GRM32EC70J107ME15K | 100uF | Capacitor_SMD:C_1210_3225Metric | C29 | 1 | 1 | 2 | 5 | SOURCE_MPN
mainboard | BAT54C | BAT54C | Package_TO_SOT_SMD:SOT-23 | D4 | 1 | 1 | 2 | 5 | SOURCE_MPN
mainboard | SJ-3506-SMT-TR | SJ-3506-SMT | footprints:CUI_SJ-3506-SMT | J1 | 1 | 1 | 2 | 5 | SOURCE_MPN
mainboard | GT-F0509SR15-15SMT01 | FP Connector | footprints:G-Switch GT-F0509SR15-15SMT01 | J2 | 1 | 1 | 2 | 5 | SOURCE_MPN
mainboard | DM1AA-SF-PEJ(82) | SD_Card | Connector_Card:SD_Hirose_DM1AA_SF_PEJ82 | J4 | 1 | 1 | 2 | 5 | SOURCE_MPN
mainboard | USB4510-03-1-A | USB | footprints:GCT_USB4510-03-1-A_REVA | J6 | 1 | 1 | 2 | 5 | SOURCE_MPN
mainboard | S3B-PH-K-S(LF)(SN) | Battery | Connector_JST:JST_PH_S3B-PH-K_1x03_P2.00mm_Horizontal | J7 | 1 | 1 | 2 | 5 | SOURCE_MPN
mainboard | 1239AS-H-4R7M=P2 | 4.7μH | Inductor_SMD:L_1008_2520Metric | L1 L2 | 2 | 2 | 4 | 10 | SOURCE_MPN
mainboard | PMV48XPA2R | PMV48XPA2R | Package_TO_SOT_SMD:TSOT-23 | Q1 | 1 | 1 | 2 | 5 | SOURCE_MPN
mainboard | PJC138K_R1_00001 | PJC138K | Package_TO_SOT_SMD:SOT-323_SC-70 | Q2 Q3 | 2 | 2 | 4 | 10 | SOURCE_MPN
mainboard | AC0603JR-0710KL | 10kΩ | Resistor_SMD:R_0603_1608Metric | R2 R4 R5 R9 R10 R11 R12 R21 R22 R26 R30 R31 R32 R34 R35 R37 R38 R41 R49 R55 R57 R58 R59 R61 | 24 | 24 | 48 | 120 | SOURCE_MPN
mainboard | RR1220P-222-D | 2.2kΩ | Resistor_SMD:R_0805_2012Metric | R3 R8 | 2 | 2 | 4 | 10 | SOURCE_MPN
mainboard | RR1220P-561-D | 560Ω | Resistor_SMD:R_0805_2012Metric | R6 R15 | 2 | 2 | 4 | 10 | SOURCE_MPN
mainboard | AC0603FR-131ML | 1MΩ | Resistor_SMD:R_0603_1608Metric | R7 R50 R51 R56 | 4 | 4 | 8 | 20 | SOURCE_MPN
mainboard | RC0603DR-071KL | 1kΩ | Resistor_SMD:R_0603_1608Metric | R39 R42 | 2 | 2 | 4 | 10 | SOURCE_MPN
mainboard | JS102011SAQN | SW_SPDT | Button_Switch_SMD:SW_SPDT_CK-JS102011SAQN | SW1 | 1 | 1 | 2 | 5 | SOURCE_MPN
mainboard | EVQ-P40B3M | SW_Push | footprints:SW_EVQ-P4HB3B | SW2 SW3 | 2 | 2 | 4 | 10 | SOURCE_MPN
mainboard | INA1620RTWR | INA1620 | Package_DFN_QFN:QFN-24-1EP_4x4mm_P0.5mm_EP2.7x2.7mm_ThermalVias | U1 | 1 | 1 | 2 | 5 | SOURCE_MPN
mainboard | D5V0L2B3T-7 | D5V0L2B3T-7 | Package_TO_SOT_SMD:SOT-523 | U3 | 1 | 1 | 2 | 5 | SOURCE_MPN
mainboard | TLV75533PDBV | TLV75533PDBV | Package_TO_SOT_SMD:SOT-23-5 | U4 | 1 | 1 | 2 | 5 | SOURCE_MPN
mainboard | PE1605C4A6 | PE1605C4A6 | Package_TO_SOT_SMD:SOT-23-6 | U5 | 1 | 1 | 2 | 5 | SOURCE_MPN
mainboard | TPS65133DPDR | TPS65133 | footprints:SON40P300X300X80-13N | U7 | 1 | 1 | 2 | 5 | SOURCE_MPN
mainboard | PCA8575BS,118 | PCA8575 | Package_DFN_QFN:HVQFN-24-1EP_4x4mm_P0.5mm_EP2.1x2.1mm | U9 | 1 | 1 | 2 | 5 | SOURCE_MPN
mainboard | MCP73871-2CCI/ML | MCP73871 | footprints:QFN-20-1EP_4x4mm_P0.5mm_EP2.5x2.5mm_ThermalVias2 | U10 | 1 | 1 | 2 | 5 | SOURCE_MPN
mainboard | BD91N01NUX | BD91N01NUX | footprints:BD91N01NUX-E2 | U12 | 1 | 1 | 2 | 5 | SOURCE_MPN
mainboard | ATSAMD21E18A-AF | ATSAMD21E18A-AF | Package_QFP:TQFP-32_7x7mm_P0.8mm | U13 | 1 | 1 | 2 | 5 | SOURCE_MPN
mainboard | 74CBTLV3257PW-Q10J | 74CBTLV3257 | Package_SO:TSSOP-16_4.4x5mm_P0.65mm | U14 | 1 | 1 | 2 | 5 | SOURCE_MPN
mainboard | ESP32-WROVER-E-N16R8 | ESP32-WROVER-E | footprints:ESP32-WROVER | U15 | 1 | 1 | 2 | 5 | SOURCE_MPN
mainboard | TPS22948DCKR | TPS22948 | footprints:SOT65P210X110-6N | U16 | 1 | 1 | 2 | 5 | SOURCE_MPN
mainboard | WM8523GEDT/R | WM8523 | Package_SO:SSOP-20_4.4x6.5mm_P0.65mm | U17 | 1 | 1 | 2 | 5 | SOURCE_MPN

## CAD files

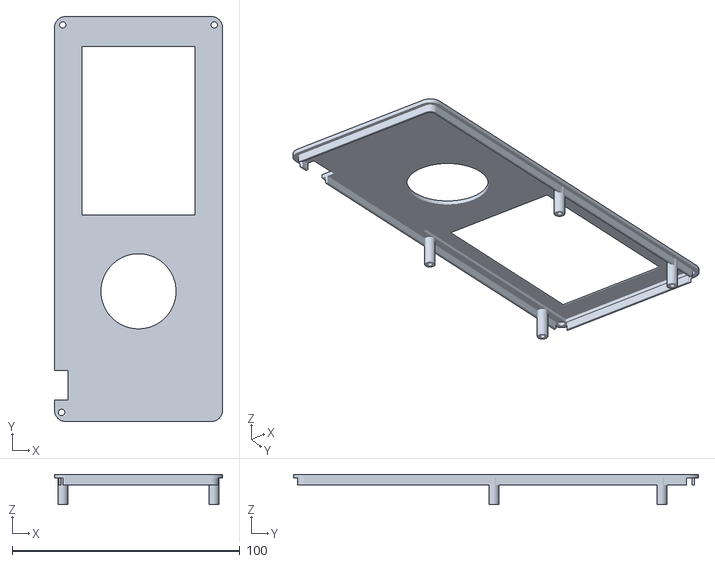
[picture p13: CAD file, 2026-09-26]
enclosure/mark-6/fit-rev-b/preview/assembled-front.stl
74.0 x 178.0 x 13.2

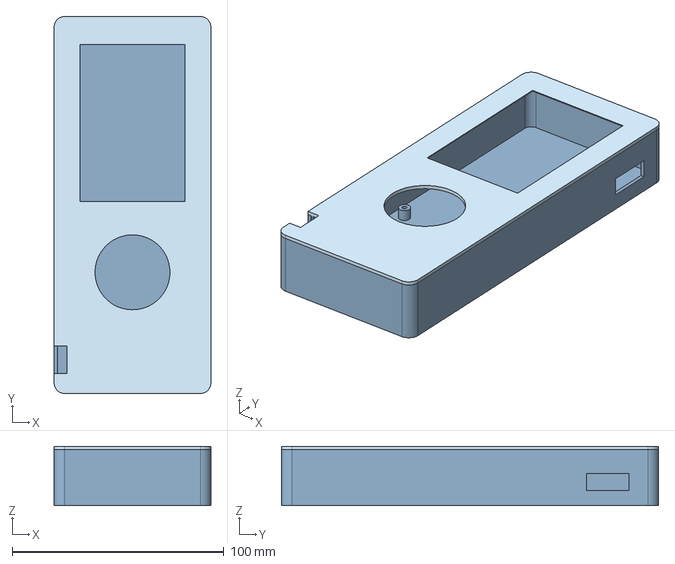
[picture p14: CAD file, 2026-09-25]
enclosure/mark-6/fit-prototype/cad/harmony-mark6-fit-assembly.step
74.0 x 178.0 x 28.0 mm
tray
front

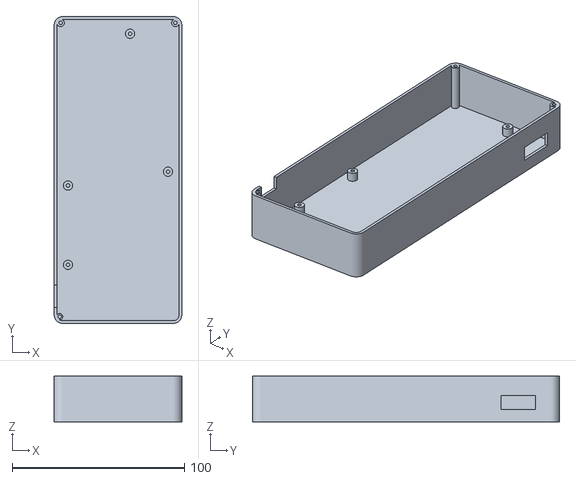
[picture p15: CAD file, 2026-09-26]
enclosure/mark-6/fit-rev-b/preview/assembled-tray.stl
74.0 x 178.0 x 26.4

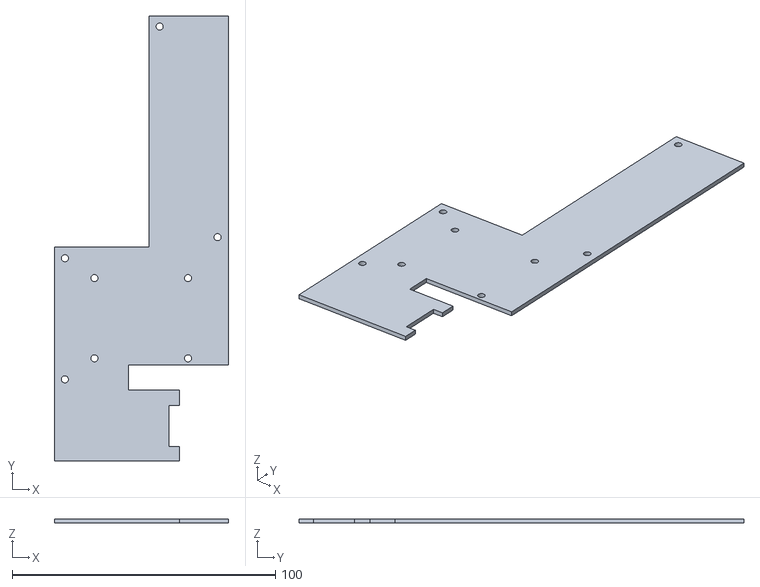
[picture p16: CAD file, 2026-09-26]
enclosure/mark-6/fit-rev-b/preview/assembled-gauge.stl
66.2 x 169.0 x 1.60

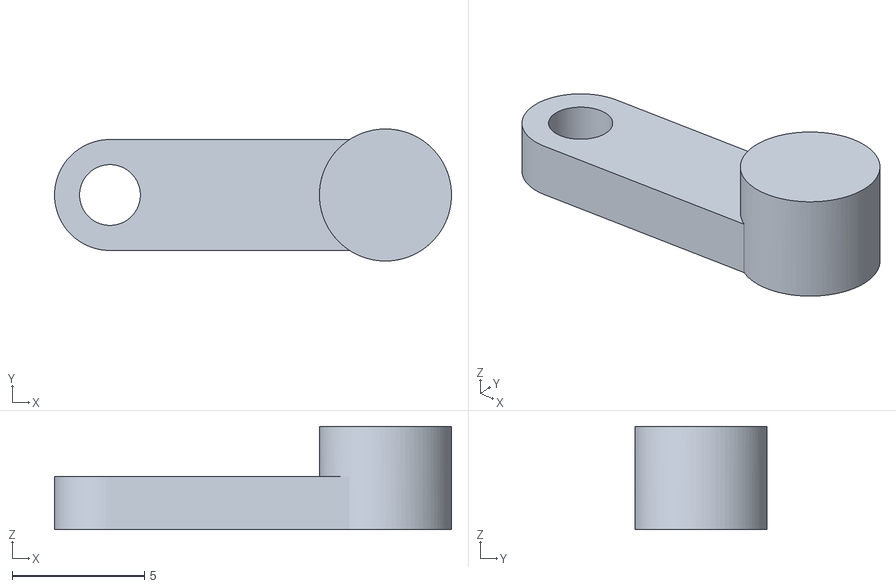
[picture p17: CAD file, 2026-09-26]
enclosure/mark-6/fit-rev-b/preview/assembled-retainer0.stl
15.0 x 5.00 x 3.90

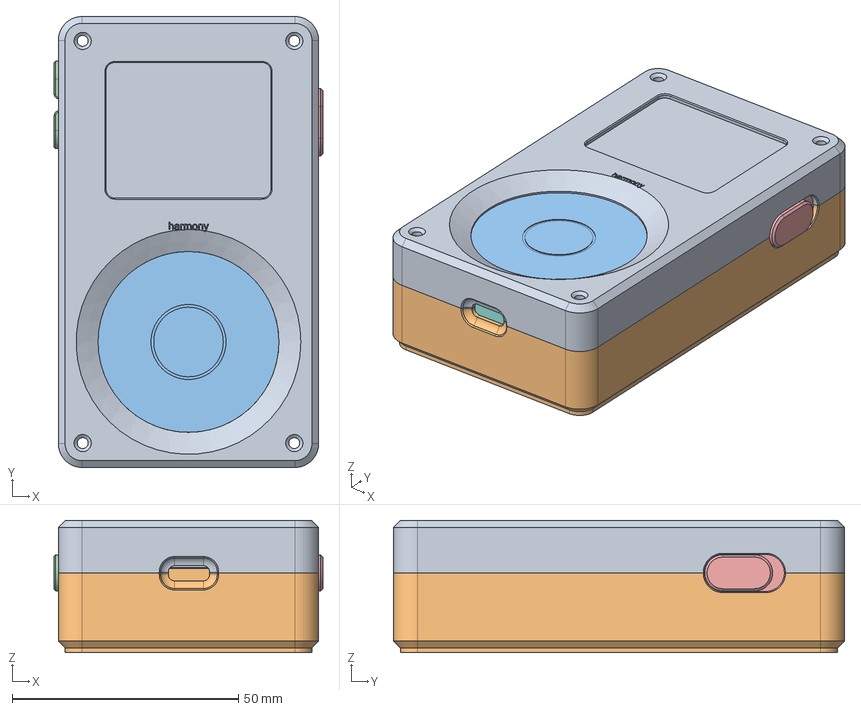
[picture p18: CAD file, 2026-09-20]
enclosure/harmony-r2-globtek/cad/assembly.step
59.4 x 99.8 x 29.2 mm

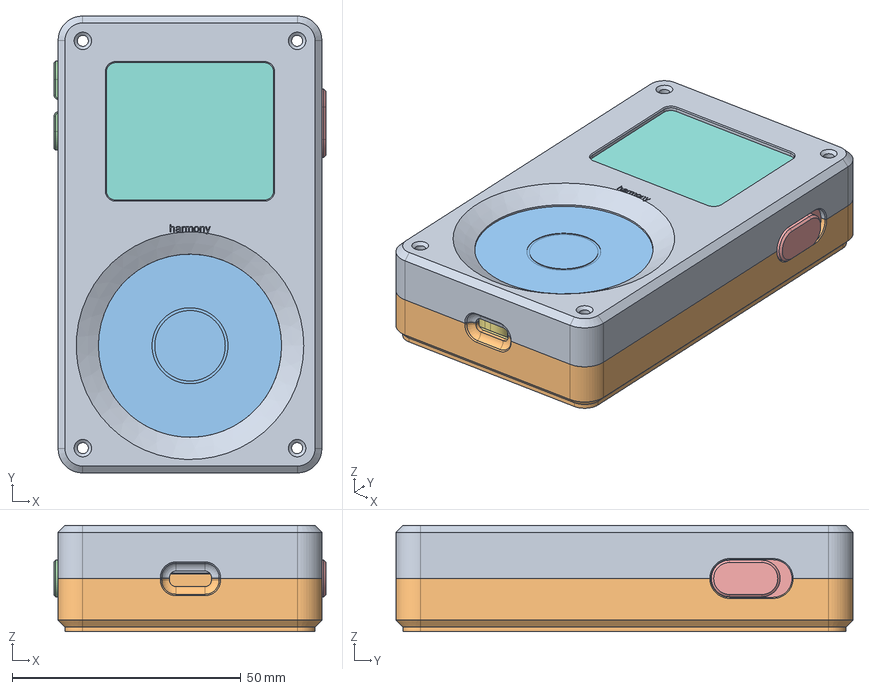
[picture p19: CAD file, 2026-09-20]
enclosure/harmony-r1/cad/enclosure-assembly.step
59.4 x 99.8 x 23.2 mm

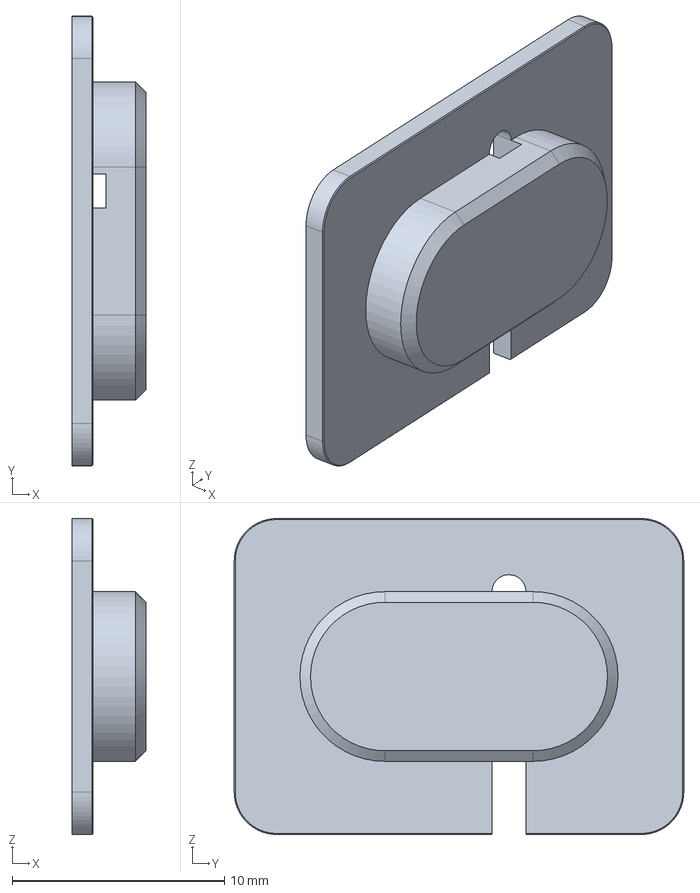
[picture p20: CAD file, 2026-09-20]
enclosure/harmony-r1/cad/hold-switch.step
3.50 x 21.2 x 14.9 mm

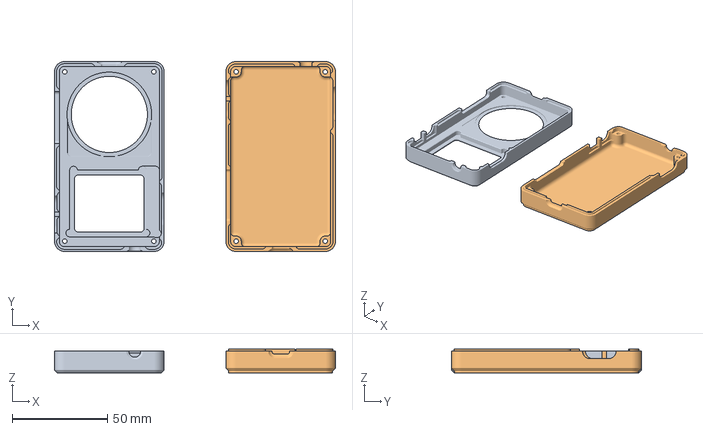
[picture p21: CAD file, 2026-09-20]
enclosure/harmony-r1/print/harmony-shells.3mf
147.6 x 99.8 x 12.6 mm
front
back

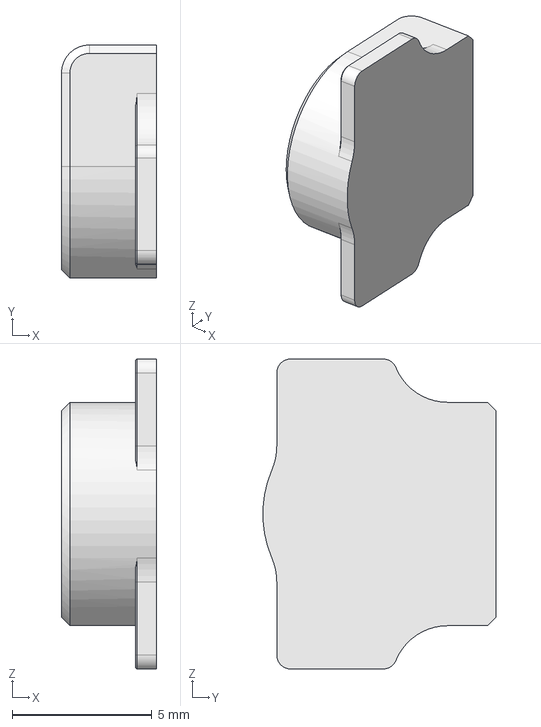
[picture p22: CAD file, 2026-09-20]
enclosure/harmony-r1/source/button.step
3.40 x 8.34 x 11.1 mm

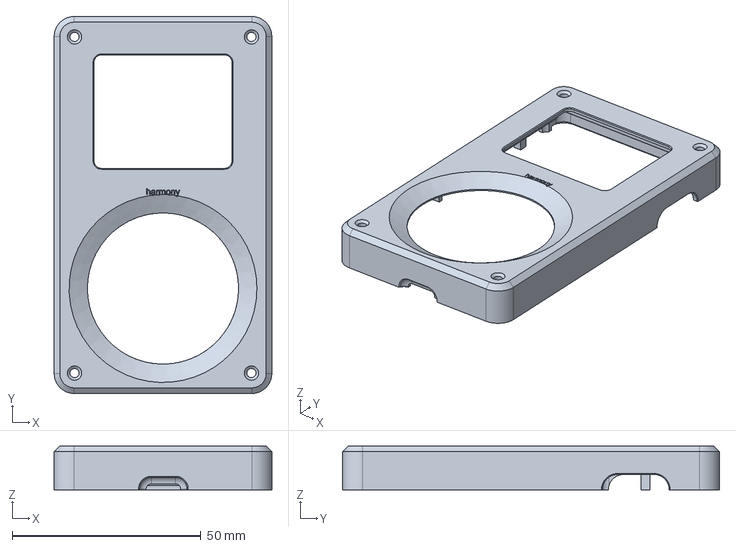
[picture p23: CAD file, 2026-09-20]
enclosure/harmony-r2-globtek/cad/front.step
57.6 x 99.8 x 11.6 mm

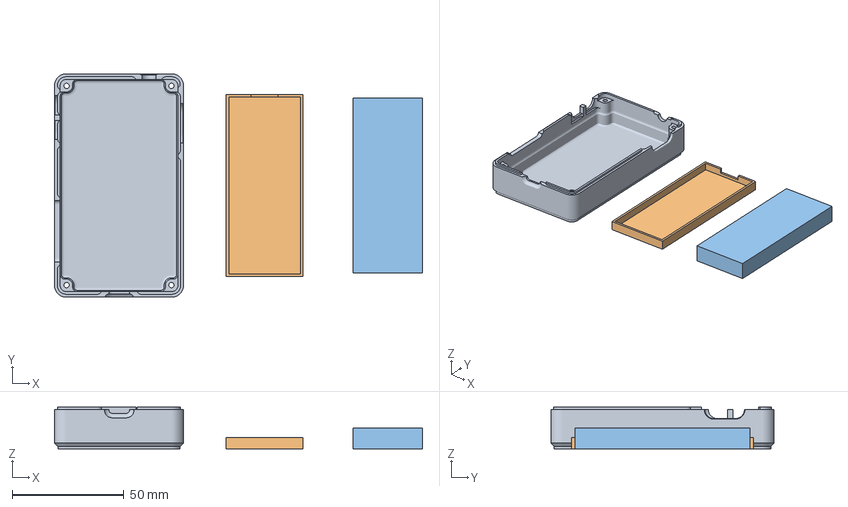
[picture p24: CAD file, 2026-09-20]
enclosure/harmony-r2-globtek/print/harmony-globtek-fit.3mf
164.3 x 99.8 x 18.6 mm
back
battery-cage
battery-dummy

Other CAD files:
enclosure/mark-6/fit-rev-b/cad/assembly.step
enclosure/mark-6/fit-rev-b/preview/assembled-retainer1.stl
enclosure/mark-6/fit-rev-b/preview/assembled-retainer2.stl
enclosure/mark-6/fit-rev-b/preview/assembled-retainer3.stl
enclosure/mark-6/fit-rev-b/preview/assembled-display.stl
enclosure/mark-6/fit-rev-b/preview/assembled-ano.stl
enclosure/harmony-r1/cad/back.step
enclosure/harmony-r1/cad/battery-cage.step
enclosure/harmony-r1/cad/battery-envelope-reference.step
enclosure/harmony-r1/cad/button-lower.step
enclosure/harmony-r1/cad/button-upper.step
enclosure/harmony-r1/cad/display-lens-reference.step
enclosure/harmony-r1/cad/fit-back.step
enclosure/harmony-r1/cad/fit-front.step
enclosure/harmony-r1/cad/front.step
enclosure/harmony-r1/cad/sd-caddy.step
enclosure/harmony-r1/cad/touch-cover.step
enclosure/harmony-r1/print/back.stl
enclosure/harmony-r1/print/battery-cage.stl
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

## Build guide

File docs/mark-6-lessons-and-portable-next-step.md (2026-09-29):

# Mark-6 lessons and the portable next step

September 27, 2026. Working recommendation following Dave's request to collect lessons, reconsider the Mark-6 carrier expense, and test battery operation before making Mark-7 compact. Hardware scope changes below are proposals; no battery wiring, charging test, carrier purchase or supplier cancellation occurred.

## September 28 adoption

Dave adopted [Mark-7 as the portable Bluetooth build](mark-7-portable-scope.md). Stop expanding Mark-6 hardware and preserve it as the working reference. Existing software acceptance carries forward. The ELEGOO perfboard, ample wire, soldering iron and multimeter are owned. SD access through a removable cover is sufficient. The speaker and DAC are excluded from the first portable build.

The battery and connector photos are retained in [inventory evidence](../hardware/mark-7/inventory-20260928/README.md). Dave reports the adapter cables and heat shrink purchased. Charging remains unqualified. The Feather charger has no battery-temperature input, and its voltage tolerance requires comparison against the pack maximum.

## Recommended sequence

Use Mark-6 to prove battery operation on the electronics that already play music. Use Mark-7 to package that working system into a smaller, secured enclosure for walking and car use. Preserve the current firmware, wiring records, enclosure work and approved web appearance. A new electronics architecture is not a prerequisite.

The Mark-6 carrier is optional for the demonstrated temporary-harness player. Keep its design available, but do not purchase it merely to tidy this bench. Revisit whether a small carrier is useful after the portable layout and power system are defined.

## What we learned

| Evidence | Lesson for the next build |
| --- | --- |
| Feather V2, LCD-slot SD and ANO controls work through a temporary harness | A manufactured carrier is not required to test the actual player behavior. Short secured wiring can remain a valid prototype assembly. |
| SD and LCD share SPI at 4 MHz; the integrated playback capture has no underrun/contention bytes | Separate buses are not required for this demonstrated workload. Keep bus access bounded and repeat load/endurance tests before making broader claims. |
| Original center input was missed during expensive drawing; priority/cache/partial redraw corrected it | Input scheduling and render work matter as much as the visual design. The final build also polls faster after observing short clicks miss the original cadence. |
| Existing RGB565 renderer reproduces the cream/green design with local fonts | Reuse the visual language and native renderer. Browser smoothness is not a hardware performance guarantee. Full-screen updates still take roughly 1.4 seconds on this bench. |
| Library, decoder, UI and Bluetooth are separate modules with host checks | Carry this software into the next case. Avoid rewriting proven playback to obtain a different exterior. |
| Loose fit checks established board/bezel/support alignment | Fit does not establish a carry-ready assembly. Retain boards, insulate exposed contacts, provide strain relief and preserve antenna clearance. |
| Purchased battery and earlier Tangara power work predate the Feather architecture | Recheck compatibility against the actual Feather and peripheral load. A purchased battery is useful inventory, not proof of a compatible charging system. |

## Why the designed carrier is more than cable cleanup

The existing carrier provides sockets and fixed interconnects, a separate SD socket/bus, a peripheral 3.3 V supply and power-good checks. It was designed for USB-only operation. It would require its own powered bring-up and firmware/pin-map qualification; a tidy board does not automatically improve an already working audio path or solve battery integration.

A wired Mark-6 could be enclosed if modules and connectors are mechanically retained, conductors are insulated, cables cannot pull on contacts, and the assembly closes without pressure on components or battery. That is an assembly task, not permission to pack loose jumper wiring under the lid. A fixture or simple printed bracket can be useful before buying a full PCB.

Source: [carrier design](../hardware/mark-6/carrier-rev-a/README.md), [power review](../hardware/mark-6/carrier-rev-a/power-review.md), [current bench](../firmware/mark-6/feather-player-bench/README.md).

## Battery proof on Mark-6

The Feather supports a single-cell Li-ion/LiPo input, onboard charging and USB/battery switchover. Its enable input controls the main 3.3 V regulator, while STEMMA QT uses a separately controlled supply. These board functions are a starting point, not a measurement of the complete player's power behavior. [Adafruit power guide](https://learn.adafruit.com/adafruit-esp32-feather-v2/power-management-2).

The retained GlobTek BL2200F9031781S1PCKT record specifies 3.7 V nominal, 2200 mAh, a three-wire connector and a temperature sensor. Its stated maximum charge voltage is 4.2 V, with 4.1 V recommended. Earlier Tangara charger/harness proposals must not be transferred unchanged to the Feather. Check the received pack, polarity, harness, charger current/termination and temperature arrangement before connection. [Manufacturer specification](https://spec.globtek.info/spec/?id=01t3a000005RUyzAAG&rohs_cert=1); retained exact drawing and selection record are in the vault's September 15 component-verification directory.

Proposed sequence:

1. Review the exact pack and Feather charging circuit; define a compatible harness or a simpler compatible pack choice. Do not purchase duplicate electronics by default.
2. Measure the whole player's current with display on, display off, paused and playing over Bluetooth. Check startup and peripheral rail behavior on battery.
3. Verify charging, battery temperature, charge termination and USB insertion/removal during playback under a supervised bench test.
4. Add battery indication, low-battery behavior and a practical power/wake control. Measure actual standby/off drain; do not infer it from the ESP32 chip specification.
5. Run a full album and measured runtime trial before setting the final battery space. Use the intended headphones and car receiver separately; the SoundCore result does not qualify every receiver.

An external USB power bank could supply an early mobile experiment, but it would not qualify an internal pack, charging or standby design.

## Sleep and wake are separate behaviors

| State | Intended behavior | Current implementation |
| --- | --- | --- |
| Screen off while playing | Backlight off; audio continues; first control input wakes the screen | Implemented display timeout, awaiting complete physical acceptance |
| Paused standby | Reduce system/peripheral draw; wake through a defined control | Not implemented or measured |
| Off | Low drain, deliberate power-on, retained preferences | Power-control design and measurement still needed |

ESP32 deep sleep drops the Bluetooth link, so wake needs boot/reconnect and paused restoration. A control read only through a polled I2C device does not by itself provide a wake source while the CPU is asleep. Select a wake-capable connection and verify the full board/peripheral behavior. [Espressif sleep documentation](https://docs.espressif.com/projects/esp-idf/en/v5.3/esp32/api-reference/system/sleep_modes.html).

## Mark-7 purpose

Build a secured, battery-powered player that Dave can take around the block and use with an intended car receiver. Reuse the Feather, display, SD, working software and whichever controls have passed qualification. The [approved visual reference](mark-7-design-reference.md) supplies the appearance and capacitive-wheel direction. The existing mechanical wheel can serve the first portable trial if capacitive sensing is still under development.

The display/module dimensions set a lower bound on case size; no smaller dimensions are promised before layout. Place the actual battery and connectors, retain service access and antenna clearance, then decide whether wiring, a small interconnect board or a revised carrier best serves that layout.

## Evidence and unfinished acceptance

The complete UI implementation, source hashes and short hardware captures are in [the bench record](../hardware/mark-6/feather-complete-ui-bench-20260927/). [Requirements](Harmony-player-ui-requirements.md) retain the distinction between implemented software and physical acceptance. Full-album endurance, second-receiver pairing, power-loss/reconnect coverage, battery and carry tests remain open.

Tracking: Complete Mark-6 player UI (HARMONY-18), under Harmony Mark-6: Bluetooth bench player (HARMONY-17). Do not mark these acceptance items passed solely because the next hardware direction is attractive.

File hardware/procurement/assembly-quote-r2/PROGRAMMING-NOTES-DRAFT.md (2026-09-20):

# Draft programming package notes

Status: programming quote input only. The images have passed build, layout, and checksum checks, but no Harmony/Tangara assembly has been flashed or tested with them.

## ESP32-WROVER-E-N16R8

Program a 16 MiB ESP32 in DIO mode at 80 MHz with the exact local files, offsets, byte counts, and SHA-256 hashes in `programming/programming-manifest.json`. The seven images are at offsets `0x1000`, `0x8000`, `0xd000`, `0x10000`, `0x810000`, `0xb10000`, and `0xf10000`. Verify the flash contents against those hashes after programming. Do not enable flash encryption, secure boot, or eFuse changes unless a later approved package explicitly requires them.

## ATSAMD21E18A-AF

For a blank device, use 3.3 V SWD and `programming/samd-bootloader-tangara-bc1632d.bin`. Program it at address `0x00000000`, set and verify an 8 KiB BOOTPROT region, then install `programming/samd-tangara-samd-v6.0.bin` at address `0x00002000`. Verify both images. The local application UF2 is only for a device that already has a working Tangara UF2 bootloader.

The SWD footprint J5 exposes pads rather than a populated header. The fixture must reach SWDIO, SWCLK, RESET, ground, and a 3.3 V reference without loading or damaging the board. Fixture pinout and power-source behavior require review before use.

## Acceptance record requested from programmer

Record board serial or lot identifier, programmer and software version, approved package manifest hash, image hashes, programmed addresses, read-back result, BOOTPROT result, ESP32 MAC address, SAMD firmware version observed by the ESP32, USB enumeration, and any failure/rework. Stop on any hash mismatch.

The authoritative build evidence and upstream hash records remain in `../../../firmware/esp32-validation/` and `../../../firmware/samd-validation/`. The package carries the required factory/programming images so a quote attachment can be reviewed as a unit. Uploading them to a supplier portal is a later controlled release step and is not authorized by this draft.

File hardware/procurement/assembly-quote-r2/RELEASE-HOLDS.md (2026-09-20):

# Release holds

These outputs can support supplier pricing. They cannot authorize fabrication, purchasing, assembly, substitution, or production programming.

## Blocking holds

- **LCD1 mechanical identity:** the routed faceplate footprint and electrical 14-pin, 0.8 mm-pitch mapping match the ER-TFT018-4 candidate, so the BOM uses that candidate for pricing. Obtain the archived manufacturer drawing and pass a full-scale mechanical overlay against the faceplate and enclosure before release. The candidate status is preserved in the BOM.
- **Battery LP574459:** obtain maximum finished-pack dimensions including protection PCB, seams and cable exit; protection limits; maximum charge current; 10 kΩ NTC curve; lead construction; PHR-3 contact identity; and a mating-view pin drawing proving J7 order 1 NTC, 2 negative, 3 protected positive. The fitted R39 gives an approximately 1 A charge ceiling. Do not release a pack on nominal cell dimensions alone.
- **DRC and fabrication review:** native exports are quote attachments, not proof that the source is design-rule clean. Resolve or formally disposition every KiCad DRC item and review layer set, outline, holes, slots, stack-up, solder mask, paste, and RF antenna clearance before fabrication approval.
- **R2 circuit and manufacturing review:** the hidden EP pin correction is documented in the R2 review. Only the reported electrical net conflicts are cleared. Remaining native DRC/ERC, physical connector/electrode findings, and supplier DFM acceptance remain open. Do not use clean electrical parity as fabrication approval.
- **Rotation and polarity:** validate every supplier placement preview against assembly drawings. No library rotation correction has been guessed or labeled manufacturing-ready.
- **Firmware qualification:** the preserved ESP32, SAMD application, and SAMD bootloader artifacts build and have hashes, but have not run on this assembly. HARMONY-12's ALAC metadata-bounds finding also remains open before qualification.

## Controlled exceptions and clarifications

- Mainboard R1, C17, and C19 remain DNP. R1 must remain open when the battery supplies a real NTC.
- Mainboard J3 and J5 are unpopulated programming interfaces. J5 is a pad footprint needed for initial SAMD SWD programming; it is not a purchasable connector.
- Faceplate SW1, SW2, and SW3 are capacitive copper electrodes, not tactile switches and not purchased components.
- Faceplate J1 and J2 are haptic motor solder pads, not components. Quote one VC1034B018F motor per complete set in the external addendum.
- Faceplate H1-H4, TP1-TP9, logos, and text structures are fabricated PCB features, not assembly line items.
- The touch-wheel cover is an unpopulated insulating mechanical part and is outside both PCBA BOMs. The Harmony enclosure currently uses the printable cover; any 0.6 mm FR4 alternative needs a separate mechanical fabrication review.

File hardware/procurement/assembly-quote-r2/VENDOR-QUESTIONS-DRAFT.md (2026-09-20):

# Unsent vendor questions

These messages are drafts for review. They have not been sent and do not authorize a quote, purchase, fabrication, or customization order.

## EastRising / BuyDisplay: ER-TFT018-4 drawing request

Subject: ER-TFT018-4 controlled drawing and FPC dimensions for prototype fit review

We are evaluating the bare solder-tail ER-TFT018-4 for a small prototype using its 14-contact, 0.8 mm-pitch, 4-wire SPI interface. Before we release the faceplate or enclosure, please send the current controlled mechanical drawing and identify its revision and date.

Please include maximum overall width, height, and thickness; active-area location; glass and polarizer outline; FPC datum and centerline; FPC width, thickness, stiffener geometry and thickness; exposed-contact length; contact numbering viewed from the contact side; bend/keep-out limits; tail-to-glass transition geometry; component or adhesive protrusions; and dimensional tolerances. Please also confirm whether the published electrical drawing remains valid for the currently shipped ER-TFT018-4, with pins 1 and 14 no-connect, pins 10 and 11 logic supply, and ST7735S controller.

Please identify packaging and minimum order quantity for assembler procurement, and state whether production units have any mechanically distinct supplier or revision variants under the same order code. We will not approve a substitute or breakout-board module.

## LiPol Battery Co.: LP574459 finished-pack and harness request

Subject: LP574459 five-sample feasibility and three-wire harness specification

Please confirm whether five LP574459 samples can be supplied to Pennsylvania, USA as a finished protected single-cell pack with a cell-mounted 10 kΩ NTC and a JST-manufactured PHR-3 housing. We need a review drawing and electrical specification before ordering.

Please provide maximum finished thickness, width, and length including protection PCB, seams, tape, wire attachment, strain relief, and cable exit; cell and finished-pack tolerances; lead length and wire gauge; JST contact part number and crimp specification; protection thresholds and continuous/peak discharge limits; maximum continuous and recommended charge current; charge temperature range; NTC resistance at 25 °C, beta or full resistance/temperature table, tolerance, and physical attachment to the cell; UN38.3 report reference and shipping documentation for the exact finished pack; sample price, customization charge, lead time, and shipping method.

The mating board header is JST S3B-PH-K-S(LF)(SN). Please provide a mating-view harness drawing that explicitly assigns PHR-3 circuit 1 to NTC, circuit 2 to cell negative and thermistor return, and circuit 3 to protected cell positive. Wire colors are secondary to circuit numbering. The charger is a 4.2 V MCP73871 design with an approximately 1 A configured ceiling, so please state whether this exact finished pack permits 1 A continuous charging. If it does not, state the maximum permitted current. Do not build the harness until we approve the drawing.

## PCBA supplier: quote clarifications

Subject: Tangara mainboard and faceplate quote review questions

Please quote the attached package at one, two, and five complete electronics sets and answer the following before any order is released:

1. Can you procure every BOM line exactly as listed, and separately flag unavailable, end-of-life, long-lead, minimum-order, or customer-consigned lines?
2. Can you procure and hand-solder the bare ER-TFT018-4 FPC after its controlled drawing is approved, and attach one VC1034B018F motor to faceplate pads J1/J2?
3. Can you program and verify both processors using the draft instructions, including initial 3.3 V SWD programming and 8 KiB BOOTPROT verification for the blank ATSAMD21E18A-AF?
4. What layer stack-up and tolerances do you propose for the four-layer mainboard and two-layer faceplate at nominal 1.6 mm? The source file has no explicit copper-finish setting. Please price ENIG as the requested finish and identify the applicable finish specification and thickness.
5. Which Gerber/drill/placement files did you import, and what file-parser or rotation corrections did your preview apply? Please return annotated top and bottom placement previews before release.
6. Which DFM, AOI, electrical, programming, and functional tests can you perform? Please break out fixture, tooling, panelization, setup, unused-board, and non-recurring charges.
7. Please return your approved working BOM and final placement record, and do not make substitutions or footprint changes without written approval.

The source currently reports unresolved DRC/ERC findings. This request is suitable for pricing and DFM feedback only. Do not fabricate or procure material from it.

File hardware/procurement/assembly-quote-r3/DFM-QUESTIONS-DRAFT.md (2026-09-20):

# R3 fabrication questions, unsent

The attached R3 data is for engineering and quote review. Please do not fabricate, buy components or substitute parts without a later release. Quote complete sets at quantities 1, 2 and 5, including mixed SMT/plated connector assembly and optional programming.

1. **USB-C fit:** J6 is GCT USB4510-03-1-A. The controlled GCT A1 drawing recommends a 0.80 mm PCB; the four-layer mainboard totals 1.60252 mm. Confirm shell-stake engagement, soldering process and fit at this thickness with a section drawing or sample measurement. Twelve signal pads end at the routed connector cutout. Confirm the actual copper-to-route tolerance and whether this footprint can be built reliably. If not, identify the required footprint/connector change before quoting it as buildable.
2. **Audio-jack machining:** J1 is Same Sky SJ-3506-SMT-TR. R3 uses eight plated 1.10 × 0.70 mm slots, a 10.10 mm cutout, and revised copper lands that pass the existing 0.15 mm annular-ring and 0.30 mm edge checks. Confirm finished-slot dimensions/tolerances, plating and pin soldering against the manufacturer drawing.
3. **Touch electrode artwork:** the three wheel electrodes have minimum pair gaps of 0.282097, 0.291368 and 0.292112 mm; the project QTouch rule is 0.5 mm. The Pin 3 electrode also triggers KiCad's sliver warning. Please review the supplied copper contour for etching reliability. Supplier manufacturability acceptance alone will not establish touch sensitivity; that still needs a prototype through the printed cover.
4. **Thermal relief:** native zone refill reports one B.Cu spoke at the U15 ESP32 ground pad 39 location x134.01, y89.00 mm, against two configured minimum spokes. Review the full multilayer ground connection and reflow process; propose a local correction or a specific accepted exception.
5. **CAM/assembly preview:** review small or clipped silkscreen, four side-button edge gaps within 0.00003 mm of 0.30 mm, mixed plated/SMT footprint metadata, RF antenna keepout, rotations and polarity. Return marked previews and a list of proposed CAM edits. Do not silently repair copper.

Battery and display specifications remain in [vendor questions](VENDOR-QUESTIONS-DRAFT.md). No supplier has received this draft, and no acceptance is recorded.

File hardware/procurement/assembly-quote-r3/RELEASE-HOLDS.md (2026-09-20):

# Release holds

These outputs can support supplier pricing. They cannot authorize fabrication, purchasing, assembly, substitution, or production programming.

## Blocking holds

- **LCD1 mechanical identity:** the routed faceplate footprint and electrical 14-pin, 0.8 mm-pitch mapping match the ER-TFT018-4 candidate, so the BOM uses that candidate for pricing. Obtain the archived manufacturer drawing and pass a full-scale mechanical overlay against the faceplate and enclosure before release. The candidate status is preserved in the BOM.
- **Battery LP574459:** obtain maximum finished-pack dimensions including protection PCB, seams and cable exit; protection limits; maximum charge current; 10 kΩ NTC curve; lead construction; PHR-3 contact identity; and a mating-view pin drawing proving J7 order 1 NTC, 2 negative, 3 protected positive. The fitted R39 gives an approximately 1 A charge ceiling. Do not release a pack on nominal cell dimensions alone.
- **DRC and fabrication review:** native exports are quote attachments, not proof that the source is design-rule clean. Resolve or formally disposition every KiCad DRC item and review layer set, outline, holes, slots, stack-up, solder mask, paste, and RF antenna clearance before fabrication approval.
- **R3 fabrication review:** see the measured residuals in [DFM questions](DFM-QUESTIONS-DRAFT.md). USB4510's manufacturer drawing recommends a 0.8 mm PCB; the mainboard stack-up totals 1.60252 mm. Twelve USB pads meet the routed cutout. Neither condition is approved for this assembly. The native refill also exposes an incomplete B.Cu thermal relief at U15 pad 39. Wheel gaps are 0.282–0.292 mm against a 0.5 mm configured rule, and one wheel polygon retains a sliver warning. These need explicit resolution before fabrication; no rule was relaxed to obtain a clean result.
- **Rotation and polarity:** validate every supplier placement preview against assembly drawings. No library rotation correction has been guessed or labeled manufacturing-ready.
- **Firmware qualification:** the preserved ESP32, SAMD application, and SAMD bootloader artifacts build and have hashes, but have not run on this assembly. HARMONY-12's ALAC metadata-bounds finding also remains open before qualification.

## Controlled exceptions and clarifications

- Mainboard R1, C17, and C19 remain DNP. R1 must remain open when the battery supplies a real NTC.
- Mainboard J3 and J5 are unpopulated programming interfaces. J5 is a pad footprint needed for initial SAMD SWD programming; it is not a purchasable connector.
- Faceplate SW1, SW2, and SW3 are capacitive copper electrodes, not tactile switches and not purchased components.
- Faceplate J1 and J2 are haptic motor solder pads, not components. Quote one VC1034B018F motor per complete set in the external addendum.
- Faceplate H1-H4, TP1-TP9, logos, and text structures are fabricated PCB features, not assembly line items.
- The touch-wheel cover is an unpopulated insulating mechanical part and is outside both PCBA BOMs. The Harmony enclosure currently uses the printable cover; any 0.6 mm FR4 alternative needs a separate mechanical fabrication review.

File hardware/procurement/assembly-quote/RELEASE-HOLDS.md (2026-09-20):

# Release holds

These outputs can support supplier pricing. They cannot authorize fabrication, purchasing, assembly, substitution, or production programming.

## Blocking holds

- **LCD1 mechanical identity:** the routed faceplate footprint and electrical 14-pin, 0.8 mm-pitch mapping match the ER-TFT018-4 candidate, so the BOM uses that candidate for pricing. Obtain the archived manufacturer drawing and pass a full-scale mechanical overlay against the faceplate and enclosure before release. The candidate status is preserved in the BOM.
- **Battery LP574459:** obtain maximum finished-pack dimensions including protection PCB, seams and cable exit; protection limits; maximum charge current; 10 kΩ NTC curve; lead construction; PHR-3 contact identity; and a mating-view pin drawing proving J7 order 1 NTC, 2 negative, 3 protected positive. The fitted R39 gives an approximately 1 A charge ceiling. Do not release a pack on nominal cell dimensions alone.
- **DRC and fabrication review:** native exports are quote attachments, not proof that the source is design-rule clean. Resolve or formally disposition every KiCad DRC item and review layer set, outline, holes, slots, stack-up, solder mask, paste, and RF antenna clearance before fabrication approval.
- **Mainboard schematic/PCB parity:** native comparison reports C23 pin 2 on schematic net `-5VA` while the routed PCB assigns it to `GND`. The `-5VA` schematic net also reaches other ground-like pins, but this has not been proven to be a harmless naming difference. Perform a source-circuit review before any net update or fabrication release; do not waive or automatically synchronize it.
- **Rotation and polarity:** validate every supplier placement preview against assembly drawings. No library rotation correction has been guessed or labeled manufacturing-ready.
- **Firmware qualification:** the preserved ESP32, SAMD application, and SAMD bootloader artifacts build and have hashes, but have not run on this assembly. HARMONY-12's ALAC metadata-bounds finding also remains open before qualification.

## Controlled exceptions and clarifications

- Mainboard R1, C17, and C19 remain DNP. R1 must remain open when the battery supplies a real NTC.
- Mainboard J3 and J5 are unpopulated programming interfaces. J5 is a pad footprint needed for initial SAMD SWD programming; it is not a purchasable connector.
- Faceplate SW1, SW2, and SW3 are capacitive copper electrodes, not tactile switches and not purchased components.
- Faceplate J1 and J2 are haptic motor solder pads, not components. Quote one VC1034B018F motor per complete set in the external addendum.
- Faceplate H1-H4, TP1-TP9, logos, and text structures are fabricated PCB features, not assembly line items.
- The touch-wheel cover is an unpopulated insulating mechanical part and is outside both PCBA BOMs. The Harmony enclosure currently uses the printable cover; any 0.6 mm FR4 alternative needs a separate mechanical fabrication review.

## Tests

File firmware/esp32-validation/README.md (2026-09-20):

# ESP32 baseline build verification

The unmodified Tangara ESP32 application and its ESP-IDF bootloader built successfully on September 14, 2026. The resulting application is 2,684,736 bytes and fits the 4 MiB application partition with about 36% free. Esptool validated the image checksum and appended hash. The seven generated flash images do not overlap and fit the configured 16 MiB flash.

This establishes that the pinned source can compile and link on this machine. It does not establish playback, Bluetooth compatibility, charging behavior, USB storage reliability, or battery runtime. No device was connected or flashed.

## Sources and build environment

| Input | Verified value |
| --- | --- |
| Tangara source | `https://codeberg.org/cool-tech-zone/tangara-fw.git` |
| Tangara commit | `c092c5aae83aac241b3756b15d8b9dad9ed2c3fd` |
| Application version | `2.1.0`, declared by upstream CMake |
| ESP-IDF commit | `8c750b088c7cd857d079c0eeb495da199b359461`, reporting 5.5.0 |
| Compiler | Xtensa GCC 14.2.0, `esp-14.2.0_20241119` |
| Python | 3.12.11, isolated IDF environment |
| Build tools | CMake 3.30.5; Ninja 1.12.1 |
| Host | macOS 26.6.2, Apple arm64 |
| Source modifications | None |

[Submodule pins](configuration/submodules.txt), [resolved Python packages](configuration/python-packages.txt), and [generated sdkconfig](configuration/sdkconfig) are preserved. The upstream defaults select classic Bluetooth/A2DP, external RAM, and 16 MiB flash. This is a Tangara/WROVER baseline, not an ESP32-S3 build.

## Rebuild

From the live Harmony2 repository, with Python 3.12, Git, CMake, and Ninja available:

```sh
bash firmware/esp32-validation/bootstrap.sh
bash firmware/esp32-validation/build.sh
```

The bootstrap downloads the pinned source/submodules and installs the ESP32 compiler and Python environment under `firmware/toolchains/esp-idf`. The build script checks source revisions and tracked changes, rejects `sdkconfig.local`, and checks an existing sdkconfig against the saved baseline. The scripts do not flash hardware. The initial clean build and a subsequent invocation through the build script both succeeded. A second clean, byte-identical build has not been demonstrated; build timestamps, absolute debug paths, and dependency resolution can affect future outputs. The Python package snapshot records what was used; bootstrap uses upstream dependency constraints rather than a sealed offline package environment.

Tool setup follows the pinned source's BUILDING.md and [Espressif's ESP-IDF 5.5 setup documentation](https://docs.espressif.com/projects/esp-idf/en/v5.5/esp32/get-started/linux-macos-setup.html).

## Artifacts and limits

[validation.json](validation.json) records the checks. [Flash layout](artifacts/flash-layout.json) lists the offsets, lengths, and SHA-256 values of the bootloader, partition table, initial OTA data, application, collation data, Lua filesystem, and REPL filesystem. These are validation artifacts, not a factory release. The application ELF and linker map are included for later debugging.

The [first build log](logs/build-first.log) contains 29 compiler warnings and one CMake warning. Most concern deprecated APIs, unused code, or fallthrough. Three warnings concern possible null dereferences in the upstream ALAC parser (`src/codecs/alac.cpp:129–131`); inspection finds unchecked cookie indexing after a file-derived length. This is an unresolved parser robustness finding, not a demonstrated hardware failure. Preserve the unmodified baseline and track a focused parser review before qualification. CMake also could not determine the vendored Opus package version. None prevented linking. These warnings must not be described as a warning-free build.

Upstream tests require an actual device according to TESTING.md. They were not executed. The next physical check is the matched SAMD/ESP32 pair on assembled boards; [SAMD build and recovery evidence](../samd-validation/README.md) describes the companion firmware.

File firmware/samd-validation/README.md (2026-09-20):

# Tangara SAMD21 baseline validation

## Result

Both official Tangara SAMD21 images compile successfully on macOS arm64. This is a build validation only. No board was connected, flashed, or exercised, so USB, charging, power control, SD-card multiplexing, and ESP32-to-SAMD I2C behavior remain unverified on hardware.

## Pinned sources

- Application: `https://codeberg.org/cool-tech-zone/tangara-samd-fw.git` at `8066c54bff5d26398fa08955d2bc24e7f05702a2`, tagged `v6.0`.
- Bootloader: `https://git.sr.ht/~jacqueline/tangara-samd-bootloader` at `bc1632d9736493467000ba119fd0b16fd46ccbe6`.
- Compiler: Arm GNU Toolchain `14.3.Rel1`, `arm-none-eabi-gcc 14.3.1 20250623`, unpacked under `firmware/toolchains/samd`.
- Application submodules: TinyUSB `5217cee5de4cd555018da90f9f1bcc87fb1c1d3a`; Microsoft UF2 `35842c770bf553ce01a48ded68f3763e5e140a1e`; HIDAPI `a6a622ffb680c55da0de787ff93b80280498330f`.
- Bootloader submodules: Microsoft UF2 and HIDAPI at the same revisions above.

The application revision is the current Codeberg `main` and `v6.0` tag as checked on 2026-09-14. The bootloader has no release tag; its exact commit is pinned.

## Reproduce

On macOS arm64, run from the Harmony2 repository root:

```sh
firmware/samd-validation/build-samd.sh
```

The script clones both upstream repositories when absent, checks out the exact revisions, initializes recursive submodules, downloads the compiler archive when absent, verifies its SHA-256, and extracts it under `firmware/toolchains/samd`. The compiler archive URL is:

`https://developer.arm.com/-/media/Files/downloads/gnu/14.3.rel1/binrel/arm-gnu-toolchain-14.3.rel1-darwin-arm64-arm-none-eabi.tar.xz`

Its SHA-256 is `30f4d08b219190a37cded6aa796f4549504902c53cfc3c7e044a8490b6eba1f7`.

Before compiling, the script checks both top-level revisions, requires pristine tracked source trees, and verifies every recursive submodule revision. It produces application ELF/BIN/UF2 files, the raw factory bootloader ELF/BIN, a bootloader self-update UF2, logs, compiler size output, and `artifacts/SHA256SUMS`. Bash `pipefail` ensures a compiler failure cannot be hidden by log capture.

## Compatibility with the pinned ESP32 firmware

The ESP32 pin is `c092c5aae83aac241b3756b15d8b9dad9ed2c3fd`. Its SAMD driver reads two bytes beginning at I2C register 0 as major/minor, and for major 6 or newer maps charge status, USB status, power control, and USB control to registers 2 through 5. The application pin declares version `6.0`, exposes exactly six registers at those indexes, and uses the same control bits: power-down bit 0, fast-charge bit 1, USB MSC bit 0, and UF2 reset bit 2. The ESP32 UI also permits USB mass storage for major versions 3 and newer.

The pair is therefore source-compatible at the I2C protocol and flash-layout level. This evidence does not establish electrical or runtime compatibility. That requires a Tangara-compatible board test covering enumeration, mass-storage reads and writes, charge states, shutdown, fast-charge control, and the UF2 reset path.

## Flash and recovery path

The bootloader occupies flash `0x00000000` through `0x00001fff`; the application linker origin and UF2 start address are `0x00002000`. A factory-fresh ATSAMD21E18A needs the Tangara bootloader installed first through the mainboard's SWD pads (`SWDIO`, `SWCLK`, `RESET`, and ground/power reference) with a compatible debugger.

Upstream documents a Black Magic Probe flow using GDB: load the bootloader ELF, run `monitor swdp_scan`, `attach 1`, `load`, and `compare-sections`. The bootloader repository also generates a J-Link command file through its `jlink-flash` target. Its README warns that OpenOCD's `at91samd bootloader` fuse command is buggy and supplies `scripts/fuses.tcl` for setting the SAMD21 BOOTPROT fuse safely. Factory bring-up must include the 8 KiB BOOTPROT setting and verification.

Once the bootloader is installed, copy `tangara-samd-v6.0.uf2` to the mounted `TANGARA UF2` volume. Existing firmware can request the bootloader from Settings > Firmware Update or the ESP32 app console command `samd flash`. A double reset of the SAMD reset pad is the physical recovery entry described by upstream.

The raw bootloader BIN is the factory/SWD artifact. `update-bootloader-tangara-bc1632d.uf2` is for updating a device that already has a working UF2 bootloader and is not a substitute for first programming a blank SAMD21.

Upstream factory and recovery documentation: <https://cooltech.zone/tangara/docs/samd21/>.

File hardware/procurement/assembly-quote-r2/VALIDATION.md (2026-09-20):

# R2 package validation

Codex independently reran native KiCad 8.0.9 checks on both boards after Sol froze the correction. All 567 electrical pin/net assignments agree with the routed PCB, including the repaired -5VA/GND separation. Both PCB hashes are unchanged from the original source.

Mainboard ERC is 10 errors/95 warnings; DRC is 38 errors/45 warnings; parity has 10 non-net warnings. Faceplate ERC is 2/24; DRC is 6/13; parity has 9 non-net warnings. No rule findings were waived. See the [independent review](../../reviews/harmony-r2/REVIEW.md) and its complete finding register.

The BOM and placement files are regenerated from the unchanged boards. Programming images retain the prior build hashes. The generator records all derived source files in its manifest, so the upstream commit alone is not presented as the identity of the corrected schematic.

These checks do not constitute fabrication, assembly, battery/display fit, or firmware qualification approval.

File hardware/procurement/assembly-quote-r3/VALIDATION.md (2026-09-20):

# R3 package validation

Root independently reran KiCad 8.0.9 on both boards and checked all 567 electrical pin/net assignments against both the R2 netlists and R3 schematics. They agree exactly, with no missing pins and no unconnected PCB items. All pad centres and routed tracks remain unchanged. The eight jack pads have specifically reviewed drill/copper changes. Touch electrode geometry is unchanged; native GND zone fills changed on both boards.

Final native counts and every remaining disposition are recorded in the [R3 review](../../reviews/harmony-r3/REVIEW.md). The faceplate has zero DRC errors, but independent geometry analysis still finds wheel gaps below its configured netclass. A clean report alone does not qualify the touch wheel.

The BOM/placement verifier checks 170 footprints against the native baseline inventory: 111 fitted components and 59 DNP/non-purchased structures. Placement positions, rotations and purchase identities are preserved. Manifest hashes identify the current source and outputs. All 11 programming images match the existing build baseline.

These checks establish package consistency and controlled changes. They do not establish supplier acceptance, USB/battery/display fit, touch behavior, audio performance or battery runtime.

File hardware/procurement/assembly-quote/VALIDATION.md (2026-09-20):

# Package validation record

Validation date: 2026-09-14. Tool: official KiCad CLI 8.0.9. Hardware source pin: `9853b4a1dc8a0e3ea3ec75450522e42df12eaa52`.

## Coverage and quantity checks

The routed sources contain 170 footprints: 124 on the mainboard and 46 on the faceplate. This package classifies them without loss:

| Board | Routed footprints | Purchased/fitted placements | DNP or non-purchased structures | BOM groups | Native raw position rows | Supplier position rows |
| --- | ---: | ---: | ---: | ---: | ---: | ---: |
| Mainboard | 124 | 92 | 32 | 35 | 97 | 92 |
| Faceplate | 46 | 19 | 27 | 10 | 22 | 19 |
| Total | 170 | 111 | 59 | 45 | 119 | 111 |

For each board, the sum of `qty_per_board` equals the supplier position count and the purchase-classified reference set matches exactly. Every 1, 2, and 5 quantity column equals the per-board quantity multiplied by its stated board quantity. Reference identifiers are unique within each board. LCD1 occurs once on the faceplate as the held ER-TFT018-4 candidate. The haptic motor occurs once per complete set in the external addendum, while J1/J2 remain classified as faceplate solder pads.

The raw KiCad position export includes DNP or non-purchased footprints that are not excluded from position files in the upstream PCB metadata. The supplier file filters those rows using the explicit purchasing classification; it does not change KiCad's X, Y, side, or rotation fields.

## Native fabrication outputs

KiCad exported the standard fabrication layer set and Excellon drill file without modifying or refilling the stored PCB zones. The mainboard export has four copper layers; the faceplate export has two. Both include top/bottom mask, paste, silkscreen, Edge.Cuts, drill, and Gerber job files. The generator intentionally omits user, courtyard, fabrication-drawing, margin, and adhesive layers from the supplier fabrication folder.

The source specifies mainboard thickness 1.60252 mm and faceplate thickness 1.6 mm. It does not specify a copper finish. ENIG is a quote preference from the upstream production notes, not a property proven by these PCB files. The supplier must state the proposed ENIG specification and stack-up before release.

## DRC and ERC results

All checks used severity `all`; DRC also enabled schematic parity and returned exit code 5 because violations exist. No violation has been waived.

| Check | Errors | Warnings | Additional parity warnings | Unconnected items |
| --- | ---: | ---: | ---: | ---: |
| Mainboard DRC | 38 | 45 | 40 | 0 |
| Faceplate DRC | 6 | 13 | 9 | 0 |
| Mainboard ERC | 28 | 96 | n/a | n/a |
| Faceplate ERC | 2 | 24 | n/a | n/a |

Mainboard DRC errors comprise 24 copper-to-edge clearance, 8 annular-width, and 6 footprint-type findings. Faceplate DRC errors comprise 5 clearance and 1 footprint-type finding. DRC warnings also include library-footprint differences, silkscreen rules, text height, one faceplate copper sliver, and one faceplate dangling via. These may reflect upstream design intent or library drift, but each requires disposition against the board house's rules and the original designer's evidence.

ERC ran with an isolated KiCad configuration and the official KiCad 8 symbol/footprint directories, without reading or changing the user's global KiCad configuration. The remaining results include mainboard 89 and faceplate 22 library-symbol issues, plus pin-to-pin, power-not-driven, multiple-net-name, and dangling-wire findings. Library issues are not treated as electrical proof, and the other findings are not silently dismissed. The JSON reports preserve every item for review.

Independent native netlist comparison confirmed at least one material mainboard parity mismatch: C23 pin 2 is on schematic net `-5VA` and routed PCB net `GND`. Although the schematic `-5VA` net also includes several ground-like pins, this package does not infer that the mismatch is cosmetic. It remains a source-circuit-review hold.

The native reports contain their own generation date and tool metadata, so byte hashes of those reports and Gerbers need not remain stable across regeneration. The generated BOM, classification, review placement, supplier-filtered placement, external addendum, and pin JSON are deterministic for fixed inputs and KiCad native position output.

## Source immutability

The generator reads the two pinned PCB files and writes only under `hardware/procurement/assembly-quote/`. DRC/ERC were read-only invocations. Source hashes are recorded in `manifest.json`; the originals remained unchanged during generation and validation.

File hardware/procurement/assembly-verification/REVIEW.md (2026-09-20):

# Independent assembly package review

Reviewed September 14, 2026 by Codex, independently of the Sol package author. Tracking: HARMONY-13; circuit follow-up: HARMONY-14.

**The package reconciles and is suitable for quote review. Fabrication remains on hold.** No supplier has received these files and no quote, purchase, or hardware qualification has been completed.

## Verified

The reviewer loaded both unchanged boards with KiCad 8.0.9's native `pcbnew` API. This extraction does not use Sol's text parser or validator. `verify_quote_package.py` compares that inventory to the delivered CSVs and hash manifest.

| Board | Native footprints | Purchased/fitted | DNP or PCB structures | BOM groups | Copper layers |
|---|---:|---:|---:|---:|---:|
| Mainboard | 124 | 92 | 32 | 35 | 4 |
| Faceplate | 46 | 19 | 27 | 10 | 2 |

Every fitted reference appears exactly once. MPN, value, footprint, side, native position and rotation agree, with the explicitly held LCD candidate as the sole MPN exception. Quantities for one, two and five boards multiply correctly. All 59 exclusions reconcile, including duplicate logo references. The haptic motor is listed once externally; its solder pads are excluded from component purchasing. Supplier position files are exact filtered native exports. No assembler rotation correction was invented.

All 79 manifest outputs match their SHA-256 and size. All 11 programming files match the preserved firmware builds. The seven ESP32 images do not overlap and fit in 16 MiB. Native copper export counts match the boards. PCB hashes match both the manifest and the original R1 vault snapshot. The source boards were not modified or resaved.

During review, incorrect programming-document paths were fixed and the actual programming images were added to the package. The mainboard finish is unset in the source: ENIG is a quote preference, not a recovered source requirement. Native board thickness is 1.60252 mm mainboard and 1.6 mm faceplate; nominal 1.6 mm is proposed for quoting.

## Findings that prevent fabrication release

| Native KiCad check | Mainboard | Faceplate |
|---|---|---|
| DRC | 38 errors, 45 warnings | 6 errors, 13 warnings |
| Schematic parity | 40 warnings | 9 warnings |
| ERC | 28 errors, 96 warnings | 2 errors, 24 warnings |
| Unconnected items | 0 | 0 |

These results use isolated KiCad library configuration. Missing global-library configuration was corrected before the final run. Remaining library-symbol warnings are not automatically waived. Zero unconnected items does not clear other checks. Examples include mainboard copper-to-edge clearance, slightly undersized connector annular rings, footprint-type metadata, and faceplate touch-electrode clearances. Each needs an engineering or fabrication disposition.

**Confirmed circuit discrepancy:** native schematic netlist assigns C23 pin 2 to `-5VA`; native PCB assigns it to `GND`. Evidence is in `mainboard-native-netlist.xml`, `native-inventory.json`, and `circuit-check-evidence.json`. ERC also reports hidden EP pins on U1 and U9 attached to differently named rails. A plausible explanation is implicit connectivity through hidden power-input pins. KiCad documents this behavior in [Hidden Power Pins](https://docs.kicad.org/8.0/en/eeschema/eeschema.html#hidden_power_pins). This is a hypothesis to investigate, not proof of a physical PCB short or permission to synchronize the PCB. HARMONY-14 is the next engineering task.

**Mechanical and supplier inputs:** the LP574459 listing gives nominal cell dimensions, not guaranteed finished-pack maxima. The pack's NTC curve, three-wire mating-view drawing, protection limits and permission for the approximately 1 A configured charge ceiling remain unconfirmed. The ER-TFT018-4 electrical candidate still needs a controlled FPC drawing and full-scale enclosure/faceplate overlay. The attempted direct PDF retrieval returned HTTP 403; no error page was retained as a datasheet. Draft requests are in `../assembly-quote/VENDOR-QUESTIONS-DRAFT.md`.

## Limits and next steps

This review checks package consistency and independently confirms the reported circuit discrepancy. It is not a complete electrical design review, CAM/DFM sign-off, supplier placement-preview approval, component availability confirmation, or physical test. Firmware builds are hardware-unqualified; the ALAC parser finding remains HARMONY-12.

Start HARMONY-14 by tracing U1/U9 hidden EP connectivity in a separate working copy, proving the intended power nets, and rerunning native netlist/ERC/parity checks. Keep the pinned source and this delivery snapshot unchanged. Obtain the battery and display drawings in parallel once supplier outreach is authorized. Print the full fit case after those dimensions are reconciled; it can precede board arrival, but final fit requires physical parts. Dave's slightly loose R1 coupons remain accepted and no clearance change is justified yet.

Reproduce reconciliation with `python3 hardware/procurement/assembly-verification/verify_quote_package.py` from the live repository or the archive root. Native inventory regeneration requires KiCad 8.0.9's bundled Python and the preserved hardware sources. The quote generator and native tool pins are in the sibling package.

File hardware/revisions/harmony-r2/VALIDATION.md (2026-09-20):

# Harmony R2 schematic correction

Status: engineering revision for HARMONY-14. It is not released for fabrication or purchasing.

## Source and cause

This revision derives from the pinned Tangara hardware commit `9853b4a1dc8a0e3ea3ec75450522e42df12eaa52`. The source lock records that derivation. The mainboard and faceplate PCB files are byte-identical to the pinned reference.

U1, an INA1620, and U9, a PCA8575BS, both used hidden power-input pins named `EP`. KiCad connects hidden power pins by name. U1's exposed pad was explicitly colocated with its `V-` connection to `-5VA`, while U9's exposed pad was explicitly placed on `GND`. Their common hidden name merged those two rails in the generated schematic netlist. The merge assigned 30 routed `GND` pads, including C23 pin 2, to schematic net `-5VA`.

The INA1620 datasheet requires its thermal pad to connect to the most negative supply, VEE. The PCA8575BS datasheet identifies the exposed center pad as die ground connected to VSS. This establishes the intended U1 EP to `-5VA` and U9 EP to `GND` topology.

## Patch

- Removed the hidden attribute from U1 pin 25 in `audio.kicad_sch` and from the project-local INA1620 definition in `symbols.kicad_sym`. The already drawn connection colocates pin 25 with pin 5, `V-`, on `-5VA`.
- Removed the hidden attribute from U9 pin 25 in `peripherals.kicad_sch` and from the project-local PCA8575BS definition in `symbols.kicad_sym`. The already placed GND symbol explicitly connects pin 25 to `GND`.
- Corrected the WM8523 electrical pin types in both the cached schematic symbol and `symbols.kicad_sym` from the manufacturer's pin table. Supply and ground pins are power inputs; DACDAT, MCLK, SCLK, chip-select/mute, and CIFMODE are inputs; BCLK, LRCLK, SDA, and SDOUT/DEEMPH are bidirectional. CPCA, CPCB, ZFLAG, the analog outputs, VMID, and CPVOUTN remain outputs. No pin number, name, connection, PCB net, or geometry changed.

## Native KiCad 8.0.9 results

Checks used `/Users/dave/projects/Harmony2/firmware/toolchains/kicad-8.0.9/KiCad.app/Contents/MacOS/kicad-cli` with the copied isolated configuration under `verification/isolated-config` and severity `all`. No violations were excluded or waived.

| Check | Pinned reference | Harmony R2 |
| --- | ---: | ---: |
| ERC errors | 28 | 10 |
| ERC warnings | 96 | 95 |
| DRC errors | 38 | 38 |
| DRC warnings | 45 | 45 |
| Schematic parity warnings | 40 | 10 |
| Unconnected PCB items | 0 | 0 |

The native R2 netlist proves C23 pin 2 and U9 pin 25 are on `GND`; U1 pins 5 and 25 are on `-5VA`. All 30 net-conflict parity findings are gone. The physical DRC count is unchanged, which is expected because the PCB was not modified.

## Unresolved findings

The ten remaining parity warnings are four duplicate and five extra anonymous `REF**` PCB structures, plus the J2 value difference `FP Connector` versus `MB Connector`. They do not report a remaining net mismatch. The anonymous structures need identity and intended board-only status established before annotation or deletion. J2 has matching pins and nets; its perspective-dependent value text needs an explicit naming decision before synchronization.

The remaining ERC findings are 89 library-symbol warnings, six power-not-driven errors, three pin-type findings, four multiple-net-name warnings, and three dangling bus-entry errors. Several are likely symbol metadata issues. In particular, the TPS65133 symbol types VNEG as an ordinary output, GND as an output, and AVIN/PVIN as bidirectional, which accounts for the U1 `V-` power-not-driven error, the GND-to-FLT error, and two warnings. Those types were not changed in this bounded correction. The other power-not-driven items are J3 GND, J6 VBUS, U10 IN, U1 EN, and U1 V+. The multiple-name findings are VBUS/VBUS_RAW, GND/SHELL_GND, KEY_LOCK/SYS_PWR_EN_SW, and GND/VSS. No remaining item is waived by this revision.

The generated evidence is `verification/mainboard-native-netlist.xml`, `verification/mainboard-erc.json`, and `verification/mainboard-drc.json`.

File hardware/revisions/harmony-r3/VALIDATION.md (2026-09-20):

# Harmony R3 derived source

Derived from Harmony R2 and upstream Tangara hardware commit `9853b4a1dc8a0e3ea3ec75450522e42df12eaa52`. This is an engineering revision, not a fabrication release.

Read the authoritative [R3 independent review](../../reviews/harmony-r3/REVIEW.md), source patch and native reports for exact changes and open holds. All 567 electrical connections reconcile, while J1 copper/drill/cutout geometry and board zone fills deliberately differ from R2. Use [assembly-quote-r3](../../procurement/assembly-quote-r3/README.md) for current quote review. Earlier revisions remain preserved.

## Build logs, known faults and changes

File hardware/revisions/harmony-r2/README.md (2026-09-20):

# Harmony R2 derived electronics

This is a local schematic correction derived from Tangara hardware commit `9853b4a1dc8a0e3ea3ec75450522e42df12eaa52`. Read [VALIDATION.md](VALIDATION.md) for the exact correction and [Codex independent review](../../reviews/harmony-r2/REVIEW.md) for verification and unresolved findings. Both routed PCBs are unchanged. Retain the upstream [CERN-OHL-S-2.0 license](LICENSE).

The derived source identity is recorded in [source-lock.json](source-lock.json) and the [R2 assembly manifest](../../procurement/assembly-quote-r2/manifest.json). These sources and exports are not released for fabrication. Earlier reference and vault snapshots remain unchanged.

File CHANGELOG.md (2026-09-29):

# Changelog

Human-readable changes are recorded here alongside Git commits and linked WCP work items. This log starts September 27, 2026; earlier history remains in Git and the dated hardware evidence directories. No numbered firmware release has been declared.

## 2026-09-28

- Adopted [Mark-7 portable scope](docs/mark-7-portable-scope.md), tracked by Build Mark-7 portable Bluetooth player (HARMONY-19). Reuse the Feather, LCD/SD, ANO controls and one battery; use secured perfboard wiring. Internal SD access is sufficient. Speaker and DAC are excluded.
- Recorded inventory, adapter/heat-shrink purchase, charger compatibility questions, power control and measured-runtime requirements. No battery connection, charging or Mark-7 print occurred.
- Added asynchronous Bluetooth remote-name lookup for existing bonds. Fourteen policy scenarios pass. The final source checkpoint builds for bench and carrier; all four host verifier suites pass without native compiler warnings.
- Preserved [uploaded-versus-built evidence](hardware/mark-6/feather-complete-ui-bench-20260927/README.md), rollback details and a separately hashed unflashed checkpoint binary. The latest name change is not yet on the device. Open device-detail subtitle refresh and physical acceptance remain.

## 2026-09-27

### Complete UI implementation (HARMONY-18)

- Added real native volume control with mute and a short gain ramp, shuffle, repeat, display timeout and device-stored preferences. Startup and reconnect remain paused; initial volume is capped at the prior quiet level.
- Replaced Bluetooth placeholders with saved devices, discovery, explicit pairing, switching, cancel/errors, disconnect and confirmed Forget. Reconnect targets only the last selected receiver.
- Added Songs and M3U playlists, read-only metadata indexing with explicit 512-track capacity, disc/track ordering and known duration extraction.
- Added missing/empty storage and track-error recovery, long-label scrolling, and cached list indices to avoid repeated sorting during drawing.
- Added sanitized host coverage for audio modes/gain, Bluetooth event policy, library bounds/malformed tags, menu actions and wake-only input. Both native targets build without compiler warnings. Physical validation is tracked separately in the [complete UI bench record](hardware/mark-6/feather-complete-ui-bench-20260927/).
- Preserved the previously accepted firmware for rollback. Custom Bluetooth PIN entry, full-album endurance and second-receiver compatibility remain open.

### Added

- Interactive desktop UI with the 45-track trial library, music tree, Now Playing, wheel interaction and simulated Bluetooth management (`1a3990b`, HARMONY-17).
- Native Feather music tree, album-scoped playback queues, restored browsing position, physical playback controls and cream-and-green Now Playing (`b433aff`, HARMONY-17).
- Native renderer with proportional fonts, cached frames, incremental highlight redraw and bounded LCD transfers. Host checks cover navigation, queue behavior, rendering equivalence and transfer cleanup (`b433aff`).
- Full Mark-6 UI scope and remaining acceptance tracked as Complete Mark-6 player UI (HARMONY-18).
- Mark-7 visual reference preserved at tag `mark7-visual-reference-20260927` (`1a3990b`), including Dave's capacitive wheel and battery design direction.

### Fixed and verified

- Corrected mirrored LCD orientation; Dave confirmed normal text and color order (`c3c6179`).
- Verified rotary/button input and SD playlist playback on the shared LCD bus (`183a690` through `c3c471b`).
- Fixed Bluetooth playback contention silence; Dave confirmed clean audio and correct display (`3215421`, `13d4de0`).
- Fixed missed center selection by raising input scheduling priority and avoiding unnecessary screen redraws. Corrected bench capture recorded 12 accepted center presses and zero audio underrun/contention bytes; Dave reports “much better!” (`b433aff`).
- Native UI validation: existing carrier checks, UI/render/audio queue tests with ASan/UBSan, board/display checks, two native builds without compiler warnings, and verified application flash checksum. See [bench evidence](hardware/mark-6/feather-ui-bench-20260927/).

### Earlier first-UI limits (superseded by complete implementation above)

- Adjustable volume, real Bluetooth device management, Songs/Playlists and metadata indexing, settings, persistence, recovery and full-album/reconnect acceptance. See [requirements and status](docs/Harmony-player-ui-requirements.md).
- The native player still uses fixed -24 dB attenuation and the SoundCore 2 receiver. Bluetooth/Settings screens are placeholders. Browser behavior is simulated.
- Carrier power, assembly, battery and final enclosure/RF qualification are separate from this USB bench result.

## 2026-09-26 to 2026-09-27: retained preparation

- Prepared Mark-6 enclosure fit revision and carrier quote package (`91a0eab`, `86f4c52`).
- Recorded PCBWay carrier review submission (`2f87043`); submission is not a manufacturing purchase or release.
- Preserved Feather flash/memory diagnostics and successful bring-up evidence (`90f4b23` through `fe4ea27`).

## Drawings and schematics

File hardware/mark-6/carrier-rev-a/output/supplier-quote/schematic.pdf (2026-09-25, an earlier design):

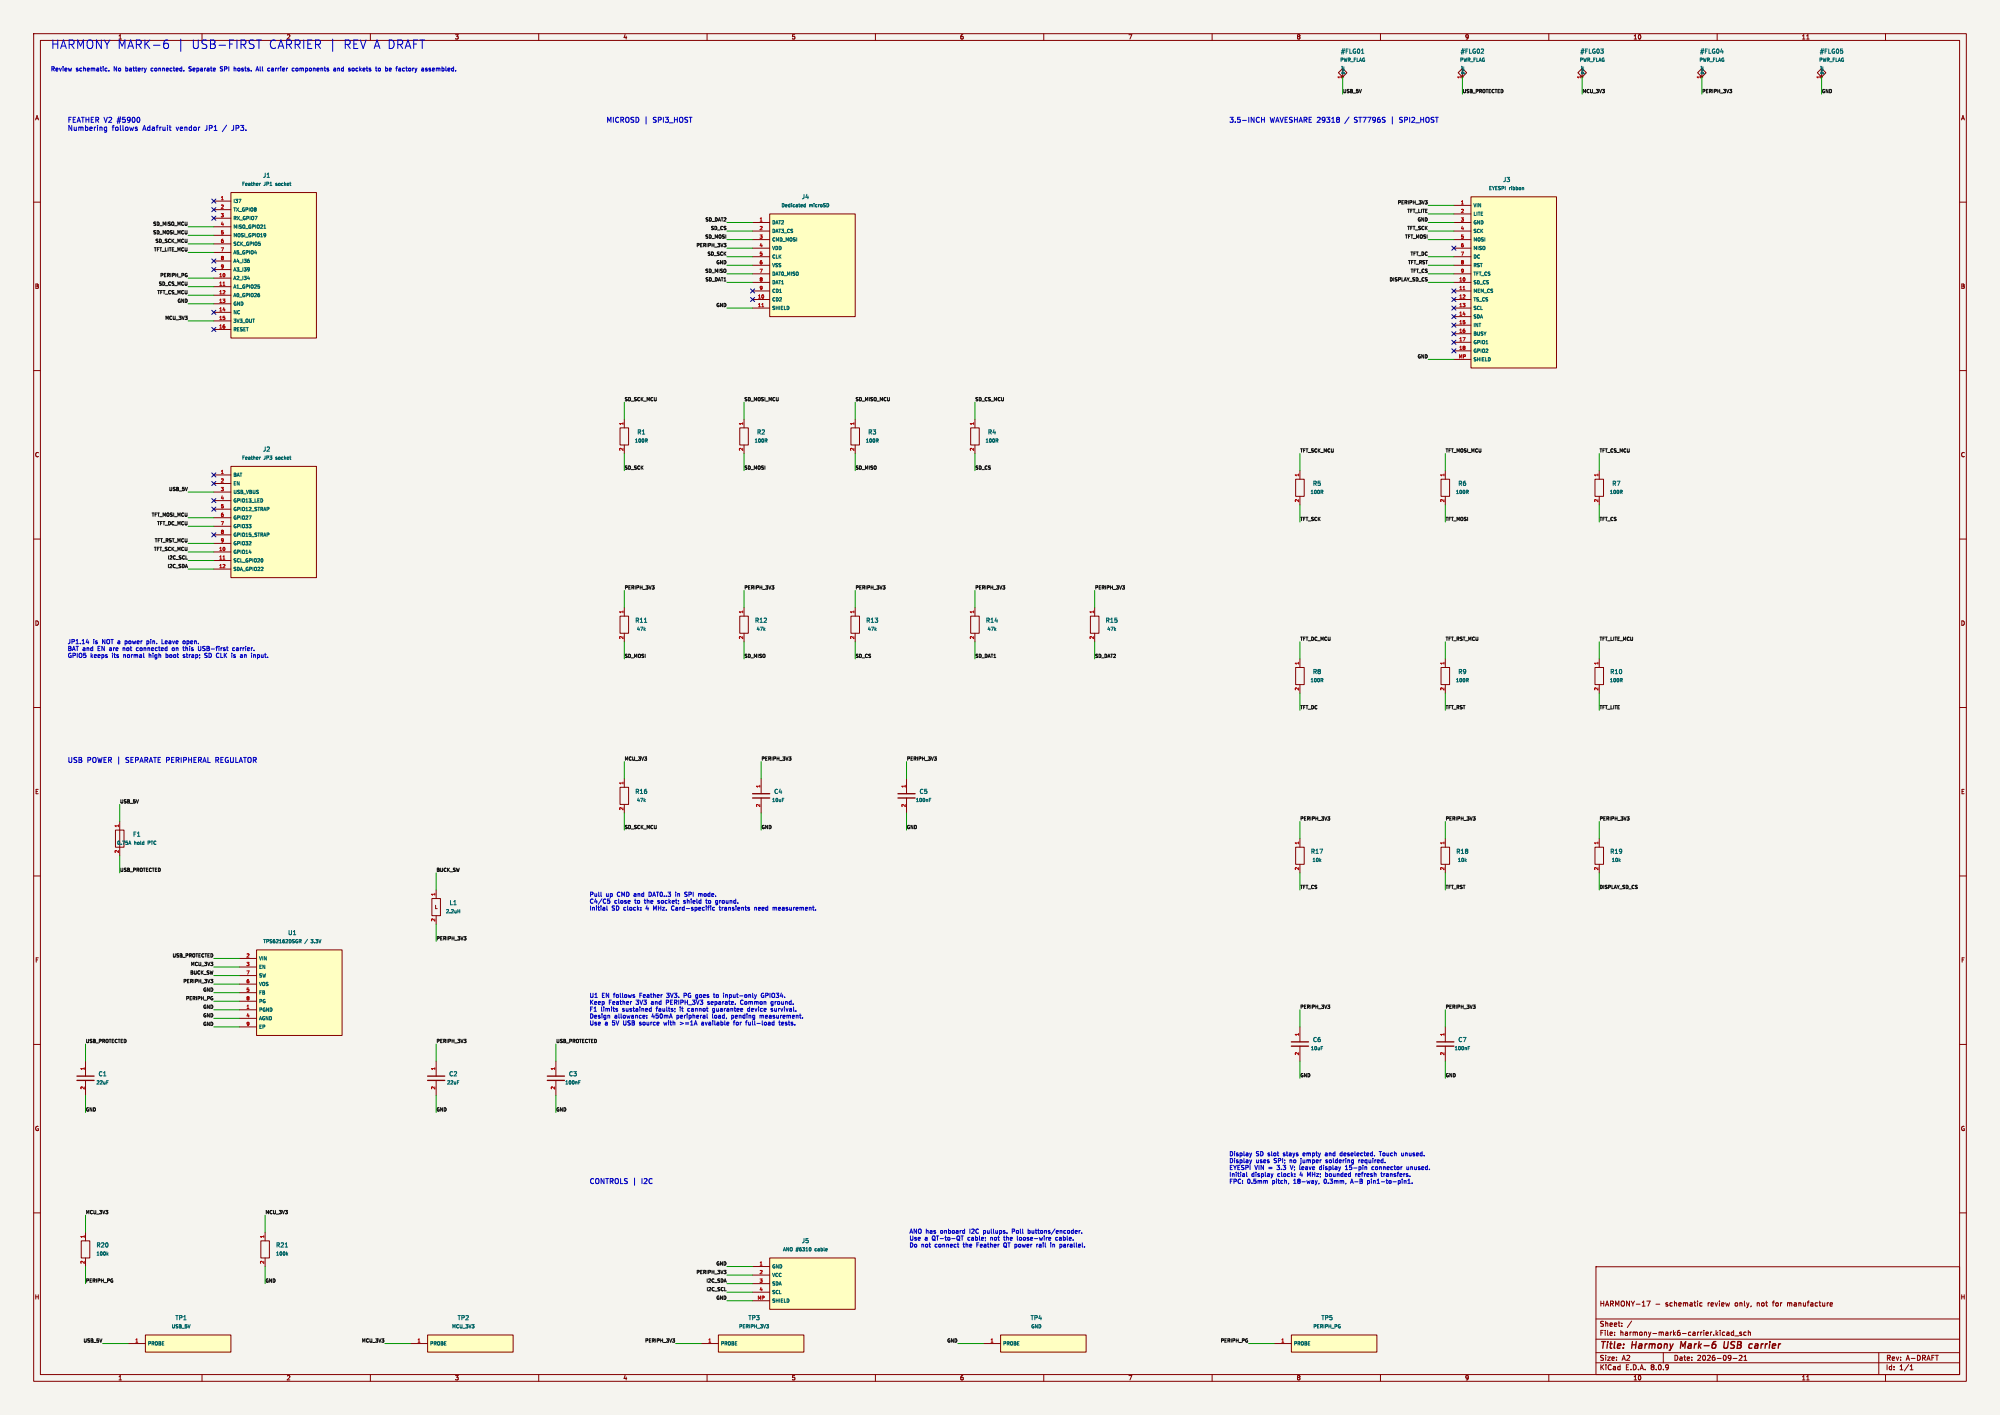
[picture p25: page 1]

Pull up CMD and DAT0..3 in SPI mode. C4/C5 close to the socket; shield to ground.

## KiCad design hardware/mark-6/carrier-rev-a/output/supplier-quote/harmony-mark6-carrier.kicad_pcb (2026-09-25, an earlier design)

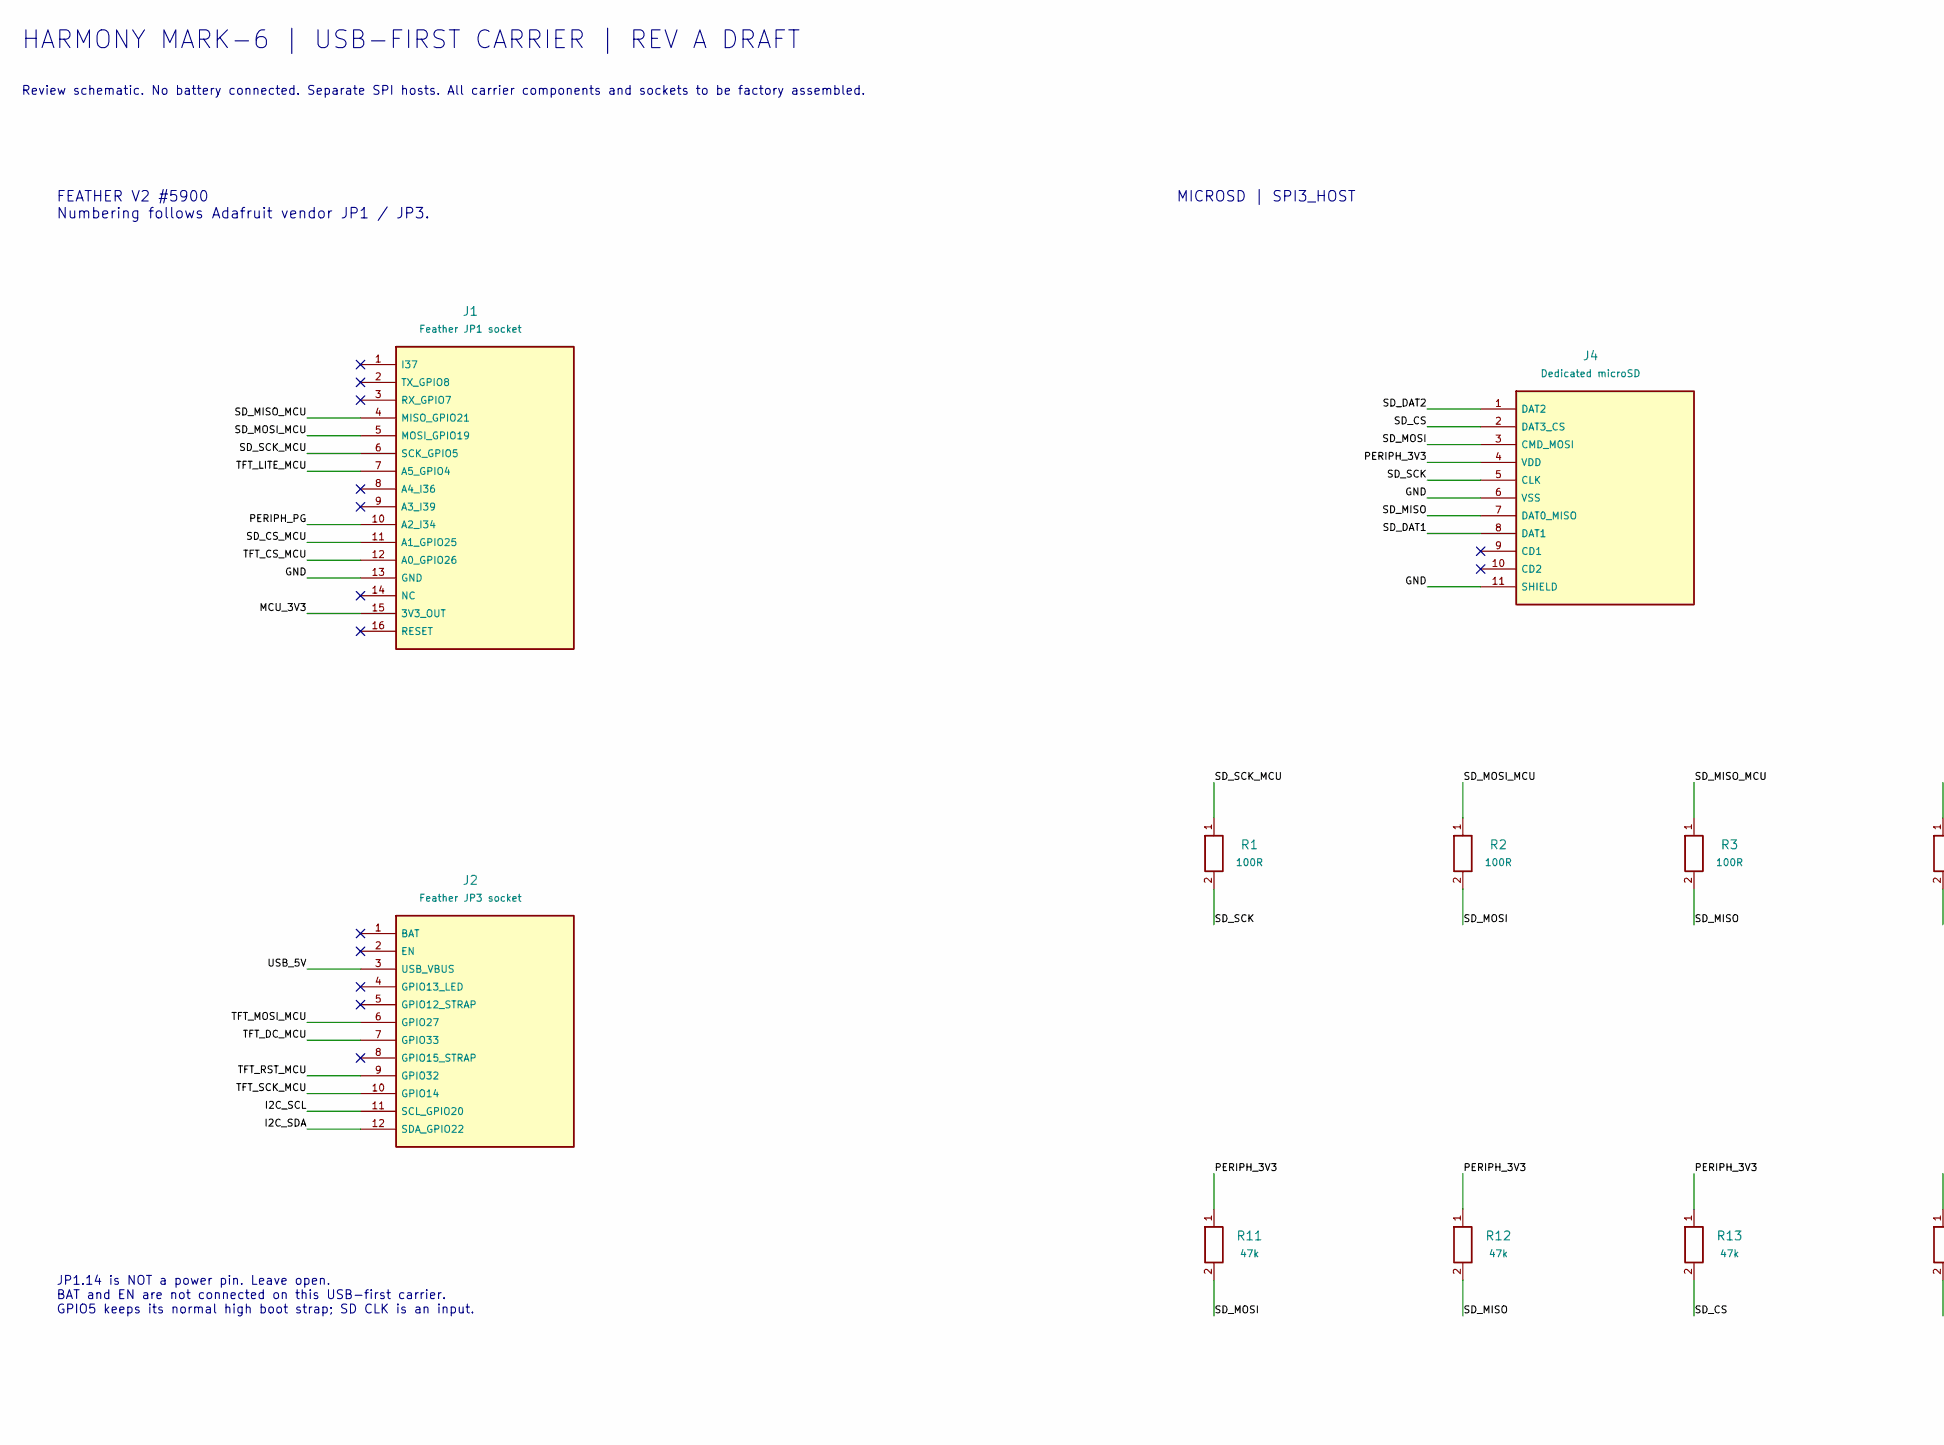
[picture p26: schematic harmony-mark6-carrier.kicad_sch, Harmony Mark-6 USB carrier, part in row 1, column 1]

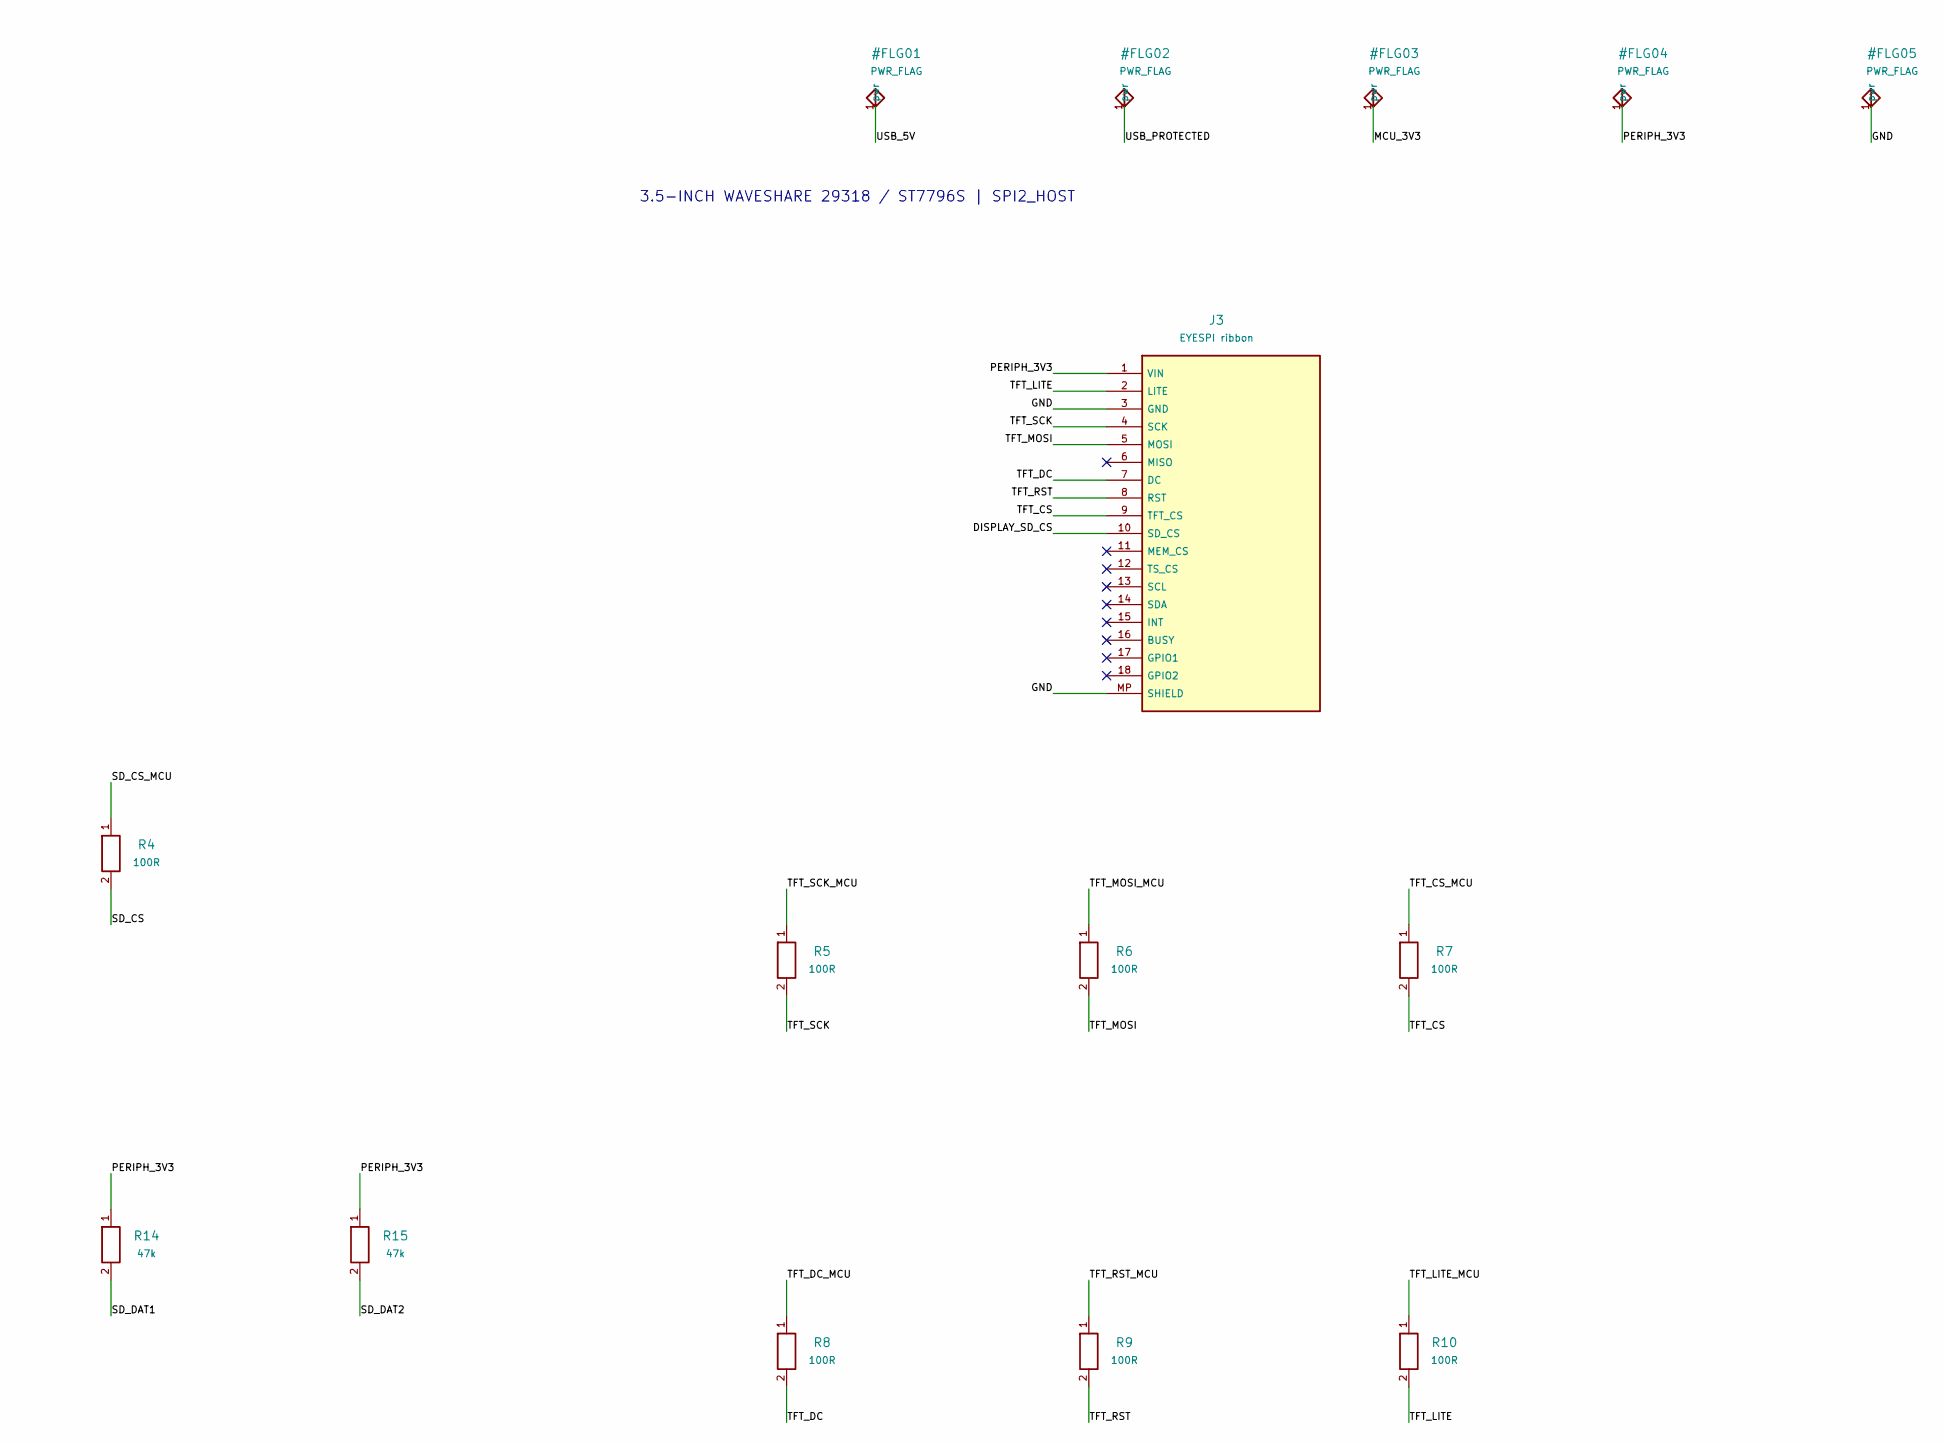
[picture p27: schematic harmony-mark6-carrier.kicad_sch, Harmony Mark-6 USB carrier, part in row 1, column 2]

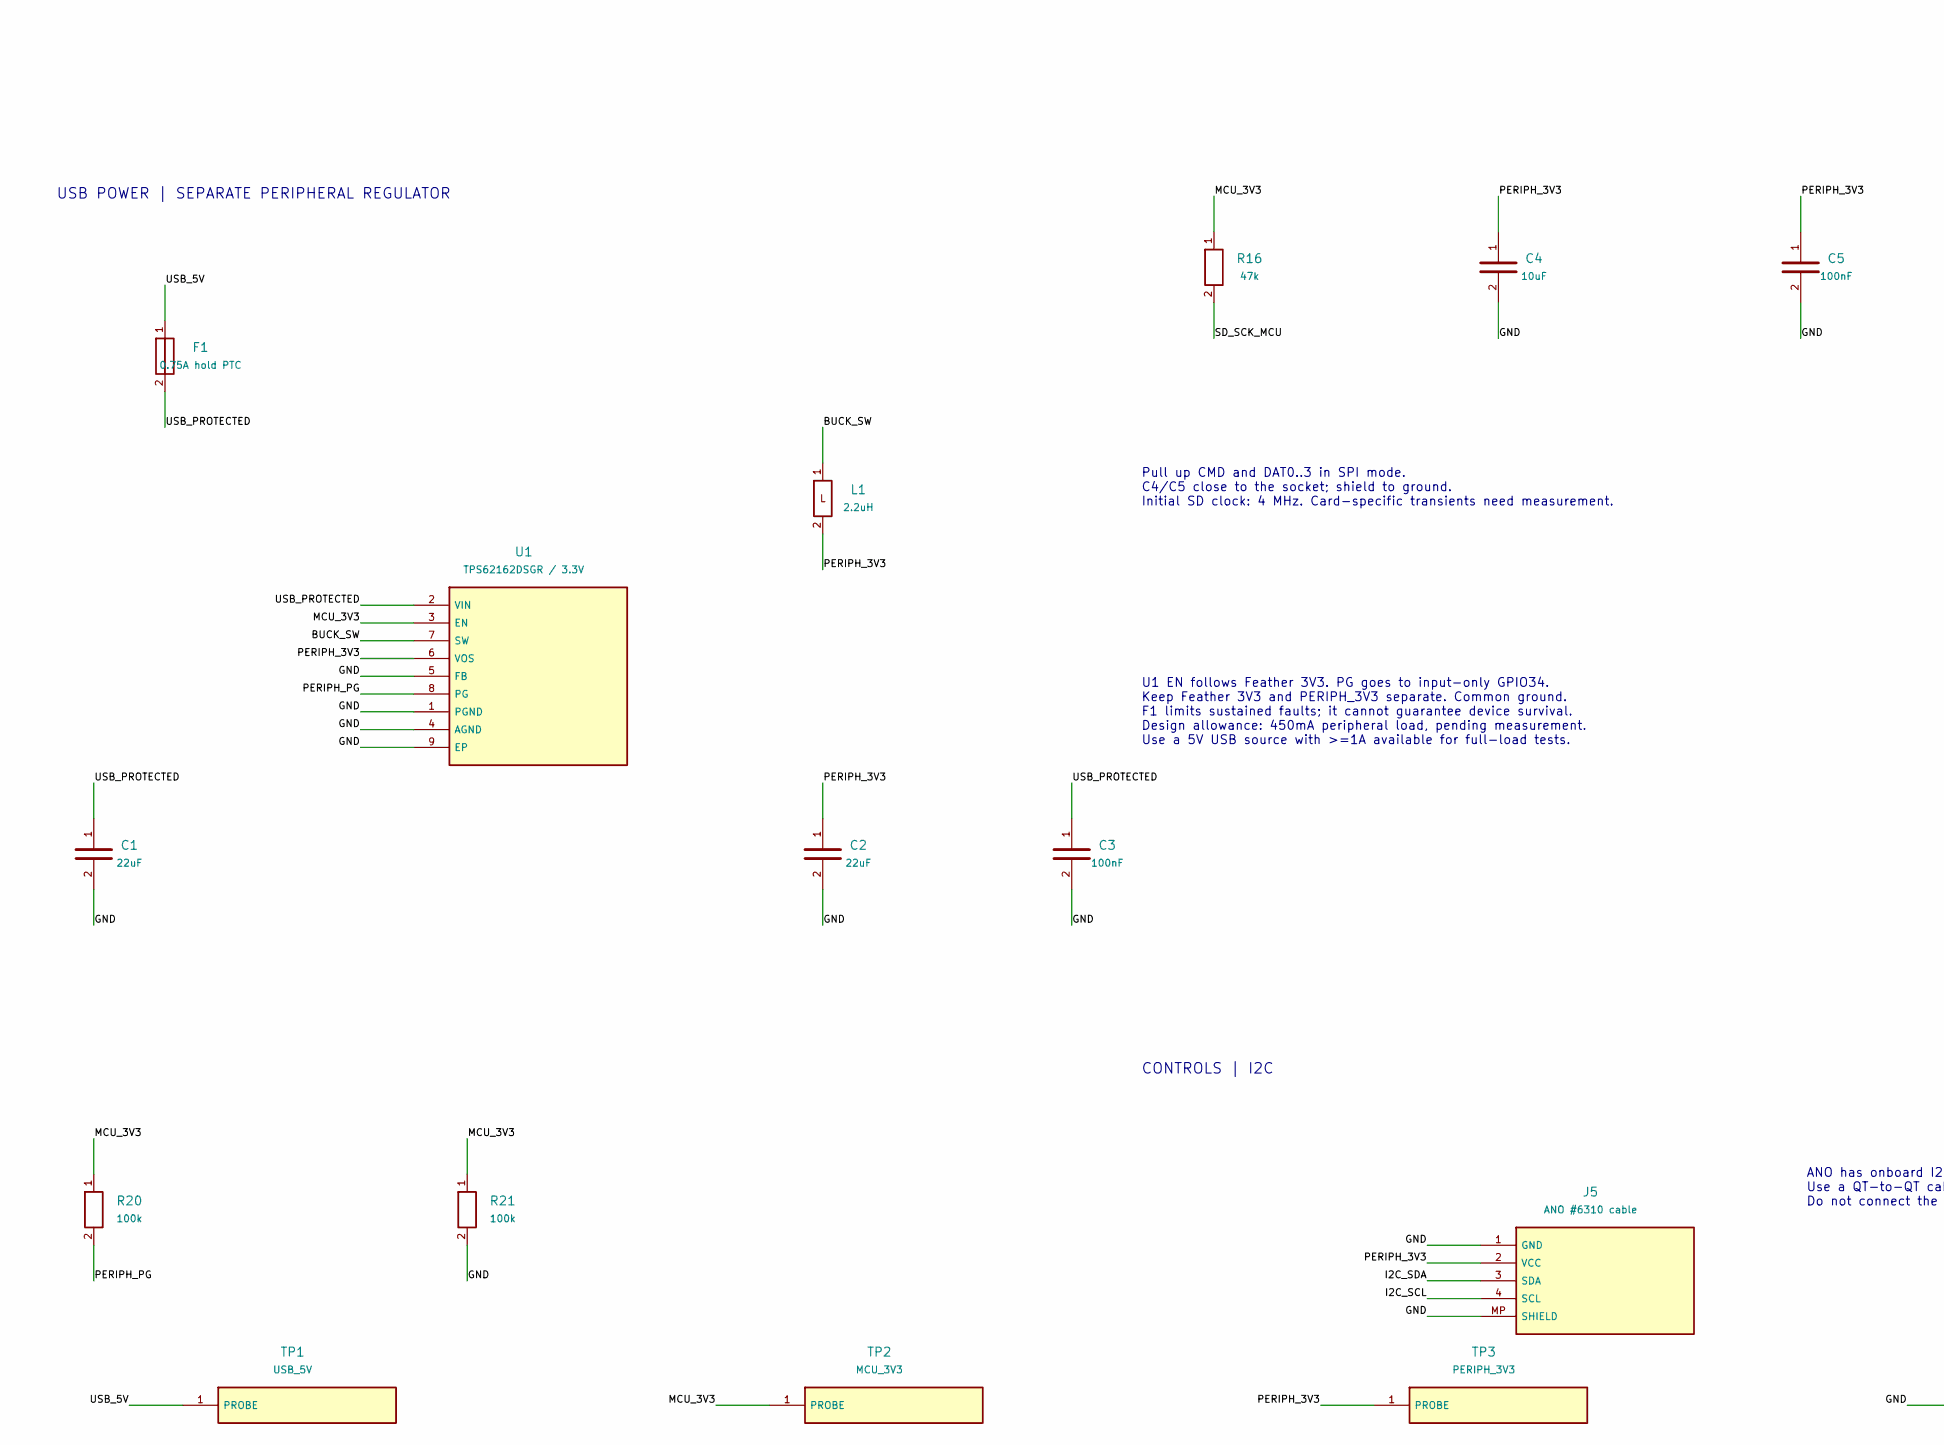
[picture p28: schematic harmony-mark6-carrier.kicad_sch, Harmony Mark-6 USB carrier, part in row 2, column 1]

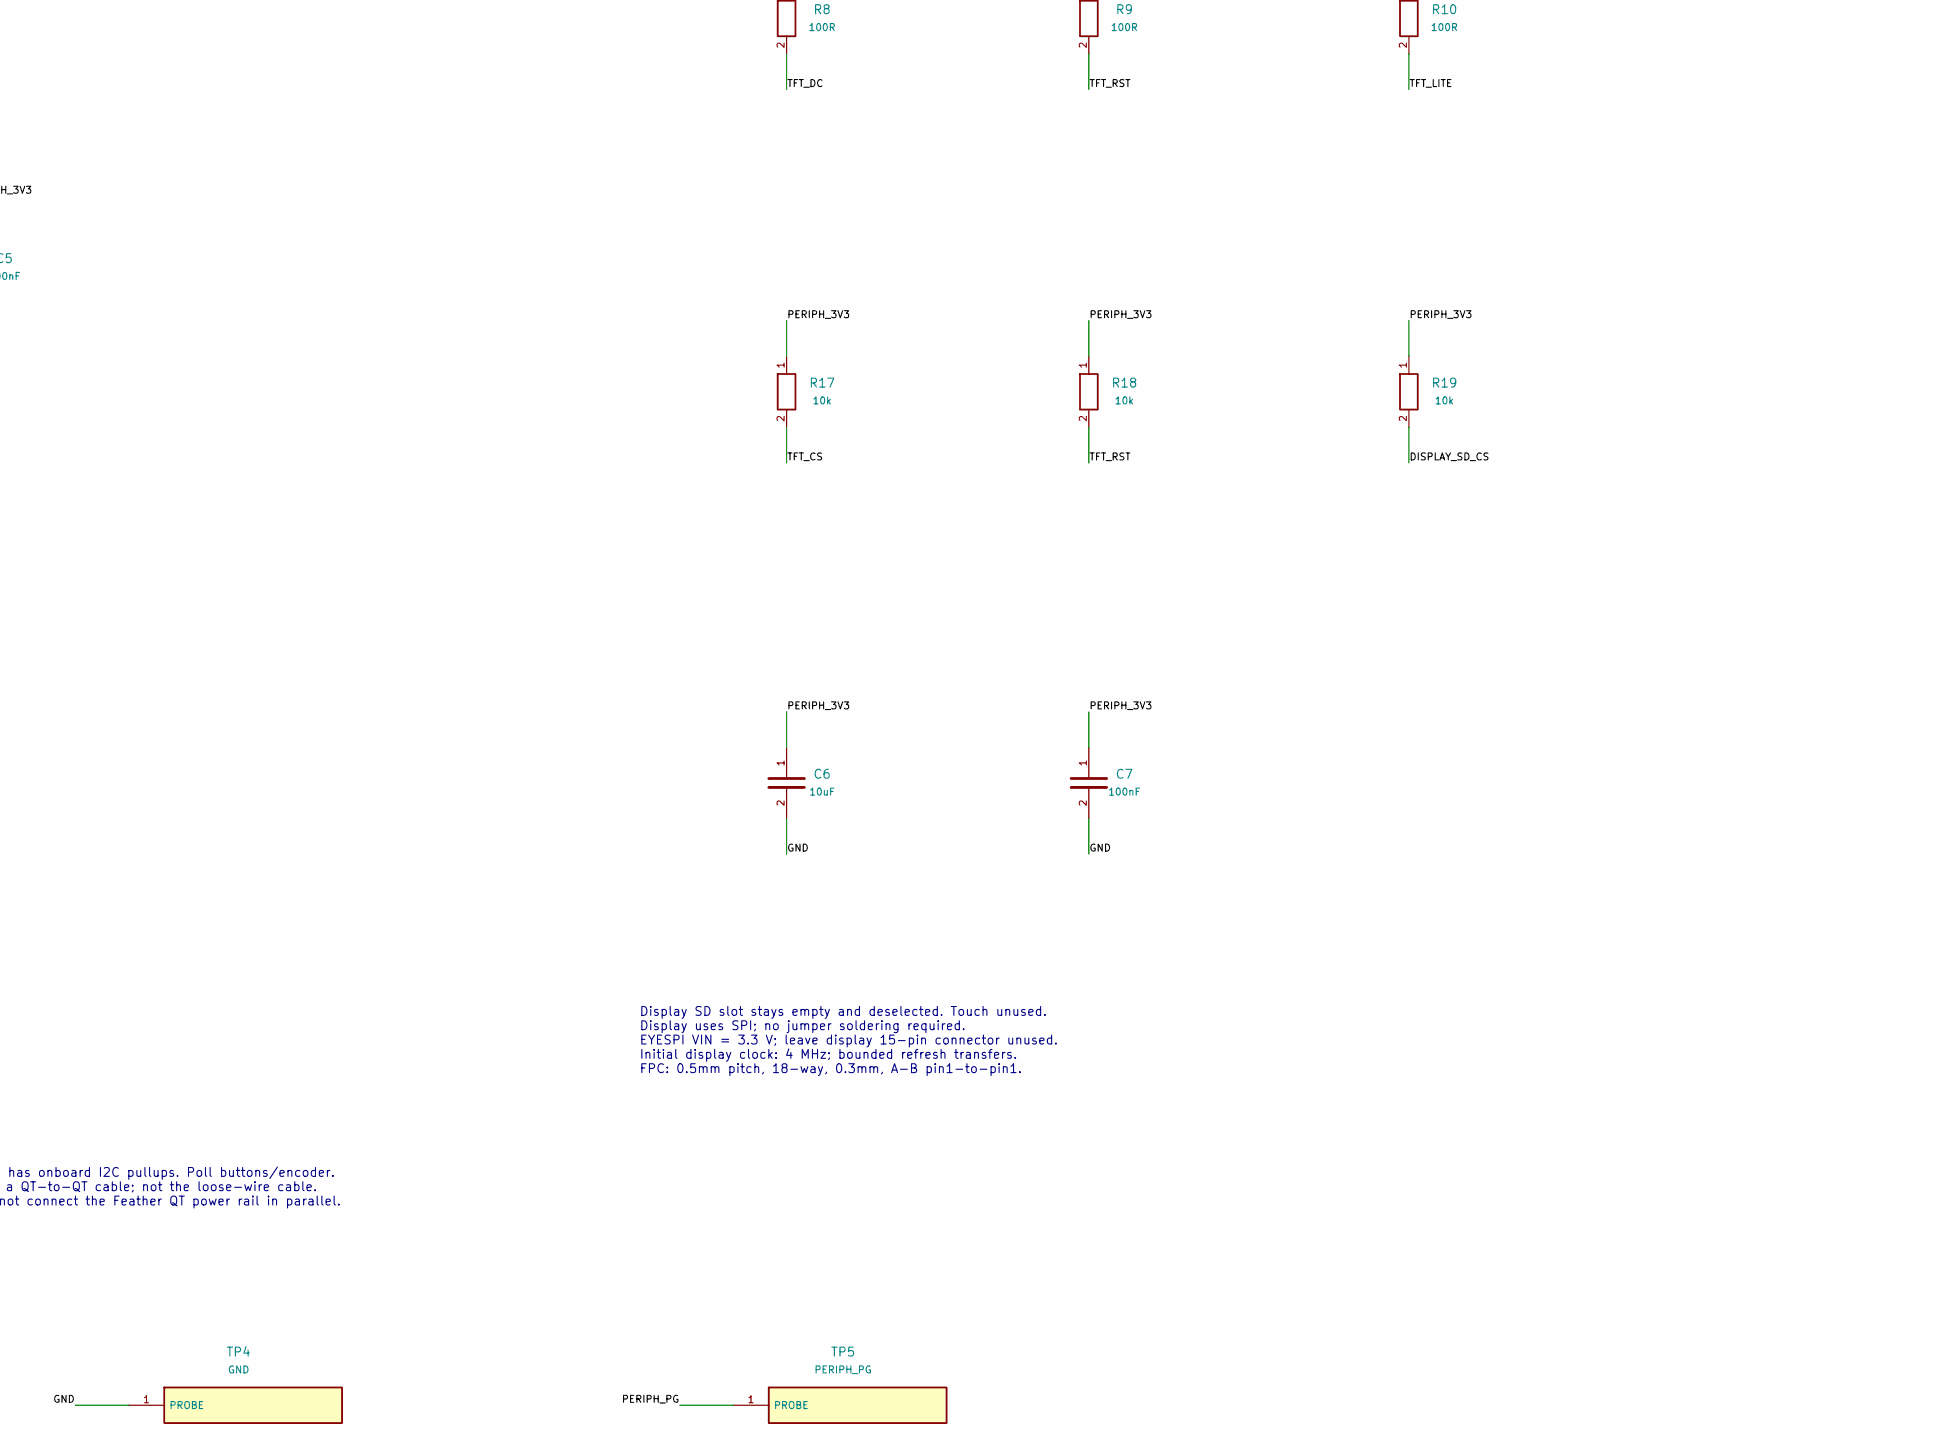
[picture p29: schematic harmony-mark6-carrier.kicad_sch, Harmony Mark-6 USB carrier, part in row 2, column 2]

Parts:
C1, C2: 22uF; C_1210_3225Metric; MPN C3225X7R1C226M250AC
C3, C5, C7: 100nF; C_0805_2012Metric; MPN C0805C104K5RACTU
C4, C6: 10uF; C_0805_2012Metric; MPN C2012X7R1A106K125AC
F1: 0.75A hold PTC; Fuse_1206_3216Metric; MPN MF-NSMF075-2
J1: Feather JP1 socket; PinSocket_1x16_P2.54mm_Vertical; MPN SSW-116-01-G-S
J2: Feather JP3 socket; PinSocket_1x12_P2.54mm_Vertical; MPN SSW-112-01-G-S
J3: EYESPI ribbon; Hirose_FH12-18S-0.5SH_1x18-1MP_P0.50mm_Horizontal; MPN FH12-18S-0.5SH(55)
J4: Dedicated microSD; microSD_HC_Hirose_DM3AT-SF-PEJM5; MPN DM3AT-SF-PEJM5
J5: ANO #6310 cable; JST_SH_SM04B-SRSS-TB_1x04-1MP_P1.00mm_Horizontal; MPN SM04B-SRSS-TB(LF)(SN)
L1: 2.2uH; L_Coilcraft_XxL4020; MPN XFL4020-222MEC
R1, R2, R3, R4, R5, R6, R7, R8, R9, R10: 100R; R_0603_1608Metric; MPN RC0603FR-07100RL
R11, R12, R13, R14, R15, R16: 47k; R_0603_1608Metric; MPN RC0603FR-0747KL
R17, R18, R19: 10k; R_0603_1608Metric; MPN RC0603FR-0710KL
R20, R21: 100k; R_0603_1608Metric; MPN RC0603FR-07100KL
TP1: USB_5V; TestPoint_Pad_D2.0mm
TP2: MCU_3V3; TestPoint_Pad_D2.0mm
TP3: PERIPH_3V3; TestPoint_Pad_D2.0mm
TP4: GND; TestPoint_Pad_D2.0mm
TP5: PERIPH_PG; TestPoint_Pad_D2.0mm
U1: TPS62162DSGR / 3.3V; WSON-8-1EP_2x2mm_P0.5mm_EP0.9x1.6mm_ThermalVias; MPN TPS62162DSGR

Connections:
BUCK_SW: L1.1, U1.7 (SW)
DISPLAY_SD_CS: J3.10 (SD_CS), R19.2
GND: C1.2, C2.2, C3.2, C4.2, C5.2, C6.2, C7.2, J1.13 (GND), J3.3 (GND), J3.MP (SHIELD), J4.6 (VSS), J4.11 (SHIELD), J5.1 (GND), J5.MP (SHIELD), R21.2, TP4.1, U1.1 (PGND), U1.4 (AGND), U1.5 (FB), U1.9 (EP)
I2C_SCL: J2.11 (SCL_GPIO20), J5.4 (SCL)
I2C_SDA: J2.12 (SDA_GPIO22), J5.3 (SDA)
MCU_3V3: J1.15 (3V3_OUT), R16.1, R20.1, R21.1, TP2.1, U1.3 (EN)
PERIPH_3V3: C2.1, C4.1, C5.1, C6.1, C7.1, J3.1 (VIN), J4.4 (VDD), J5.2 (VCC), L1.2, R11.1, R12.1, R13.1, R14.1, R15.1, R17.1, R18.1, R19.1, TP3.1, U1.6 (VOS)
PERIPH_PG: J1.10 (A2_I34), R20.2, TP5.1, U1.8 (PG)
SD_CS: J4.2 (DAT3_CS), R4.2, R13.2
SD_CS_MCU: J1.11 (A1_GPIO25), R4.1
SD_DAT1: J4.8 (DAT1), R14.2
SD_DAT2: J4.1 (DAT2), R15.2
SD_MISO: J4.7 (DAT0_MISO), R3.2, R12.2
SD_MISO_MCU: J1.4 (MISO_GPIO21), R3.1
SD_MOSI: J4.3 (CMD_MOSI), R2.2, R11.2
SD_MOSI_MCU: J1.5 (MOSI_GPIO19), R2.1
SD_SCK: J4.5 (CLK), R1.2
SD_SCK_MCU: J1.6 (SCK_GPIO5), R1.1, R16.2
TFT_CS: J3.9 (TFT_CS), R7.2, R17.2
TFT_CS_MCU: J1.12 (A0_GPIO26), R7.1
TFT_DC: J3.7 (DC), R8.2
TFT_DC_MCU: J2.7 (GPIO33), R8.1
TFT_LITE: J3.2 (LITE), R10.2
TFT_LITE_MCU: J1.7 (A5_GPIO4), R10.1
TFT_MOSI: J3.5 (MOSI), R6.2
TFT_MOSI_MCU: J2.6 (GPIO27), R6.1
TFT_RST: J3.8 (RST), R9.2, R18.2
TFT_RST_MCU: J2.9 (GPIO32), R9.1
TFT_SCK: J3.4 (SCK), R5.2
TFT_SCK_MCU: J2.10 (GPIO14), R5.1
USB_5V: F1.1, J2.3 (USB_VBUS), TP1.1
USB_PROTECTED: C1.1, C3.1, F1.2, U1.2 (VIN)

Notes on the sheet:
HARMONY MARK-6 | USB-FIRST CARRIER | REV A DRAFT
Review schematic. No battery connected. Separate SPI hosts. All carrier components and sockets to be factory assembled.
FEATHER V2 #5900 Numbering follows Adafruit vendor JP1 / JP3.
JP1.14 is NOT a power pin. Leave open. BAT and EN are not connected on this USB-first carrier. GPIO5 keeps its normal high boot strap; SD CLK is an input.
MICROSD | SPI3_HOST
Pull up CMD and DAT0..3 in SPI mode. C4/C5 close to the socket; shield to ground. Initial SD clock: 4 MHz. Card-specific transients need measurement.
3.5-INCH WAVESHARE 29318 / ST7796S | SPI2_HOST
Display SD slot stays empty and deselected. Touch unused. Display uses SPI; no jumper soldering required. EYESPI VIN = 3.3 V; leave display 15-pin connector unused. Initial display clock: 4 MHz; bounded refresh transfers. FPC: 0.5mm pitch, 18-way, 0.3mm, A-B pin1-to-pin1.
USB POWER | SEPARATE PERIPHERAL REGULATOR
U1 EN follows Feather 3V3. PG goes to input-only GPIO34. Keep Feather 3V3 and PERIPH_3V3 separate. Common ground. F1 limits sustained faults; it cannot guarantee device survival. Design allowance: 450mA peripheral load, pending measurement. Use a 5V USB source with >=1A available for full-load test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
CONTROLS | I2C
ANO has onboard I2C pullups. Poll buttons/encoder. Use a QT-to-QT cable; not the loose-wire cable. Do not connect the Feather QT power rail in parallel.

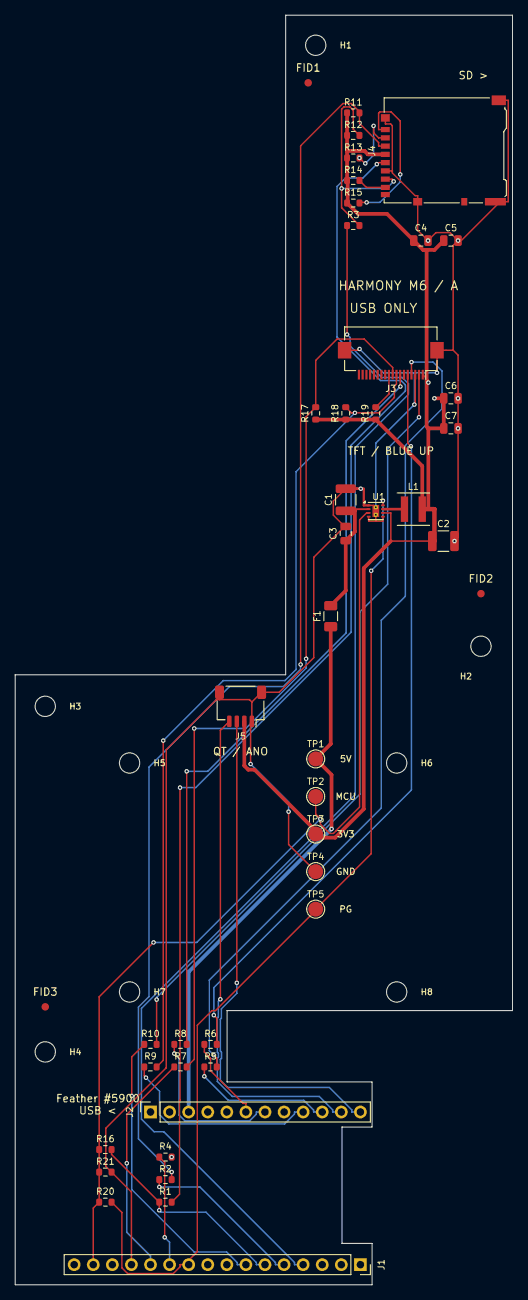
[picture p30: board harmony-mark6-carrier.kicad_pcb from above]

Board: 4 copper layers, 66.2 x 169.0 mm, 52 parts (0 on the bottom side), 32 nets.

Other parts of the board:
FID1, FID2, FID3: Fiducial_1mm_Mask2mm
H1, H2, H3, H4, H5, H6, H7, H8: MountingHole_2.7mm_M2.5

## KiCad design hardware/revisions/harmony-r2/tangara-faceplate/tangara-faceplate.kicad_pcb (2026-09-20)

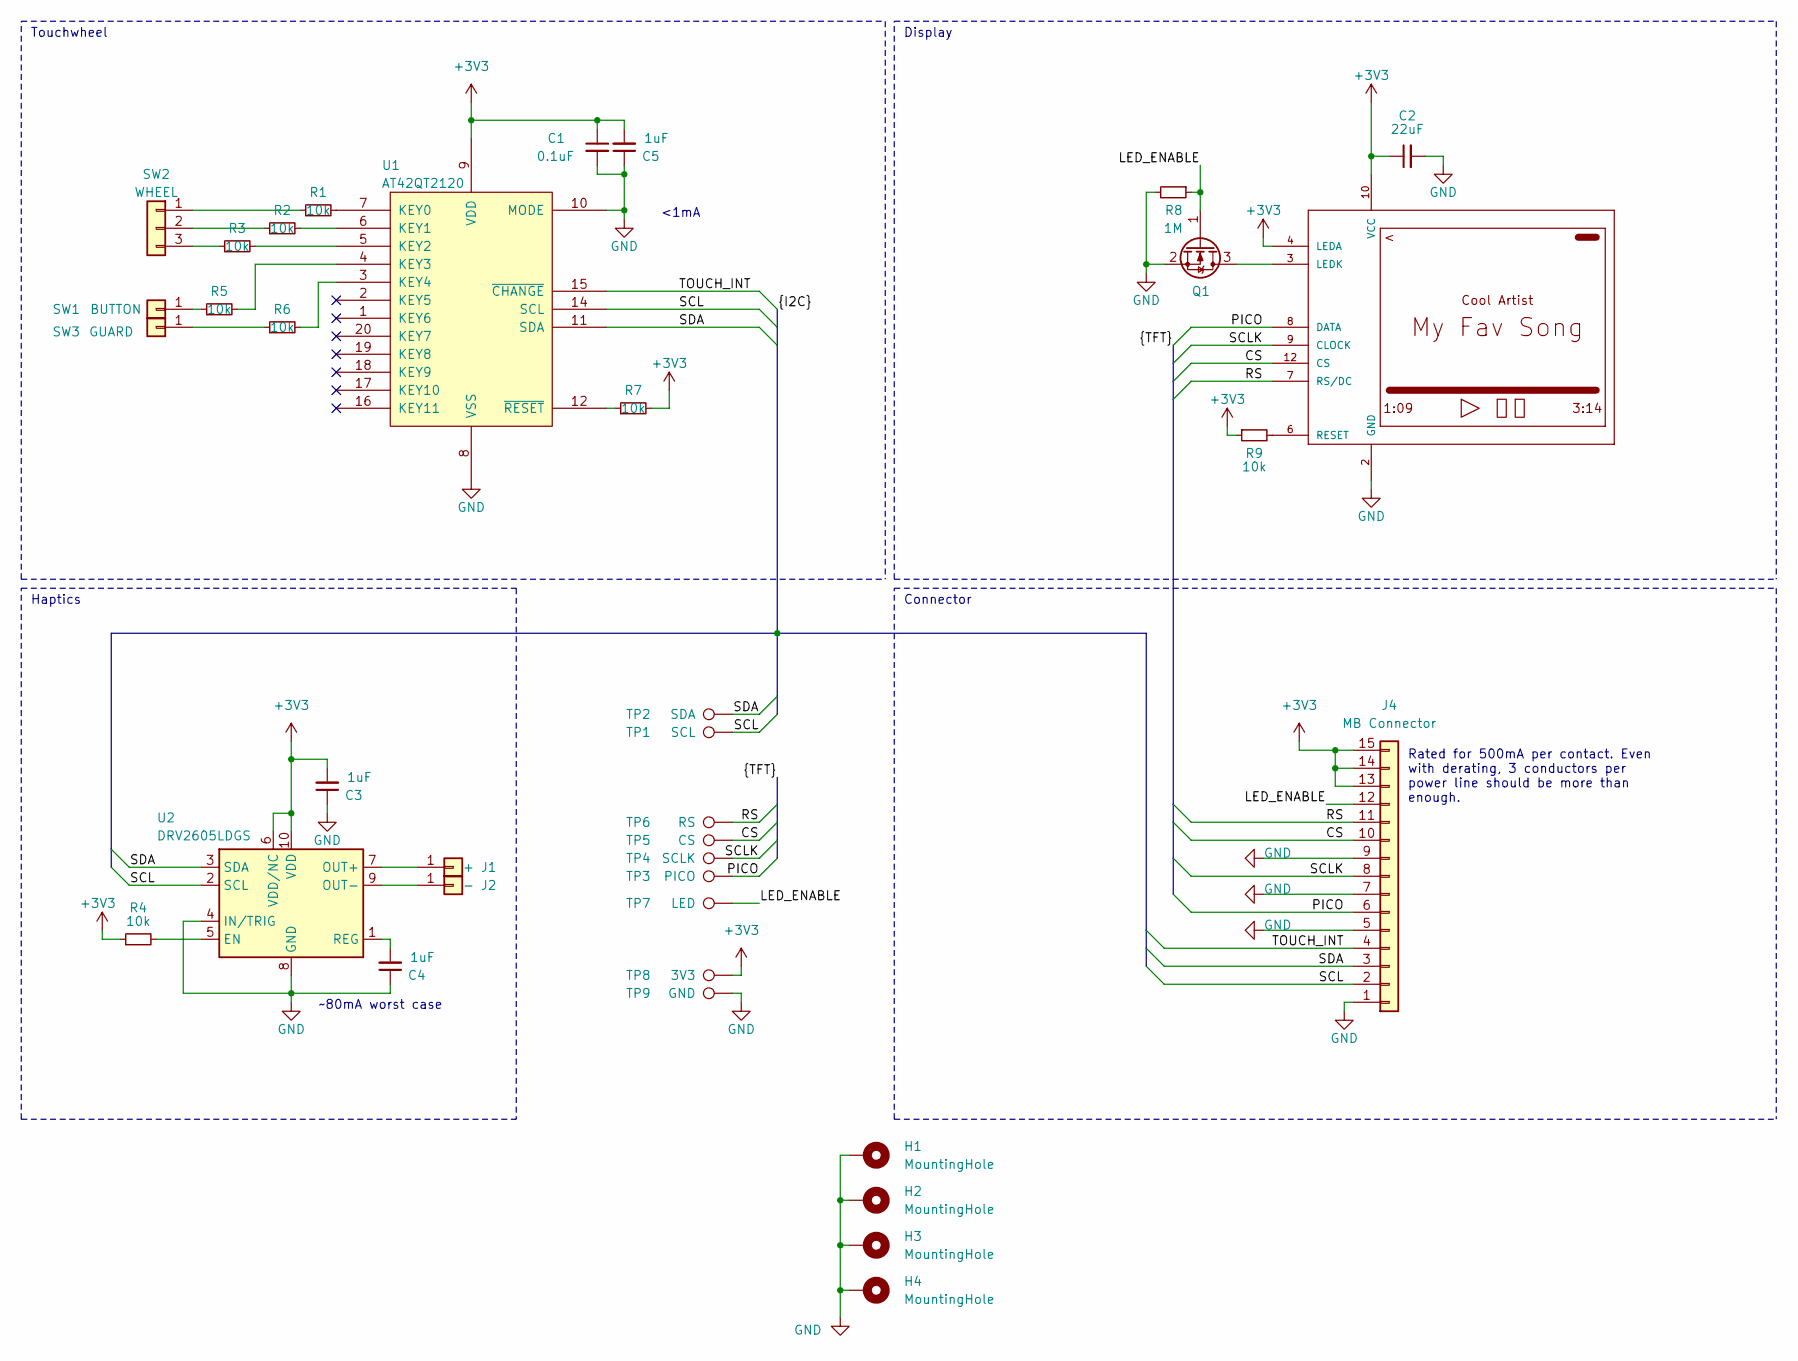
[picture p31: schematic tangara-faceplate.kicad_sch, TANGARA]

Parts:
C1: 0.1uF; C_0603_1608Metric; MPN GCM188R71C104KA37J
C2: 22uF; C_1206_3216Metric; MPN GRM319R61C226KE15D
C3, C4, C5: 1uF; C_0805_2012Metric; MPN GRM216R61C105KA88D
H1, H2, H3, H4: MountingHole; MountingHole_2.2mm_M2_Pad_Via
J1: +; TestPoint_Pad_D1.5mm
J2: -; TestPoint_Pad_D1.5mm
J4: MB Connector; G-Switch GT-F0509SR15-15SMT01; MPN GT-F0509SR15-15SMT01
LCD1: JD-T1800
Q1: PJC138K; SOT-323_SC-70; MPN PJC138K_R1_00001
R1, R2, R3, R4, R5, R6, R7, R9: 10k; R_0603_1608Metric; MPN AC0603JR-0710KL
R8: 1M; R_0603_1608Metric; MPN AC0603FR-131ML
SW1: BUTTON; qtouch-button
SW2: WHEEL; qtouch-wheel
SW3: GUARD; qtouch-guard
TP1: SCL; TestPoint_Pad_D1.0mm
TP2: SDA; TestPoint_Pad_D1.0mm
TP3: PICO; TestPoint_Pad_D1.0mm
TP4: SCLK; TestPoint_Pad_D1.0mm
TP5: CS; TestPoint_Pad_D1.0mm
TP6: RS; TestPoint_Pad_D1.0mm
TP7: LED; TestPoint_Pad_D1.0mm
TP8: 3V3; TestPoint_Pad_D1.0mm
TP9: GND; TestPoint_Pad_D1.0mm
U1: AT42QT2120; VQFN-20-1EP_3x3mm_P0.45mm_EP1.55x1.55mm; MPN AT42QT2120-MMH
U2: DRV2605LDGS; VSSOP-10_3x3mm_P0.5mm; MPN DRV2605LDGST

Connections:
+3V3: C1.1, C2.1, C3.2, C5.2, J4.13, J4.14, J4.15, LCD1.4 (LEDA), LCD1.10 (VCC), LCD1.11 (VCC2), R4.1, R7.2, R9.1, TP8.1, U1.9 (VDD), U2.6 (VDD/NC), U2.10 (VDD)
/CS: J4.10, LCD1.12 (CS), TP5.1
/LED_ENABLE: J4.12, Q1.1 (G), R8.1, TP7.1
/PICO: J4.6, LCD1.8 (DATA), TP3.1
/RS: J4.11, LCD1.7 (RS/DC), TP6.1
/SCL: J4.2, TP1.1, U1.14 (SCL), U2.2 (SCL)
/SCLK: J4.8, LCD1.9 (CLOCK), TP4.1
/SDA: J4.3, TP2.1, U1.11 (SDA), U2.3 (SDA)
/TOUCH_INT: J4.4, U1.15 (~CHANGE)
GND: C1.2, C2.2, C3.1, C4.1, C5.1, H1.1, H2.1, H3.1, H4.1, J4.1, J4.5, J4.7, J4.9, LCD1.2 (GND), LCD1.5 (GND1), LCD1.13 (GND2), Q1.2 (S), R8.2, TP9.1, U1.8 (VSS), U1.10 (MODE), U2.4 (IN/TRIG), U2.8 (GND)
unnamed: J1.1, U2.7 (OUT+)
unnamed: J2.1, U2.9 (OUT-)
unnamed: LCD1.3 (LEDK), Q1.3 (D)
unnamed: LCD1.6 (RESET), R9.2
unnamed: R5.1, SW1.1
unnamed: R1.1, SW2.1
unnamed: R2.1, SW2.2
unnamed: R3.1, SW2.3
unnamed: R6.1, SW3.1
unnamed: R1.2, U1.7 (KEY0)
unnamed: R2.2, U1.6 (KEY1)
unnamed: R3.2, U1.5 (KEY2)
unnamed: R5.2, U1.4 (KEY3)
unnamed: R6.2, U1.3 (KEY4)
unnamed: R7.1, U1.12 (~RESET)
unnamed: R4.2, U2.5 (EN)
unnamed: C4.2, U2.1 (REG)

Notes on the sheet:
Haptics
Touchwheel
~80mA worst case
Connector
Display
Rated for 500mA per contact. Even with derating, 3 conductors per power line should be more than enough.
<1mA

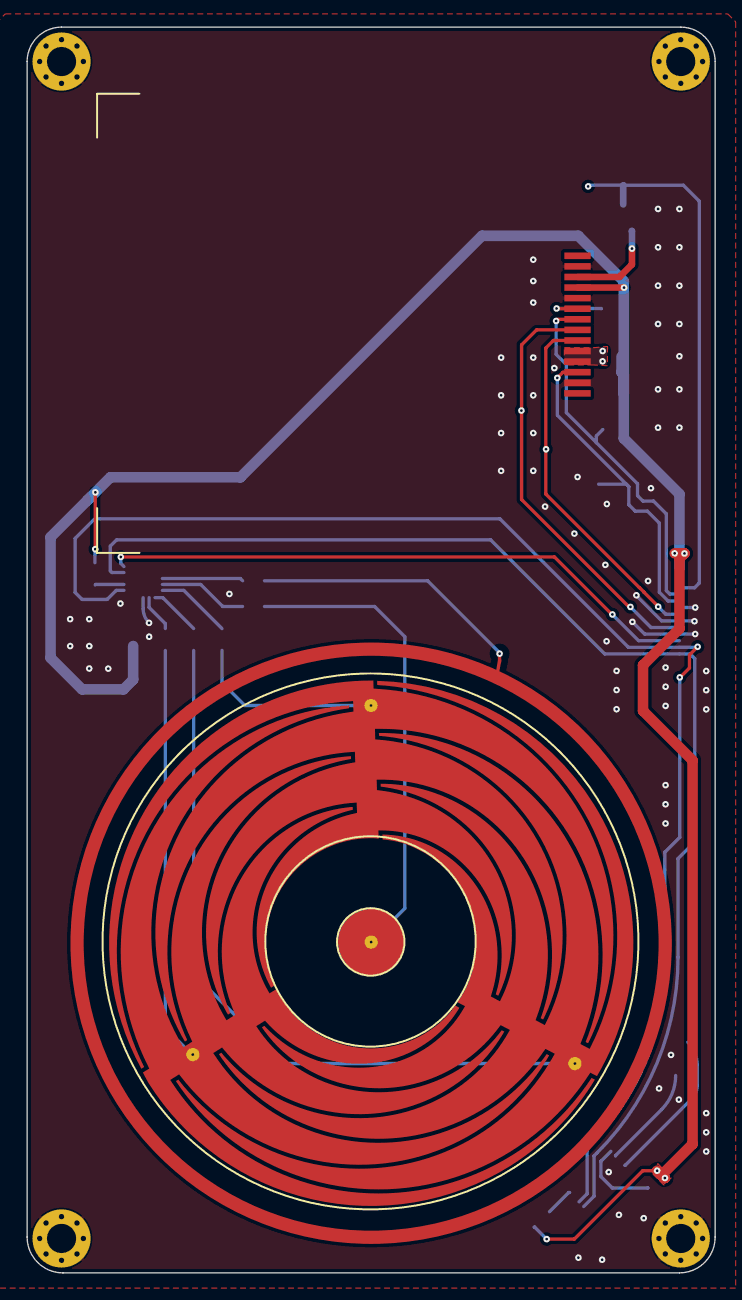
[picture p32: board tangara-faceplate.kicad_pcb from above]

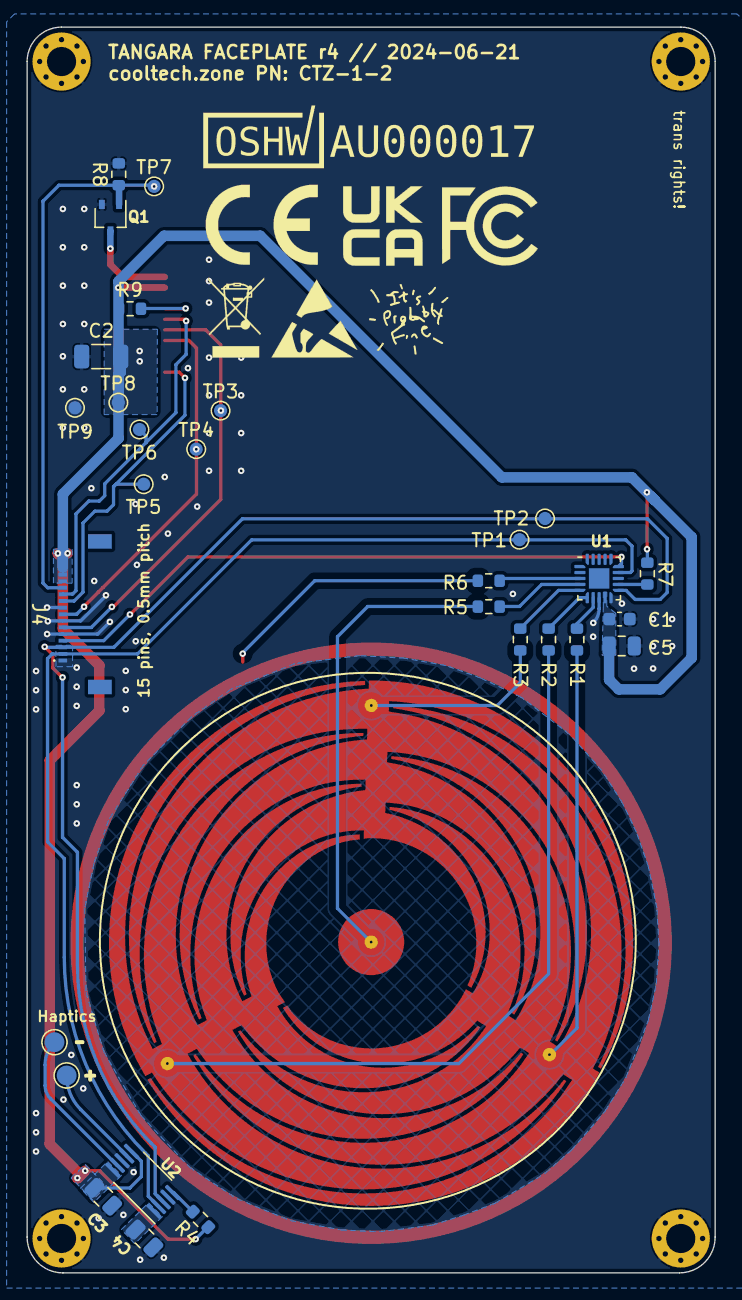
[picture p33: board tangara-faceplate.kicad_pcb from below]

Board: 2 copper layers, 52.0 x 94.2 mm, 39 parts (31 on the bottom side), 27 nets.

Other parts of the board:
kibuzzard-63E31E51: G***; kibuzzard-63E31E51
kibuzzard-63E31E57: G***; kibuzzard-63E31E57

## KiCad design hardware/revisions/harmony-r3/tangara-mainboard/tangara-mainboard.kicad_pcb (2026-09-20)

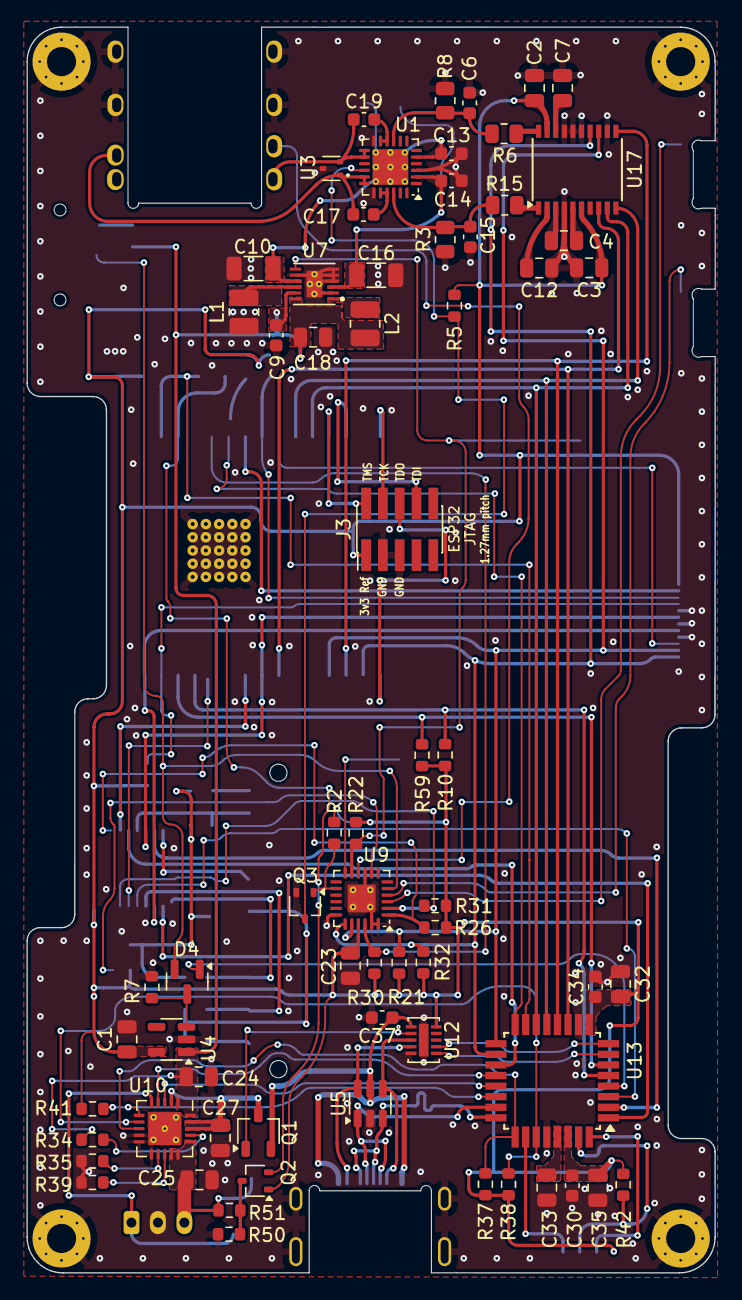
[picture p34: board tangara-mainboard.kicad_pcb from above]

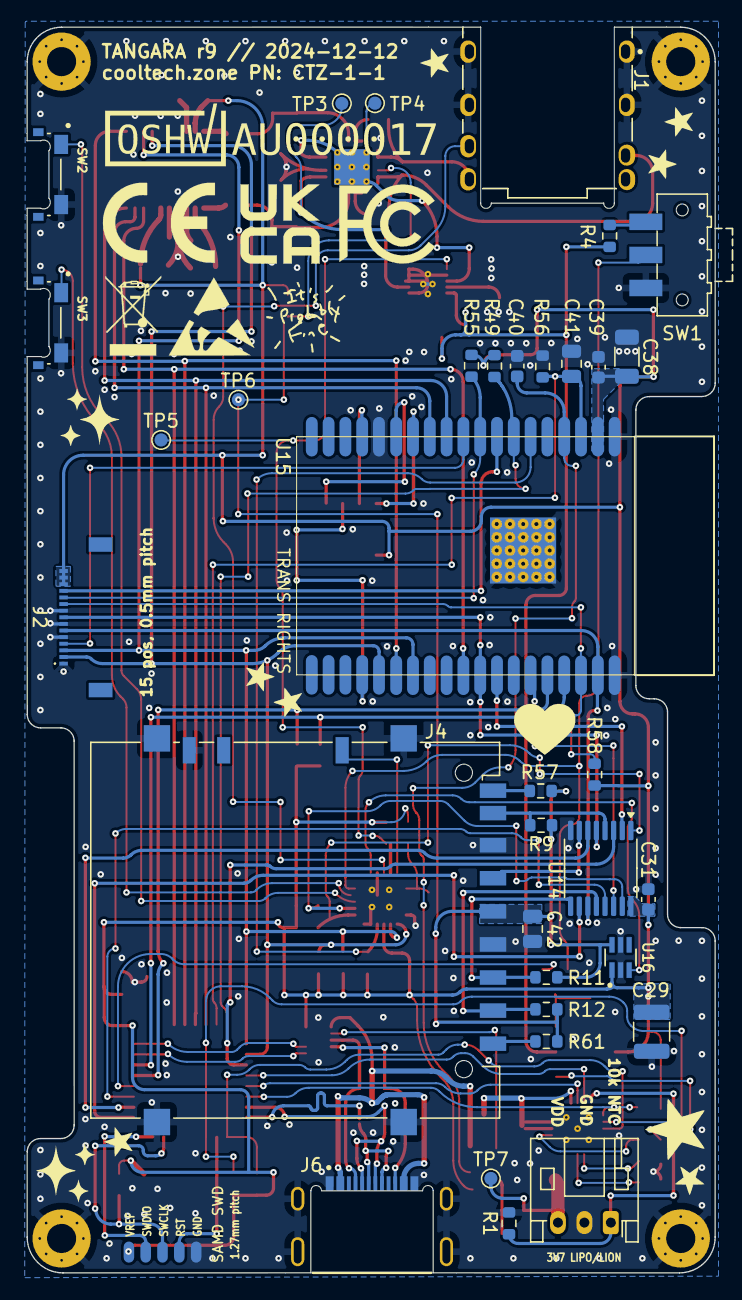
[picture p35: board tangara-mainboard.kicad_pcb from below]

Board: 4 copper layers, 52.0 x 94.2 mm, 106 parts (35 on the bottom side), 92 nets.

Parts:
C1, C2, C3, C7, C18, C24, C25, C27, C32, C35, C42: 10μF; C_0805_2012Metric
C4, C12, C23, C33, C41: 1μF; C_0805_2012Metric
C6, C15: 2700pF; C_0603_1608Metric
C9, C13, C14, C30, C31, C34, C37, C39, C40: 0.1μF; C_0603_1608Metric
C10, C16, C38: 22μF; C_1206_3216Metric
C17, C19: 100pF; C_0603_1608Metric
C29: 100uF; C_1210_3225Metric
D4: BAT54C; SOT-23
H1, H2, H3, H4: MountingHole; MountingHole_2.2mm_M2_Pad_Via2
J1: SJ-3506-SMT; CUI_SJ-3506-SMT
J2: FP Connector; G-Switch GT-F0509SR15-15SMT01
J3: JTAG; PinHeader_2x05_P1.27mm_Vertical_SMD
J4: SD_Card; SD_Hirose_DM1AA_SF_PEJ82
J5: SWD; SAMDSWD
J6: USB; GCT_USB4510-03-1-A_REVA
J7: Battery; JST_PH_S3B-PH-K_1x03_P2.00mm_Horizontal
L1, L2: 4.7μH; L_1008_2520Metric
Q1: PMV48XPA2R; TSOT-23
Q2, Q3: PJC138K; SOT-323_SC-70
R1, R2, R4, R5, R9, R10, R11, R12, R21, R22, R26, R30, R31, R32, R34, R35, R37, R38, R41, R49, R55, R57, R58, R59, R61: 10kΩ; R_0603_1608Metric
R3, R8: 2.2kΩ; R_0805_2012Metric
R6, R15: 560Ω; R_0805_2012Metric
R7, R50, R51, R56: 1MΩ; R_0603_1608Metric
R39, R42: 1kΩ; R_0603_1608Metric
SW1: SW_SPDT; SW_SPDT_CK-JS102011SAQN
SW2, SW3: SW_Push; SW_EVQ-P4HB3B
TP3: +5V; TestPoint_Pad_D1.0mm
TP4: -5V; TestPoint_Pad_D1.0mm
TP5: AMP_EN; TestPoint_Pad_D1.0mm
TP6: AMP_MUTE; TestPoint_Pad_D1.0mm
TP7: BAT; TestPoint_Pad_D1.0mm
U1: INA1620; QFN-24-1EP_4x4mm_P0.5mm_EP2.7x2.7mm_ThermalVias
U3: D5V0L2B3T-7; SOT-523
U4: TLV75533PDBV; SOT-23-5
U5: PE1605C4A6; SOT-23-6
U7: TPS65133; SON40P300X300X80-13N
U9: PCA8575; HVQFN-24-1EP_4x4mm_P0.5mm_EP2.1x2.1mm
U10: MCP73871; QFN-20-1EP_4x4mm_P0.5mm_EP2.5x2.5mm_ThermalVias2
U12: BD91N01NUX; BD91N01NUX-E2
U13: ATSAMD21E18A-AF; TQFP-32_7x7mm_P0.8mm
U14: 74CBTLV3257; TSSOP-16_4.4x5mm_P0.65mm
U15: ESP32-WROVER-E; ESP32-WROVER
U16: TPS22948; SOT65P210X110-6N
U17: WM8523; SSOP-20_4.4x6.5mm_P0.65mm

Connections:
3.5mm_DETECT: J1.4, U9.10 (IO1_0)
+3V3: C1.1, C2.2, C3.1, C23.1, C29.1, C30.1, C31.1, C32.2, C34.1, C35.2, C38.1, C39.1, J2.13, J2.14, J2.15, J3.1 (vRef), J5.1, Q2.1 (G), R2.2, R5.1, R10.1, R21.1, R22.2, R26.1, R30.1, R31.1, R32.1, R37.1, R38.1, R41.1, R42.1, R49.1, R55.1, R58.1, R59.1, U4.5 (OUT), U9.21 (VDD), U12.10 (VDD_IO), U13.9 (VDDANA), U13.30 (VDDIN), U14.16 (VCC), U15.2 (VDD), U16.1 (IN), U17.6 (LINEVDD), U17.19 (AVDD)
+5VA: C14.1, C16.1, TP3.1, U1.2 (V+), U7.3 (VPOS)
-5VA: C10.2, C13.1, TP4.1, U1.5 (V-), U1.25 (EP), U7.9 (VNEG)
/ESP_EN: C41.1, R56.2, U13.15 (PA14), U15.3 (EN)
/JTAG.TCK: J3.4 (TCK), U15.16 (JTAG.TCK)
/JTAG.TDI: J3.8 (TDI), U15.14 (JTAG.TDI)
/JTAG.TDO: J3.6 (TDO), U15.23 (JTAG.TDO)
/JTAG.TMS: J3.2 (TMS), U15.13 (JTAG.TMS)
/Power/NTC: J7.1, R1.1, U10.5 (THERM)
/Power/VBUS_SWITCHED: C27.1, Q1.3 (D), U10.2 (VPCC), U10.18 (IN), U10.19 (IN)
/SWD.RESET: J5.4, U13.26 (~RESET)
/SWD.SWCLK: J5.3, R42.2, U13.31 (SWCLK)
/SWD.SWDIO: J5.2, U13.32 (SWDIO)
/UART.ESP.RX: R10.2, U13.5 (PA04(SERCOM0.0)), U15.34 (UART.RX)
/UART.ESP.TX: R59.2, U13.6 (PA05(SERCOM0.1)), U15.35 (UART.TX)
/~SAMD_INT: R49.2, U13.16 (PA15), U15.7 (I35)
AMP_EN: R22.1, TP5.1, U7.7 (EN), U9.11 (IO1_1)
AMP_MUTE: Q3.3 (D), R5.2, TP6.1, U1.16 (EN)
BAT_LEVEL: C40.2, Q2.2 (S), U15.4 (ADC1_CH0/NOINT)
CHG_PROG: U10.4 (PROG2), U13.20 (PA19)
CHG_SEL: U10.3 (SEL), U13.21 (PA22)
CHG_STAT1: R37.2, U10.8 (STAT1/~LBO), U13.25 (PA27)
CHG_STAT2: R38.2, U10.7 (STAT2), U13.27 (PA28)
DAC.BCK: U13.13 (PA10(I2S/SCK)), U15.11 (I2S.BCK), U17.10 (BCLK)
DAC.DATA: U13.11 (PA08(I2S/SD)), U15.29 (I2S.DOUT), U17.8 (DACDAT)
DAC.LRCK: U13.14 (PA11(IS2/FS)), U15.12 (I2S.LRCK), U17.9 (LRCLK)
DAC.MCK: U13.12 (PA09(I2S/MCK)), U15.25 (BOOT/I2S.SCK), U17.11 (MCLK)
DISPLAY_DR: J2.11, R55.2, U15.9 (IO33)
DISPLAY_LED_EN: J2.12, U15.8 (IO32)
ESP_SPI.DISPLAY_CS: J2.10, R58.2, U15.36 (SPI.CS1)
ESP_SPI.PICO: J2.6, U14.11, U15.37 (SPI.PICO)
ESP_SPI.POCI: U14.2, U15.31 (SPI.POCI)
ESP_SPI.SCLK: J2.8, U14.5, U15.30 (SPI.CLK)
ESP_SPI.SD_CS: U14.14, U15.33 (SPI.CS0)
GND: C1.2, C2.1, C3.2, C6.1, C7.2, C9.2, C10.1, C12.1, C13.2, C14.2, C15.1, C16.2, C18.2, C23.2, C24.2, C25.2, C27.2, C29.2, C30.2, C31.2, C32.1, C33.1, C34.2, C35.1, C37.2, C38.2, C39.2, C40.1, C41.2, C42.2, H1.1, H2.1, H3.1, H4.1, J1.1, J1.5, J1.SH1, J1.SH2, J2.1, J2.5, J2.7, J2.9, J3.3 (GND), J3.5 (GND), J4.3 (VSS), J4.6 (VSS), J4.SH, J4.SW, J5.5, J6.A1_B12 (GND), J6.B1_A12 (GND), J6.S1 (SHELL_GND), J6.S2 (SHELL_GND), J6.S3 (SHELL_GND), J6.S4 (SHELL_GND), J7.2, L1.1, Q3.2 (S), R1.2, R3.1, R7.1, R8.1, R35.2, R39.2, R50.2, R56.1, SW1.1 (A), SW2.2, SW3.2, U1.3 (GND), U1.12, U1.19, U3.3, U4.2 (GND), U5.2 (GND), U7.2 (PGND), U7.4 (GND), U7.5 (AGND), U7.6 (GND), U7.8 (GND), U7.13 (EXP), U9.9 (VSS), U9.18 (A0), U9.23 (A1), U9.24 (A2), U9.25 (EP), U10.9 (~TE), U10.10 (V_{SS}), U10.11 (V_{SS}), U10.21 (V_{SS}), U12.5 (GND), U12.11 (EP), U13.10 (GND), U13.28 (GND), U14.8 (GND), U15.1 (GND), U15.15 (GND), U15.38 (GND), U15.39 (GND), U16.2 (GND), U16.5 (FLT), U17.4 (LINEGND), U17.12 (SDOUT/DEEMPH), U17.15 ({~CS}/{~MUTE}), U17.16 (CIFMODE), U17.17 (AGND)
I2C.SCL: J2.2, R26.2, U9.19 (SCL), U13.18 (PA17(SERCOM3.1)), U15.24 (I2C.SCL), U17.14 (SCLK)
I2C.SDA: J2.3, R21.2, U9.20 (SDA), U13.17 (PA16(SERCOM3.0)), U15.26 (I2C.SDA), U17.13 (SDA)
KEY_LOCK: D4.2, SW1.2 (B), U9.5 (IO0_4)
KEY_VOL_DOWN: SW3.1, U9.4 (IO0_3)
KEY_VOL_UP: SW2.1, U9.3 (IO0_2)
unnamed: C17.2, J1.2, U1.17, U1.18, U3.1
unnamed: C19.2, J1.3, U1.13, U1.14, U3.2
unnamed: J4.1 (CD/DAT3), R12.2, U14.12
unnamed: J4.5 (CLK), U14.7
unnamed: J4.2 (CMD), R11.2, U14.9
unnamed: J4.7 (DAT0), R9.2, U14.4
unnamed: J4.8 (DAT1), R57.2
unnamed: J4.9 (DAT2), R61.2
unnamed: C42.1, J4.4 (VDD), R9.1, R11.1, R12.1, R57.1, R61.1, U16.6 (OUT)
unnamed: J6.A5 (CC1), U5.4 (IO3), U12.3 (CC1)
unnamed: J6.B5 (CC2), U5.6 (IO5), U12.4 (CC2)
unnamed: C25.1, J7.3, R51.1, TP7.1, U10.14 (V_{BAT}), U10.15 (V_{BAT}), U10.16 (V_{BAT_SENSE})
unnamed: Q1.1 (G), U12.2 (SWDRV)
unnamed: Q2.3 (D), R50.1, R51.2
unnamed: Q3.1 (G), R2.1, U9.14 (IO1_4)
unnamed: R4.1, SW1.3 (C)
unnamed: C15.2, R3.2, R15.2, U1.22 (+)
unnamed: C17.1, U1.20, U1.21 (-)
unnamed: C6.2, R6.2, R8.2, U1.9 (+)
unnamed: C19.1, U1.10 (-), U1.11
unnamed: D4.3, R7.2, U4.3 (EN)
unnamed: L1.2, U7.10 (SWN)
unnamed: L2.1, U7.1 (SWP)
unnamed: R34.2, U10.17 (CE)
unnamed: R39.1, U10.13 (PROG1)
unnamed: R35.1, U10.12 (PROG3)
unnamed: C33.2, U13.29 (VDDCORE)
unnamed: R32.2, U9.1 (IO0_0), U14.1 (S)
unnamed: R31.2, U9.2 (IO0_1), U14.15 (~OE)
unnamed: C4.1, U17.5 (CPCA)
unnamed: C4.2, U17.3 (CPCB)
unnamed: C12.2, U17.2 (CPVOUTN)
unnamed: R15.1, U17.1 (LINEVOUTL)
unnamed: R6.1, U17.20 (LINEVOUTR)
unnamed: C7.1, U17.18 (VMID)
SAMD_SPI.CS: U13.3 (PA02), U14.13
SAMD_SPI.PICO: U13.1 (PA00(SERCOM1.0)), U14.10
SAMD_SPI.POCI: U13.19 (PA18(SERCOM1.2)), U14.3
SAMD_SPI.SCLK: U13.2 (PA01(SERCOM1.1)), U14.6
SD_CD: J4.CP, U9.12 (IO1_2)
SYS_POWER: C9.1, C18.1, C24.1, L2.2, R4.2, R34.1, U4.1 (IN), U7.11 (AVIN), U7.12 (PVIN), U10.1 (OUT), U10.20 (OUT)
SYS_PWR_EN_SAMD: D4.1, U13.4 (PA03)
USB.DN: J6.A7 (DN), J6.B7 (DN), U5.1 (IO1), U13.23 (USB.DM)
USB.DP: J6.A6 (DP), J6.B6 (DP), U5.3 (IO2), U13.24 (USB.DP)
USB_TCC0: U12.7 (TCC0), U13.8 (PA07)
USB_TCC1: U12.6 (TCC1), U13.7 (PA06)
VBUS: C37.1, J6.A4_B9 (VBUS), J6.B4_A9 (VBUS), Q1.2 (S), U5.5 (IO4), U12.1 (VBUS)
~CHG_PWR_OK: R41.2, U10.6 (~PG), U13.22 (PA23)
~GPIO_INT: R30.2, U9.22 (~INT), U15.6 (I34)
~SD_VDD_EN: U9.8 (IO0_7), U16.3 (ON)
~TOUCH_INT: J2.4, U15.10 (IO25)

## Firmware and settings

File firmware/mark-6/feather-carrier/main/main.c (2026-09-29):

/*
 * SPDX-FileCopyrightText: 2021-2024 Espressif Systems (Shanghai) CO LTD
 *
 * SPDX-License-Identifier: Unlicense OR CC0-1.0
 */

#include <stdio.h>
#include <stdlib.h>
#include <unistd.h>
#include <string.h>
#include <inttypes.h>
#include "audio_player.h"
#include "player_display.h"
#ifdef HARMONY_PLAYER_UI
#include "player_bluetooth.h"
#endif
#include <stdatomic.h>
#include <strings.h>
#include "freertos/FreeRTOS.h"
#include "freertos/task.h"
#include "freertos/timers.h"
#include "nvs.h"
#include "nvs_flash.h"
#include "esp_system.h"
#include "esp_log.h"

#include "esp_bt.h"
#include "bt_app_core.h"
#include "esp_bt_main.h"
#include "esp_bt_device.h"
#include "esp_gap_bt_api.h"
#include "esp_a2dp_api.h"
#include "esp_avrc_api.h"

/* log tags */
#define BT_AV_TAG             "BT_AV"
#define BT_RC_CT_TAG          "RC_CT"

#ifndef HARMONY_PLAYER_UI
/* device name */
#define LOCAL_DEVICE_NAME     "Harmony Mark-6"

/* AVRCP used transaction label */
#define APP_RC_CT_TL_GET_CAPS            (0)
#define APP_RC_CT_TL_RN_VOLUME_CHANGE    (1)

enum {
    BT_APP_STACK_UP_EVT   = 0x0000,    /* event for stack up */
    BT_APP_HEART_BEAT_EVT = 0xff00,    /* event for heart beat */
};

/* A2DP global states */
enum {
    APP_AV_STATE_IDLE,
    APP_AV_STATE_DISCOVERING,
    APP_AV_STATE_DISCOVERED,
    APP_AV_STATE_UNCONNECTED,
    APP_AV_STATE_CONNECTING,
    APP_AV_STATE_CONNECTED,
    APP_AV_STATE_DISCONNECTING,
};

/* sub states of APP_AV_STATE_CONNECTED */
enum {
    APP_AV_MEDIA_STATE_IDLE,
    APP_AV_MEDIA_STATE_STARTING,
    APP_AV_MEDIA_STATE_STARTED,
    APP_AV_MEDIA_STATE_STOPPING,
};

/*********************************
 * STATIC FUNCTION DECLARATIONS
 ********************************/

/* handler for bluetooth stack enabled events */
static void bt_av_hdl_stack_evt(uint16_t event, void *p_param);

/* avrc controller event handler */
static void bt_av_hdl_avrc_ct_evt(uint16_t event, void *p_param);

/* GAP callback function */
static void bt_app_gap_cb(esp_bt_gap_cb_event_t event, esp_bt_gap_cb_param_t *param);

/* callback function for A2DP source */
static void bt_app_a2d_cb(esp_a2d_cb_event_t event, esp_a2d_cb_param_t *param);

/* callback function for A2DP source audio data stream */
static int32_t bt_app_a2d_data_cb(uint8_t *data, int32_t len);

/* callback function for AVRCP controller */
static void bt_app_rc_ct_cb(esp_avrc_ct_cb_event_t event, esp_avrc_ct_cb_param_t *param);

/* handler for heart beat timer */
static void bt_app_a2d_heart_beat(TimerHandle_t arg);

/* A2DP application state machine */
static void bt_app_av_sm_hdlr(uint16_t event, void *param);

/* utils for transfer BLuetooth Deveice Address into string form */
static char *bda2str(esp_bd_addr_t bda, char *str, size_t size);

/* A2DP application state machine handler for each state */
static void bt_app_av_state_unconnected_hdlr(uint16_t event, void *param);
static void bt_app_av_state_connecting_hdlr(uint16_t event, void *param);
static void bt_app_av_state_connected_hdlr(uint16_t event, void *param);
static void bt_app_av_state_disconnecting_hdlr(uint16_t event, void *param);

/*********************************
 * STATIC VARIABLE DEFINITIONS
 ********************************/

static esp_bd_addr_t s_peer_bda = {0};                        /* Bluetooth Device Address of peer device*/
static uint8_t s_peer_bdname[ESP_BT_GAP_MAX_BDNAME_LEN + 1];  /* Bluetooth Device Name of peer device*/
static atomic_int s_a2d_state = APP_AV_STATE_IDLE;                   /* A2DP global state */
static int s_media_state = APP_AV_MEDIA_STATE_IDLE;           /* sub states of APP_AV_STATE_CONNECTED */
static int s_connecting_intv = 0;                             /* count of heart beat intervals for connecting */
static uint32_t s_pkt_cnt = 0;                                /* count of packets */
static esp_avrc_rn_evt_cap_mask_t s_avrc_peer_rn_cap;         /* AVRC target notification event capability bit mask */
static TimerHandle_t s_tmr;                                   /* handle of heart beat timer */

static const char remote_device_name[] = CONFIG_EXAMPLE_PEER_DEVICE_NAME;
static atomic_uint_least32_t pcm_frames;
static atomic_bool shutdown_requested;

/*********************************
 * STATIC FUNCTION DEFINITIONS
 ********************************/

static char *bda2str(esp_bd_addr_t bda, char *str, size_t size)
{
    if (bda == NULL || str == NULL || size < 18) {
        return NULL;
    }

    sprintf(str, "%02x:%02x:%02x:%02x:%02x:%02x",
            bda[0], bda[1], bda[2], bda[3], bda[4], bda[5]);
    return str;
}

static bool get_name_from_eir(uint8_t *eir, uint8_t *bdname, uint8_t *bdname_len)
{
    uint8_t *rmt_bdname = NULL;
    uint8_t rmt_bdname_len = 0;

    if (!eir) {
        return false;
    }

    /* get complete or short local name from eir data */
    rmt_bdname = esp_bt_gap_resolve_eir_data(eir, ESP_BT_EIR_TYPE_CMPL_LOCAL_NAME, &rmt_bdname_len);
    if (!rmt_bdname) {
        rmt_bdname = esp_bt_gap_resolve_eir_data(eir, ESP_BT_EIR_TYPE_SHORT_LOCAL_NAME, &rmt_bdname_len);
    }

    if (rmt_bdname) {
        if (rmt_bdname_len > ESP_BT_GAP_MAX_BDNAME_LEN) {
            rmt_bdname_len = ESP_BT_GAP_MAX_BDNAME_LEN;
        }

        if (bdname) {
            memcpy(bdname, rmt_bdname, rmt_bdname_len);
            bdname[rmt_bdname_len] = '\0';
        }
        if (bdname_len) {
            *bdname_len = rmt_bdname_len;
        }
        return true;
    }

    return false;
}

static void filter_inquiry_scan_result(esp_bt_gap_cb_param_t *param)
{
    char bda_str[18];
    uint32_t cod = 0;     /* class of device */
    int32_t rssi = -129;  /* invalid value */
    uint8_t *eir = NULL;
    esp_bt_gap_dev_prop_t *p;

    /* handle the discovery results */
    ESP_LOGI(BT_AV_TAG, "Scanned device: %s", bda2str(param->disc_res.bda, bda_str, 18));
    for (int i = 0; i < param->disc_res.num_prop; i++) {
        p = param->disc_res.prop + i;
        switch (p->type) {
        case ESP_BT_GAP_DEV_PROP_COD:
            cod = *(uint32_t *)(p->val);
            ESP_LOGI(BT_AV_TAG, "--Class of Device: 0x%"PRIx32, cod);
            break;
        case ESP_BT_GAP_DEV_PROP_RSSI:
            rssi = *(int8_t *)(p->val);
            ESP_LOGI(BT_AV_TAG, "--RSSI: %"PRId32, rssi);
            break;
        case ESP_BT_GAP_DEV_PROP_EIR:
            eir = (uint8_t *)(p->val);
            break;
        case ESP_BT_GAP_DEV_PROP_BDNAME:
        default:
            break;
        }
    }

    /* search for device with MAJOR service class as "rendering" in COD */
    if (!esp_bt_gap_is_valid_cod(cod) ||
            !(esp_bt_gap_get_cod_srvc(cod) & ESP_BT_COD_SRVC_RENDERING)) {
        return;
    }

    /* search for target device in its Extended Inqury Response */
    if (eir) {
        if (!get_name_from_eir(eir, s_peer_bdname, NULL)) {
            return;
        }
        ESP_LOGI(BT_AV_TAG, "--Name: %s", s_peer_bdname);
        if (strcasecmp((char *)s_peer_bdname, remote_device_name) == 0
#ifdef CONFIG_BENCH_PEER_MAC
            && strcasecmp(bda_str, CONFIG_BENCH_PEER_MAC) == 0
#endif
        ) {
            ESP_LOGI(BT_AV_TAG, "Found a target device, address %s, name %s", bda_str, s_peer_bdname);
            s_a2d_state = APP_AV_STATE_DISCOVERED;
            memcpy(s_peer_bda, param->disc_res.bda, ESP_BD_ADDR_LEN);
            ESP_LOGI(BT_AV_TAG, "Cancel device discovery ...");
            esp_bt_gap_cancel_discovery();
        }
    }
}

static void bt_app_gap_cb(esp_bt_gap_cb_event_t event, esp_bt_gap_cb_param_t *param)
{
    switch (event) {
    /* when device discovered a result, this event comes */
    case ESP_BT_GAP_DISC_RES_EVT: {
        if (s_a2d_state == APP_AV_STATE_DISCOVERING) {
            filter_inquiry_scan_result(param);
        }
        break;
    }
    /* when discovery state changed, this event comes */
    case ESP_BT_GAP_DISC_STATE_CHANGED_EVT: {
        if (param->disc_st_chg.state == ESP_BT_GAP_DISCOVERY_STOPPED) {
            if (atomic_load(&shutdown_requested)) break;
            if (s_a2d_state == APP_AV_STATE_DISCOVERED) {
                s_a2d_state = APP_AV_STATE_CONNECTING;
                ESP_LOGI(BT_AV_TAG, "Device discovery stopped.");
                ESP_LOGI(BT_AV_TAG, "a2dp connecting to peer: %s", s_peer_bdname);
                /* connect source to peer device specified by Bluetooth Device Address */
                esp_a2d_source_connect(s_peer_bda);
            } else {
                /* not discovered, continue to discover */
                ESP_LOGI(BT_AV_TAG, "Device discovery failed, continue to discover...");
                esp_bt_gap_start_discovery(ESP_BT_INQ_MODE_GENERAL_INQUIRY, 10, 0);
            }
        } else if (param->disc_st_chg.state == ESP_BT_GAP_DISCOVERY_STARTED) {
            ESP_LOGI(BT_AV_TAG, "Discovery started.");
        }
        break;
    }
    /* when authentication completed, this event comes */
    case ESP_BT_GAP_AUTH_CMPL_EVT: {
        if (param->auth_cmpl.stat == ESP_BT_STATUS_SUCCESS) {
            ESP_LOGI(BT_AV_TAG, "authentication success: %s", param->auth_cmpl.device_name);
            ESP_LOG_BUFFER_HEX(BT_AV_TAG, param->auth_cmpl.bda, ESP_BD_ADDR_LEN);
        } else {
            ESP_LOGE(BT_AV_TAG, "authentication failed, status: %d", param->auth_cmpl.stat);
        }
        break;
    }
    /* when Legacy Pairing pin code requested, this event comes */
    case ESP_BT_GAP_PIN_REQ_EVT: {
        ESP_LOGI(BT_AV_TAG, "ESP_BT_GAP_PIN_REQ_EVT min_16_digit: %d", param->pin_req.min_16_digit);
        if (param->pin_req.min_16_digit) {
            ESP_LOGI(BT_AV_TAG, "Input pin code: 0000 0000 0000 0000");
            esp_bt_pin_code_t pin_code = {0};
            esp_bt_gap_pin_reply(param->pin_req.bda, true, 16, pin_code);
        } else {
            ESP_LOGI(BT_AV_TAG, "Input pin code: 1234");
            esp_bt_pin_code_t pin_code;
            pin_code[0] = '1';
            pin_code[1] = '2';
            pin_code[2] = '3';
            pin_code[3] = '4';
            esp_bt_gap_pin_reply(param->pin_req.bda, true, 4, pin_code);
        }
        break;
    }

#if (CONFIG_EXAMPLE_SSP_ENABLED == true)
    /* when Security Simple Pairing user confirmation requested, this event comes */
    case ESP_BT_GAP_CFM_REQ_EVT:
        ESP_LOGI(BT_AV_TAG, "ESP_BT_GAP_CFM_REQ_EVT Please compare the numeric value: %06"PRIu32, param->cfm_req.num_val);
        esp_bt_gap_ssp_confirm_reply(param->cfm_req.bda, true);
        break;
    /* when Security Simple Pairing passkey notified, this event comes */
    case ESP_BT_GAP_KEY_NOTIF_EVT:
        ESP_LOGI(BT_AV_TAG, "ESP_BT_GAP_KEY_NOTIF_EVT passkey: %06"PRIu32, param->key_notif.passkey);
        break;
    /* when Security Simple Pairing passkey requested, this event comes */
    case ESP_BT_GAP_KEY_REQ_EVT:
        ESP_LOGI(BT_AV_TAG, "ESP_BT_GAP_KEY_REQ_EVT Please enter passkey!");
        break;
#endif

    /* when GAP mode changed, this event comes */
    case ESP_BT_GAP_MODE_CHG_EVT:
        ESP_LOGI(BT_AV_TAG, "ESP_BT_GAP_MODE_CHG_EVT mode: %d", param->mode_chg.mode);
        break;
    case ESP_BT_GAP_GET_DEV_NAME_CMPL_EVT:
        if (param->get_dev_name_cmpl.status == ESP_BT_STATUS_SUCCESS) {
            ESP_LOGI(BT_AV_TAG, "ESP_BT_GAP_GET_DEV_NAME_CMPL_EVT device name: %s", param->get_dev_name_cmpl.name);
        } else {
            ESP_LOGI(BT_AV_TAG, "ESP_BT_GAP_GET_DEV_NAME_CMPL_EVT failed, state: %d", param->get_dev_name_cmpl.status);
        }
        break;
    /* other */
    default: {
        ESP_LOGI(BT_AV_TAG, "event: %d", event);
        break;
    }
    }

    return;
}

static void bt_av_hdl_stack_evt(uint16_t event, void *p_param)
{
    ESP_LOGD(BT_AV_TAG, "%s event: %d", __func__, event);

    switch (event) {
    /* when stack up worked, this event comes */
    case BT_APP_STACK_UP_EVT: {
        char *dev_name = LOCAL_DEVICE_NAME;
        esp_bt_gap_set_device_name(dev_name);
        esp_bt_gap_register_callback(bt_app_gap_cb);

        esp_avrc_ct_init();
        esp_avrc_ct_register_callback(bt_app_rc_ct_cb);

        esp_a2d_source_init();
        esp_a2d_register_callback(&bt_app_a2d_cb);
        esp_a2d_source_register_data_callback(bt_app_a2d_data_cb);

        /* Avoid the state error of s_a2d_state caused by the connection initiated by the peer device. */
        esp_bt_gap_set_scan_mode(ESP_BT_NON_CONNECTABLE, ESP_BT_NON_DISCOVERABLE);
        esp_bt_gap_get_device_name();

        ESP_LOGI(BT_AV_TAG, "Starting device discovery...");
        s_a2d_state = APP_AV_STATE_DISCOVERING;
        esp_bt_gap_start_discovery(ESP_BT_INQ_MODE_GENERAL_INQUIRY, 10, 0);

        /* create and start heart beat timer */
        do {
            int tmr_id = 0;
            s_tmr = xTimerCreate("connTmr", (10000 / portTICK_PERIOD_MS),
                                 pdTRUE, (void *) &tmr_id, bt_app_a2d_heart_beat);
            xTimerStart(s_tmr, portMAX_DELAY);
        } while (0);
        break;
    }
    /* other */
    default: {
        ESP_LOGE(BT_AV_TAG, "%s unhandled event: %d", __func__, event);
        break;
    }
    }
}

static void bt_app_a2d_cb(esp_a2d_cb_event_t event, esp_a2d_cb_param_t *param)
{
    bt_app_work_dispatch(bt_app_av_sm_hdlr, event, param, sizeof(esp_a2d_cb_param_t), NULL);
}

/* The Bluetooth callback only consumes prepared PCM. */
static int32_t bt_app_a2d_data_cb(uint8_t *data, int32_t len)
{
    if (data && len > 0) atomic_fetch_add(&pcm_frames, len / 4);
    return audio_player_read(data, len);
}

static void bt_app_a2d_heart_beat(TimerHandle_t arg)
{
    /* Formatting diagnostics can exceed the shared timer task's 2 KiB stack. */
    bt_app_work_dispatch(bt_app_av_sm_hdlr, BT_APP_HEART_BEAT_EVT, NULL, 0, NULL);
}

static void bt_app_av_sm_hdlr(uint16_t event, void *param)
{
    if (event == BT_APP_HEART_BEAT_EVT) {
        if (audio_player_snapshot().stopped && !atomic_load(&shutdown_requested)) {
            atomic_store(&shutdown_requested, true);
            audio_player_connected(false);
            esp_bt_gap_cancel_discovery();
        }
        ESP_LOGI(BT_AV_TAG, "BENCH frames=%"PRIu32" heap=%"PRIu32" min_heap=%"PRIu32,
                 atomic_load(&pcm_frames), esp_get_free_heap_size(), esp_get_minimum_free_heap_size());
        audio_player_log();
        ESP_LOGI(BT_AV_TAG, "STACK_FREE_MIN app=%u timer=%u",
                 (unsigned)uxTaskGetStackHighWaterMark(NULL),
                 (unsigned)uxTaskGetStackHighWaterMark(xTimerGetTimerDaemonTaskHandle()));
    }
    ESP_LOGI(BT_AV_TAG, "%s state: %d, event: 0x%x", __func__, s_a2d_state, event);

    /* Also handle late responses after the connection watchdog expires. */
    if (event == ESP_A2D_CONNECTION_STATE_EVT) {
        esp_a2d_cb_param_t *a2d = param;
        if (a2d->conn_stat.state == ESP_A2D_CONNECTION_STATE_CONNECTED) {
            if (shutdown_requested) {
                esp_a2d_source_disconnect(s_peer_bda);
                s_a2d_state = APP_AV_STATE_DISCONNECTING;
                return;
            }
            s_a2d_state = APP_AV_STATE_CONNECTED;
            s_media_state = APP_AV_MEDIA_STATE_IDLE;
            s_connecting_intv = 0;
        } else if (a2d->conn_stat.state == ESP_A2D_CONNECTION_STATE_DISCONNECTED) {
            audio_player_connected(false);
            s_media_state = APP_AV_MEDIA_STATE_IDLE;
            s_a2d_state = APP_AV_STATE_UNCONNECTED;
            s_connecting_intv = 0;
            return;
        }
    }
    /* select handler according to different states */
    switch (s_a2d_state) {
    case APP_AV_STATE_DISCOVERING:
    case APP_AV_STATE_DISCOVERED:
        break;
    case APP_AV_STATE_UNCONNECTED:
        bt_app_av_state_unconnected_hdlr(event, param);
        break;
    case APP_AV_STATE_CONNECTING:
        bt_app_av_state_connecting_hdlr(event, param);
        break;
    case APP_AV_STATE_CONNECTED:
        bt_app_av_state_connected_hdlr(event, param);
        break;
    case APP_AV_STATE_DISCONNECTING:
        bt_app_av_state_disconnecting_hdlr(event, param);
        break;
    default:
        ESP_LOGE(BT_AV_TAG, "%s invalid state: %d", __func__, s_a2d_state);
        break;
    }
}

static void bt_app_av_state_unconnected_hdlr(uint16_t event, void *param)
{
    esp_a2d_cb_param_t *a2d = NULL;
    /* handle the events of interest in unconnected state */
    switch (event) {
    case ESP_A2D_CONNECTION_STATE_EVT:
    case ESP_A2D_AUDIO_STATE_EVT:
    case ESP_A2D_AUDIO_CFG_EVT:
    case ESP_A2D_MEDIA_CTRL_ACK_EVT:
        break;
    case BT_APP_HEART_BEAT_EVT: {
        if (shutdown_requested) {
            break;
        }
        uint8_t *bda = s_peer_bda;
        ESP_LOGI(BT_AV_TAG, "a2dp connecting to peer: %02x:%02x:%02x:%02x:%02x:%02x",
                 bda[0], bda[1], bda[2], bda[3], bda[4], bda[5]);
        esp_a2d_source_connect(s_peer_bda);
        s_a2d_state = APP_AV_STATE_CONNECTING;
        s_connecting_intv = 0;
        break;
    }
    case ESP_A2D_REPORT_SNK_DELAY_VALUE_EVT: {
        a2d = (esp_a2d_cb_param_t *)(param);
        ESP_LOGI(BT_AV_TAG, "%s, delay value: %u * 1/10 ms", __func__, a2d->a2d_report_delay_value_stat.delay_value);
        break;
    }
    default: {
        ESP_LOGE(BT_AV_TAG, "%s unhandled event: %d", __func__, event);
        break;
    }
    }
}
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
void app_main(void)
{
    if (carrier_board_init() != ESP_OK) return;
    if (CONFIG_CARRIER_DISPLAY_ONLY) {
        esp_err_t err = bench_display_init();
        if (err == ESP_OK) err = bench_display_probe();
        ESP_LOGI(BT_AV_TAG, "Display-only write result: %s; visual check required", esp_err_to_name(err));
        return;
    }
    /* Preferences and Bluetooth bonds share NVS; do not erase them on recovery. */
    esp_err_t ret = nvs_flash_init();
#ifdef HARMONY_PLAYER_UI
    if (ret != ESP_OK)
        ESP_LOGE(BT_AV_TAG, "NVS unavailable (%s); preferences cannot be saved", esp_err_to_name(ret));
    if (!audio_player_prepare())
        ESP_LOGE(BT_AV_TAG, "Library unavailable; starting recovery UI");
    audio_player_set_paused(true);
#else
    if (ret == ESP_ERR_NVS_NO_FREE_PAGES || ret == ESP_ERR_NVS_NEW_VERSION_FOUND) {
        ESP_ERROR_CHECK(nvs_flash_erase());
        ret = nvs_flash_init();
    }
    ESP_ERROR_CHECK(ret);
    ESP_LOGI(BT_AV_TAG, "MARK6_FEATHER_ALBUM target=%s playlist=HARMONY/ALBUM.M3U", remote_device_name);
    if (!audio_player_prepare()) {
        ESP_LOGE(BT_AV_TAG, "Audio preparation failed; Bluetooth will remain off");
        return;
    }
#endif
    if (!player_display_start()) {
        audio_player_stop();
        ESP_LOGE(BT_AV_TAG, "Display preparation failed; integration test not started");
        return;
    }
#if CONFIG_CARRIER_CONTROLS_DIAGNOSTIC
    if (carrier_controls_start() != ESP_OK)
        ESP_LOGW(BT_AV_TAG, "ANO controls unavailable; continuing audio/display bench");
#endif
    /*
     * This example only uses the functions of Classical Bluetooth.
     * So release the controller memory for Bluetooth Low Energy.
     */
    ESP_ERROR_CHECK(esp_bt_controller_mem_release(ESP_BT_MODE_BLE));

    esp_bt_controller_config_t bt_cfg = BT_CONTROLLER_INIT_CONFIG_DEFAULT();
    if (esp_bt_controller_init(&bt_cfg) != ESP_OK) {
        ESP_LOGE(BT_AV_TAG, "%s initialize controller failed", __func__);
        return;
    }
    if (esp_bt_controller_enable(ESP_BT_MODE_CLASSIC_BT) != ESP_OK) {
        ESP_LOGE(BT_AV_TAG, "%s enable controller failed", __func__);
        return;
    }

    esp_bluedroid_config_t bluedroid_cfg = BT_BLUEDROID_INIT_CONFIG_DEFAULT();
#if (CONFIG_EXAMPLE_SSP_ENABLED == false)
    bluedroid_cfg.ssp_en = false;
#endif
    if ((ret = esp_bluedroid_init_with_cfg(&bluedroid_cfg)) != ESP_OK) {
        ESP_LOGE(BT_AV_TAG, "%s initialize bluedroid failed: %s", __func__, esp_err_to_name(ret));
        return;
    }

    if (esp_bluedroid_enable() != ESP_OK) {
        ESP_LOGE(BT_AV_TAG, "%s enable bluedroid failed", __func__);
        return;
    }

#if (CONFIG_EXAMPLE_SSP_ENABLED == true)
    /* set default parameters for Secure Simple Pairing */
    esp_bt_sp_param_t param_type = ESP_BT_SP_IOCAP_MODE;
    esp_bt_io_cap_t iocap = ESP_BT_IO_CAP_NONE;
    esp_bt_gap_set_security_param(param_type, &iocap, sizeof(uint8_t));
#endif

    /*
     * Set default parameters for Legacy Pairing
     * Use variable pin, input pin code when pairing
     */
    esp_bt_pin_type_t pin_type = ESP_BT_PIN_TYPE_VARIABLE;
    esp_bt_pin_code_t pin_code;
    esp_bt_gap_set_pin(pin_type, 0, pin_code);

    #ifdef HARMONY_PLAYER_UI
    if (!player_bluetooth_init())
        ESP_LOGE(BT_AV_TAG, "Bluetooth manager failed to start; UI remains available");
    #else
    char bda_str[18] = {0};
    ESP_LOGI(BT_AV_TAG, "Own address:[%s]", bda2str((uint8_t *)esp_bt_dev_get_address(), bda_str, sizeof(bda_str)));
    bt_app_task_start_up();
    /* Bluetooth device name, connection mode and profile set up */
    bt_app_work_dispatch(bt_av_hdl_stack_evt, BT_APP_STACK_UP_EVT, NULL, 0, NULL);
    #endif
}

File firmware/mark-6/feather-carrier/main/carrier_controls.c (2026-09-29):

/* Assembled Adafruit #6310: pinned seesaw register protocol, debounced actions. */
#include <inttypes.h>
#include "carrier_controls.h"
#include "carrier_board.h"
#include "audio_player.h"
#ifdef HARMONY_PLAYER_UI
#include "player_ui.h"
#endif
#include "input_filter.h"
#include "esp_timer.h"
#include "driver/i2c_master.h"
#include "esp_log.h"
#include "freertos/FreeRTOS.h"
#include "freertos/task.h"

#ifndef CONFIG_CARRIER_CONTROLS_ACTIONS
#define CONFIG_CARRIER_CONTROLS_ACTIONS 0
#endif
#ifndef CONFIG_CARRIER_ENCODER_REVERSE
#define CONFIG_CARRIER_ENCODER_REVERSE 0
#endif
static i2c_master_bus_handle_t bus;
static i2c_master_dev_handle_t device;
#define TRY(x) do { esp_err_t e = (x); if (e != ESP_OK) return e; } while (0)

static esp_err_t read_register(uint8_t base, uint8_t reg, uint32_t *value)
{
    if (!carrier_board_ready()) return ESP_ERR_INVALID_STATE;
    const uint8_t address[] = {base, reg};
    uint8_t data[4];
    /* Seesaw needs a STOP and processing delay before the separate read. */
    TRY(i2c_master_transmit(device, address, sizeof(address), 100));
    vTaskDelay(pdMS_TO_TICKS(2));
    TRY(i2c_master_receive(device, data, sizeof(data), 100));
    *value = ((uint32_t)data[0] << 24) | ((uint32_t)data[1] << 16) |
             ((uint32_t)data[2] << 8) | data[3];
    return ESP_OK;
}

#ifdef HARMONY_PLAYER_UI
static void ui_button(player_ui_input_t input)
{
    bool queued = player_ui_input(input, 0);
    ESP_LOGI("ANO", "UI_BUTTON action=%u queued=%d", (unsigned)input, queued);
    if (!queued) ESP_LOGW("ANO", "UI input queue full");
}
#endif

static void controls_task(void *unused)
{
    const char *names[] = {"SELECT", "UP", "LEFT", "DOWN", "RIGHT"};
    uint32_t previous_position = 0, previous_buttons = 0x3e;
    bool first = true;
    uint32_t previous_poll_ms = 0, max_poll_gap_ms = 0;
    input_filter_t filter = {0};
    while (carrier_board_ready()) {
        uint32_t position, buttons;
        esp_err_t err = read_register(0x11, 0x30, &position);
        if (err == ESP_OK) err = read_register(0x01, 0x04, &buttons);
        if (err != ESP_OK) {
            ESP_LOGE("ANO", "Input diagnostic stopped: %s", esp_err_to_name(err));
            break;
        }
        uint32_t now_ms = (uint32_t)(esp_timer_get_time() / 1000);
        uint32_t poll_gap_ms = first ? 0 : now_ms - previous_poll_ms;
        previous_poll_ms = now_ms;
        if (poll_gap_ms > max_poll_gap_ms) max_poll_gap_ms = poll_gap_ms;
        input_events_t events = input_filter_poll(&filter, position, buttons,
            now_ms, CONFIG_CARRIER_ANO_ROTATION);
        if (events.pressed)
            ESP_LOGI("ANO", "DEBOUNCED pressed=0x%02x poll_ms=%" PRIu32 " max_poll_ms=%" PRIu32,
                     events.pressed, poll_gap_ms, max_poll_gap_ms);
        if (CONFIG_CARRIER_CONTROLS_ACTIONS) {
            int steps = events.steps;
            if (CONFIG_CARRIER_ENCODER_REVERSE) steps = -steps;
#ifdef HARMONY_PLAYER_UI
            if (steps && !player_ui_input(PLAYER_UI_SCROLL, steps)) ESP_LOGW("ANO", "UI input queue full");
            switch (events.pressed) {
            case 1U << INPUT_SELECT: ui_button(PLAYER_UI_SELECT); break;
            case 1U << INPUT_UP: ui_button(PLAYER_UI_BACK); break;
            case 1U << INPUT_DOWN: ui_button(PLAYER_UI_PLAY_PAUSE); break;
            case 1U << INPUT_LEFT: ui_button(PLAYER_UI_PREVIOUS); break;
            case 1U << INPUT_RIGHT: ui_button(PLAYER_UI_NEXT); break;
            default: break;
            }
#else
            if (steps) audio_player_browse(steps);
            /* Simultaneous keys are ignored; avoid contradictory actions. */
            switch (events.pressed) {
            case 1U << INPUT_SELECT: audio_player_activate(); break;
            case 1U << INPUT_UP: audio_player_browse(-1); break;
            case 1U << INPUT_DOWN: audio_player_browse(1); break;
            case 1U << INPUT_LEFT: audio_player_step(-1); break;
            case 1U << INPUT_RIGHT: audio_player_step(1); break;
            default: break;
            }
#endif
        }
        if (first || position != previous_position)
            ESP_LOGI("ANO", "RAW_POSITION=%" PRId32, (int32_t)position);
        for (unsigned i = 0; i < 5; ++i) {
            uint32_t mask = 1U << (i + 1);
            if ((buttons ^ previous_buttons) & mask)
                ESP_LOGI("ANO", "%s %s poll_ms=%" PRIu32 " max_poll_ms=%" PRIu32,
                         names[i], buttons & mask ? "released" : "pressed", poll_gap_ms, max_poll_gap_ms);
        }
        first = false;
        previous_position = position;
        previous_buttons = buttons;
#ifdef HARMONY_PLAYER_UI
        /* At a 30 ms poll interval a normal 50–60 ms click could miss the
         * existing 40 ms debounce window. Poll faster without weakening it. */
        vTaskDelay(pdMS_TO_TICKS(5));
#else
        vTaskDelay(pdMS_TO_TICKS(20));
#endif
    }
    i2c_master_bus_rm_device(device);
    i2c_del_master_bus(bus);
    vTaskDelete(NULL);
}

esp_err_t carrier_controls_start(void)
{
    if (!carrier_board_ready()) return ESP_ERR_INVALID_STATE;
    i2c_master_bus_config_t cfg = {.i2c_port = I2C_NUM_0,
        .sda_io_num = CARRIER_I2C_SDA, .scl_io_num = CARRIER_I2C_SCL,
        .clk_source = I2C_CLK_SRC_DEFAULT, .glitch_ignore_cnt = 7,
        .flags.enable_internal_pullup = false};
    TRY(i2c_new_master_bus(&cfg, &bus));
    i2c_device_config_t dev = {.dev_addr_length = I2C_ADDR_BIT_LEN_7,
        .device_address = 0x49, .scl_speed_hz = 100000};
    esp_err_t err = i2c_master_bus_add_device(bus, &dev, &device);
    if (err != ESP_OK) { i2c_del_master_bus(bus); return err; }
    uint32_t version = 0;
    err = read_register(0x00, 0x02, &version);
    if (err == ESP_OK && (version >> 16) != 5740) err = ESP_ERR_INVALID_VERSION;
    /* Input mode, pull enabled, then pull-up for seesaw pins 1..5. */
    const uint8_t registers[] = {0x03, 0x0b, 0x05};
    for (unsigned i = 0; i < sizeof(registers) && err == ESP_OK; ++i) {
        const uint8_t cmd[] = {0x01, registers[i], 0, 0, 0, 0x3e};
        err = i2c_master_transmit(device, cmd, sizeof(cmd), 100);
        vTaskDelay(pdMS_TO_TICKS(2));
    }
    if (err == ESP_OK && xTaskCreatePinnedToCore(controls_task, "ano_diag", 3072,
                                               NULL, 3, NULL, 0) != pdPASS)
        err = ESP_ERR_NO_MEM;
    if (err != ESP_OK) { i2c_master_bus_rm_device(device); i2c_del_master_bus(bus); }
    return err;
}

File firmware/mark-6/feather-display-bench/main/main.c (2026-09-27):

#include <inttypes.h>
#include <stdio.h>
#include "ano_bench.h"
#include "sd_bench.h"
#include "bench_display.h"
#include "carrier_board.h"
#include "input_filter.h"
#include "driver/gpio.h"
#include "esp_log.h"
#include "esp_timer.h"
#include "freertos/FreeRTOS.h"
#include "freertos/task.h"

static esp_err_t line(int y,const char *text)
{
    char padded[39];
    snprintf(padded,sizeof padded,"%-38.38s",text);
    return bench_display_text(8,y,padded,0xffff,0);
}
static void show_error(const char *where,esp_err_t err)
{
    char text[39];
    snprintf(text,sizeof text,"%s: %s",where,esp_err_to_name(err));
    ESP_LOGE("ANO_BENCH","%s",text);
    (void)line(440,text);
}
void app_main(void)
{
    ESP_LOGI("LCD_BENCH","LCD, QT rotary and read-only SD bench; no touch or radios");
    esp_err_t err=carrier_board_init();
    if(err!=ESP_OK){ESP_LOGE("LCD_BENCH","Identity/capacity check failed; outputs disabled");return;}
    err=sd_bench_mount();
    if(err!=ESP_OK){ESP_LOGE("SD_BENCH","SD mount failed: %s; no LCD traffic",esp_err_to_name(err));return;}
    err=bench_display_init_on_existing_bus();
    if(err==ESP_OK) err=bench_display_probe();
    if(err!=ESP_OK){gpio_set_level(CARRIER_TFT_LITE,0);return;}
    err=ano_bench_init();
    if(err!=ESP_OK){show_error("Rotary init",err);return;}
    if((err=line(180,"ROTARY CONNECTED"))!=ESP_OK){show_error("Display",err);return;}
    err=sd_bench_verify_start();
    if(err!=ESP_OK){show_error("SD inventory",err);return;}
    bool sd_done=false;
    unsigned sd_percent=101;
    const char *names[]={"CENTER","UP","LEFT","DOWN","RIGHT"};
    const unsigned logical[]={INPUT_SELECT,INPUT_UP,INPUT_LEFT,INPUT_DOWN,INPUT_RIGHT};
    unsigned counts[5]={0};
    input_filter_t filter={0};
    uint32_t origin=0,last_position=0;
    uint8_t last_stable=0;
    bool first=true;
    unsigned heartbeats=0;
    for(;;){
        if(!sd_done){
            unsigned percent;
            err=sd_bench_verify_step(&sd_done,&percent);
            if(err!=ESP_OK){show_error("SD verify",err);return;}
            if(sd_done || percent!=sd_percent){
                char status[39];
                snprintf(status,sizeof status,sd_done?"SD PASS: 45 tracks; song checksum OK":"SD: 45 tracks; checking song %u%%",percent);
                if((err=line(440,status))!=ESP_OK){show_error("Display",err);return;}
                sd_percent=percent;
            }
        }
        uint32_t position,buttons;
        err=ano_bench_read(&position,&buttons);
        if(err!=ESP_OK){show_error("Rotary read",err);return;}
        if(first) origin=position;
        input_events_t events=input_filter_poll(&filter,position,buttons,
            (uint32_t)(esp_timer_get_time()/1000),0);
        char text[39];
        if(first || position!=last_position){
            snprintf(text,sizeof text,"WHEEL: %" PRId32,(int32_t)(position-origin));
            if((err=line(210,text))!=ESP_OK){show_error("Display",err);return;}
            ESP_LOGI("ANO_BENCH","POSITION=%" PRId32 " delta=%d",(int32_t)(position-origin),events.steps);
        }
        for(unsigned i=0;i<5;i++){
            if(events.pressed & (1U<<logical[i])) ++counts[i];
            bool changed=((filter.stable^last_stable)&(1U<<i))!=0;
            if(first || changed){
                bool down=(filter.stable&(1U<<i))!=0;
                snprintf(text,sizeof text,"%-6s %-4s count=%u",names[i],down?"DOWN":"UP",counts[i]);
                if((err=line(250+28*i,text))!=ESP_OK){show_error("Display",err);return;}
                ESP_LOGI("ANO_BENCH","%s %s count=%u",names[i],down?"pressed":"released",counts[i]);
            }
        }
        if(first){
            if((err=line(410,"Turn wheel; press all five buttons"))!=ESP_OK){show_error("Display",err);return;}
            ESP_LOGI("ANO_BENCH","READY_FOR_INPUT");
        }
        first=false;last_position=position;last_stable=filter.stable;
        if(++heartbeats%200==0) ESP_LOGI("ANO_BENCH","Input polling active");
        vTaskDelay(pdMS_TO_TICKS(20));
    }
}

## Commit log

2025-11-22 update spec for album/artist/track number etc
2025-11-22 Implemented CS5.5 hierarchical library with drilldown and optional PC directory loading.
    - Core navigation refactor: core/player_app.py now drives a Library → Artists → Albums → Tracks drilldown, with per-level selection, back/left stepping up, track selection starting
    playback and auto-jumping to Now Playing, and play/pause within track lists. Added root-aware highlighting updates and safer handling of unknown metadata.
    - Library indexing: new core/library.py builds artist/album indexes with fallback “Unknown” labels and stable track sorting.
    - Models updated: Track now carries artist, album, track_number (optional), and PlayerState tracks root/library selection levels.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
2025-11-22 prototype hardware dev board details
2025-11-22 split prototype phases to use wroom for now, wrover when it arrives, etc
2025-11-22 prototype 1 hardware task list
2025-11-22 first wiring diagram
2026-09-20 Wrap: verify Harmony Mark-5 album playback (HARMONY-16)
    Add bench player, album preparation and loading tools, pinned drivers and tests. Record accepted audio artifacts, hardware lessons and pending full-album endurance.
2026-09-20 Preserve Harmony hardware designs and firmware validation records
    [Case.FCStd, assembly.step, audio.kicad_sch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]
2026-09-21 Record Mark-5 cold-start recheck (HARMONY-16)
    Sep 20 re-run of the album test on the connected board: reached PLAYER_READY
    and paused on track 1 with six decoder seconds. Not acceptance evidence; the
    uninterrupted full-album check remains outstanding. Clean shutdown unconfirmed
    because the host closes the port before PLAYER_STOPPED, and the verification
    port open caused a power-on reset.
2026-09-25 Wrap: prepare Harmony Mark-6 for delivered-parts fit check (HARMONY-17)
    Preserve Bluetooth evidence, carrier design, enclosure and album firmware.
    Record verified software results, procurement and next-session hardware limits.
    [3.5inch Capacitive Touch LCD.dwg, 3.5inch_Capacitive_Touch_LCD.step, 5400 ESP32 Feather V2.step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]
2026-09-26 Prepare Mark-6 mechanical revision and fit trial (HARMONY-17)
    [ano-spacer-14mm.step, assembled-ano.stl, assembled-display.stl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]
2026-09-26 Prepare and send carrier supplier quote package (HARMONY-17)
    [assembly-bom.csv, assembly-positions.csv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]
2026-09-26 Record PCBWay carrier review submission (HARMONY-17)
2026-09-26 Add Feather diagnostic and record flash failure; render carrier (HARMONY-17)
    [main.c]
2026-09-26 Record flash voltage clue and pending foam check (HARMONY-17)
2026-09-27 Run standalone Feather LCD probe; await visual check (HARMONY-17)
2026-09-27 Add LCD rotary input test and detect ANO board (HARMONY-17)
2026-09-27 Record successful rotary and button check (HARMONY-17)
2026-09-27 Play SD music over Bluetooth on Feather bench; fix contention silence (HARMONY-17)
    [partitions.csv]
2026-09-27 Build interactive desktop player UI prototype (HARMONY-17)
2026-09-27 Bring music tree UI to Feather and fix input scheduling (HARMONY-17)
    [bench_display.c, carrier_controls.c]
2026-09-27 Track full Mark-6 UI scope and preserve Mark-7 visual reference (HARMONY-18)

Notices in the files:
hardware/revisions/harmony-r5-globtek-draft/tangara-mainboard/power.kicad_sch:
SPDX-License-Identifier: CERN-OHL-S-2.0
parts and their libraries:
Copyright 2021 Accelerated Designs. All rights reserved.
